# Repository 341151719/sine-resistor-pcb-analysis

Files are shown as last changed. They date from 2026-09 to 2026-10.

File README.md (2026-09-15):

# 正弦电阻 / Active Acoustic Impedance Controller

这是 PCB 修正、SPICE 分析和故障排查的审计仓库。仓库的目的，是让每次
电路修改、仿真假设和判断都能通过 Git 提交记录追溯；它不是已经通过生产
签核的最终硬件发布包。

## 先看什么

0. [新板从验收到初步改板操作手册](新板从验收到初步改板操作手册.md)：按新板版本确认、断电检查、基本上电、固件编写/烧录、问题复现和可逆改板的顺序执行。
1. [2026-09-15 实验还原证据复核](实验还原部分/主动审计/EVIDENCE_REASSESSMENT_20260915.md)：修正峰值电流与持续CC混淆，同步H07/H08状态，补充较大启动扰动验证。
2. [V8 KiCad 修正版](KICAD部分/正弦电阻V8_KiCad10.0.4_稳定性修正版_2026-09-04/)
   及其 [修改说明](KICAD部分/正弦电阻V8_KiCad10.0.4_稳定性修正版_2026-09-04/RELEASE_NOTES_V8.md)。
3. [V7 加工基线](KICAD部分/给厂商的板子加工数据/正弦电阻V7_KiCad10.0.4_校正转换版/)。
4. [SPICE 验证报告](SPICE部分/VALIDATION_REPORT_20260904.md) 和
   [实际问题记录](实际遇到的问题/)。
5. [故障假设排查总表](故障假设排查_20260908/假设总表.md)：H01–H11 记录
   单一加工/参数错误审计；H12 新增 OPA548 E/S–R5 组合动态机制审计。
6. [实验还原与可复现证据](实验还原部分/)：实板实验记录、早期错误复现和
   对既有 SPICE/KiCad 检查盲区的主动审计。

## 当前诊断状态（2026-09-08）

后续状态更新（2026-09-15）：H07修正版的3个固定偏置案例均完成且未复现目标，但不覆盖上电过程；
H08修正版未复现，但使用V8的C27值。OPA ON案例的约69 mA峰值不构成持续70 mA CC验证。
以下段落保留2026-09-08的模型结论，具体有效性以最新证据复核和更新后的假设总表为准。

官方 OPA548/OPA1656 模型在正确的 PSpice 兼容设置下可以运行。H12 进一步
解除此前“OPA548 固定 OFF”的假设，并加入 R10/TLP185、有限 E/S 状态和
J1/PGND 非理想项。23 组机制扫描没有自然产生 100--110 kHz；但当 OPA548
进入 ON 时，全官方模型出现约 453 kHz 的 U4B–R5–OPA548 组合模态，且把
R5 近似拆除后该模态消失。TP8 只有约 56 µVpp，因此仍不能解释实板上
100--110 kHz、超过 10 Vpp 的目标波形。H01–H11 的单点排查结论保持不变；
“本模型未复现”不等于已排除实物器件损坏、多故障叠加或未建模动态。

## 目录

| 目录 | 内容 |
|---|---|
| `KICAD部分/` | V7/V8 原理图、PCB、封装表、加工输出和验证记录 |
| `SPICE部分/` | SPICE 源模型、网表、脚本和历史验证报告 |
| `实际遇到的问题/` | 实测现象、局部网表和根因判定计划 |
| `故障假设排查_20260908/` | 每个假设独立存档的预测、deck、log 和审查 |
| `实验还原部分/` | 经整理的实板记录、可运行复现 deck 和主动审计脚本 |

## 复现约定

仿真通常使用 ngspice-42；TI PSpice 宏模型需要 `set ngbehavior=ps`，并且
某些官方模型需要显式 `TEMP`。每个故障目录都记录了实际命令和模型限制。
历史网表中可能保留当时机器的绝对路径，这是审计记录的一部分；在新机器
上运行前应根据目录位置调整 `.include` 路径。`.dat` 波形文件和环境安装包
没有纳入 Git，它们可由网表重新生成，避免仓库膨胀。

## 版本纪律

V7 目录作为原始加工基线保留；V8 是当前修正版工作状态，不应在没有新的
验证记录时覆盖。请用独立提交记录新的板改动、仿真假设和结论，并在
`CHANGELOG.md` 中补充面向人的摘要。

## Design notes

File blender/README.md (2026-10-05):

# V8 PCB Blender 模型与渲染

本目录提供从当前 KiCad V8 工程自动生成的 Blender 场景、脚本和渲染图。

## 输出文件

- [`output/c11_35_v8_pcb_model.blend`](output/c11_35_v8_pcb_model.blend)：可在 Blender 5.2.1 中打开的场景，包含等距相机和正视相机。
- [`output/c11_35_v8_pcb_isometric.png`](output/c11_35_v8_pcb_isometric.png)：整体等距渲染。
- [`output/c11_35_v8_pcb_top.png`](output/c11_35_v8_pcb_top.png)：正视工程布局渲染。
- [`generate_v8_pcb_scene.py`](generate_v8_pcb_scene.py)：可重复运行的生成脚本。

## 数据来源

脚本读取：

1. `KICAD部分/正弦电阻V8_KiCad10.0.4_稳定性修正版_2026-09-04/project.kicad_pcb`
   - Edge.Cuts 板框；
   - F.Cu 走线；
   - 板厚和坐标。
2. `.../audit/cpl_smt.csv`
   - 73 个贴装件的位号、位置、旋转角、正反面和封装。

本次生成结果：

- 板框：约 `116.332 mm × 112.522 mm`；
- SMT 元件：73 个；
- F.Cu 线段：715 条。

## 精度边界

这是工程可读的程序化模型，不是制造级 3D 封装模型：

- 板框、元件位置和走线来自当前 KiCad 文件；
- 电阻、电容、IC、连接器等实体使用按封装尺寸的近似几何；
- 没有把外部供应商 STEP/WRL 模型伪装成精确模型；
- 为了在渲染中看清，铜线宽度按 `VISUAL_TRACE_SCALE=1.45` 做了视觉放大，不应拿渲染图测量实际线宽；
- 当前工程文件的 `cpl_smt.csv`/BOM 仍记录 `R10=100kΩ`、`C27=10pF`，而 [V8 发布说明](../KICAD部分/正弦电阻V8_KiCad10.0.4_稳定性修正版_2026-09-04/RELEASE_NOTES_V8.md) 写的是 `R10=6.8kΩ`、`C27=10nF`。本模型忠实显示当前 KiCad/CPL 文件内容，不能作为“V8 参数已同步”的证明。

## 重新生成

在仓库根目录执行：

```bash
PROJECT_ROOT="$PWD" \
BLENDER_OUT="$PWD/blender/output" \
/path/to/blender --background --python blender/generate_v8_pcb_scene.py
```

脚本默认使用 Blender Eevee，输出 `.blend`、等距图和正视图。若从其他目录运行，设置 `PROJECT_ROOT` 指向仓库根目录即可。

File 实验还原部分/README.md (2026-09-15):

# 实验还原与可复现证据

本目录保存已经整理过、能够追溯到 KiCad 拓扑或 SPICE 运行结果的实验材料。
它不宣称已经找到实板 100–110 kHz 振荡的唯一物理根因。

## 建议阅读顺序

0. [`../新板从验收到初步改板操作手册.md`](../新板从验收到初步改板操作手册.md)：面向新板操作者的完整流程，包含版本确认、断电检查、数字域、固件/烧录、模拟上电、问题复现和可逆改板。
1. [`主动审计/EVIDENCE_REASSESSMENT_20260915.md`](主动审计/EVIDENCE_REASSESSMENT_20260915.md)：最新证据纠正、平均/峰值电流复核、较大启动扰动测试和仍待确认的物理根因。
2. [`实板实验记录.md`](实板实验记录.md)：按实际排查顺序区分有效测量、
   作废测量、已否定假设和仍待闭环的问题。
3. [`早期错误复现/`](早期错误复现/)：复现 R10/E/S 裕量、错误示波器接地
   和 OPA ON 后的电流后果，同时保留“健康模型不能产生 105 kHz”的阴性基线。
4. [`主动审计/`](主动审计/)：解释旧 SPICE 为什么可能漏检状态型错误，并提供
   网表 lint、制造数据交叉检查和 H07/H08 修正模型。
5. [`../故障假设排查_20260908/H12_OPA548_ES_R5动态耦合/`](../故障假设排查_20260908/H12_OPA548_ES_R5动态耦合/)：
   E/S–R5 动态耦合的正式假设记录和 23 组扫描。

## 证据分级

| 项目 | 状态 | 可以得出的结论 |
|---|---|---|
| V7 R10=100 kΩ 与并联 10 kΩ | 定量复现 | 官方宏模型的 0.614 V 与实测 0.55–0.65 V 相符，说明关断裕量风险真实存在 |
| 示波器地夹接 TP8 | 强等效复现 | 该接法会把 U4B 输出重载，因此对应波形和增流数据必须作废 |
| 已存在 105 kHz 时 OPA ON | 高频负载电流复现，CC 未复现 | 2 Vpk 输入的正轨峰值约 69 mA，平均仅约 23.6 mA；模型没有台式电源限流环路，不能据此判定持续 70 mA CC |
| 健康 OPA1656/OPA548 基线 | 阴性结果 | 当前模型不会自然产生实板的数伏级 100–110 kHz |
| H12 的约 453 kHz 模态 | 模型内阳性、目标阴性 | 证明 R5 可参与组合动态，但频率和 TP8 幅值都不匹配实板，不能视为根因复现 |

## 未纳入 Git 的来源材料

原始 ZIP、可再生 `.dat` 波形、补丁副本和完整对话导出没有纳入 Git：前两类会
重复或膨胀仓库；补丁已经作为正式提交应用；对话中包含被后续纠正的过渡判断、
临时路径和重复回答，不适合作为技术结论。它们保存在仓库外的本地原始归档中。

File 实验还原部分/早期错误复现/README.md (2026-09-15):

# 正弦电阻 V7：早期实验错误的 KiCad/SPICE 复现

日期：2026-09-09

证据纠正：2026-09-15，见 [重新审查报告](../主动审计/EVIDENCE_REASSESSMENT_20260915.md)。旧日志保留历史数值，新 deck 增加平均电流测量。

## 结论概览

这套测试区分“设计/测量错误能够复现”和“105 kHz 根因尚不能自然复现”。

| 项目 | 当前结论 | 关键数字 |
|---|---|---|
| V7 R10=100k 的 OPA548 E/S 关断裕量问题 | **定量复现** | 100k -> E/S-V- = 3.4786 V；9.09k -> 0.6140 V；6.8k -> 0.4634 V |
| J1 在约 +/-2.5 V 附近突然增流 | **最小官方模型未复现** | R10=100k 的简单 DC J1 sweep 没出现 70 mA 级突变 |
| OPA ON 后约 70 mA CC | **CC 尚未复现，只复现高频负载电流** | 2 Vpk/105k：正轨峰值约 69 mA，平均约 23.6 mA；缺少台式电源动态 |
| 示波器 GND 黑夹误接 TP8 | **等效故障强复现** | TP8 2.020 V -> 4.46 mV；U4B 正轨电流 3.95 mA -> 93.0 mA |
| OPA OFF、TP7 干净、TP8 数伏级 100–110 kHz | **尚未自然复现** | 健康官方模型 late TP8 = 0 Vpp；H12 V7-like 动态模型是约 453 kHz、TP8 55.7 uVpp |

## 1. KiCad 静态复核

`kicad_static_extract.py` 直接读取 V7/V8 的 `project.kicad_pcb`。

V7：

- R10 = 100kR，pad1 = OPA_ES，pad2 = PWR_N；
- R5 = 100R，连接 VCMD -> OPA_IN_P；
- U1 = OPA548F/500，pin7 = OPA_ES；
- U4 = OPA1656IDR，pin5 = MUL_RAW(TP7侧)，pin7 = VCMD(TP8)；
- U7 = TLP185，输出跨 PWR_P / OPA_ES。

V8：

- 唯一与本问题最直接相关的改变之一是 R10 变成 6.8kR；
- R5/U1/U4/U7 的上述网络关系保持不变。

注意：KiCad ERC/DRC 不会因为 `100k` 在 E/S 上“功能裕量不够”而自动报错。这属于器件行为/参数设计问题，需要 SPICE 或手工 datasheet margin check。

## 2. R10/E-S 关断问题：官方 OPA548 宏模型定量复现

文件：`01_r10_es_sweep.cir`

运行结果：

- R10=100k：`V(ES)-V(V-) = 3.478609 V`
- R10=9.0909k（100k || 10k）：`0.614035 V`
- R10=6.8k：`0.463396 V`

9.09k 的结果和实板记录的约 0.55–0.65 V 高度一致。

因此，这一项可以称为“SPICE 对早期实板问题的定量复现”。

## 3. J1 低压附近突增流：简单模型没有复现

文件：`01b_j1_sweep_r10_100k.cir`

用 R10=100k，J1 从 +/-1 V 扫到 +/-5 V。最小 OPA548 官方宏模型没有在 +/-2.5 V 附近出现 70 mA 级的突然电流跃迁。

这意味着实板当时的突然增流不能仅归结为“R10=100k + 一个空载 OPA548 DC 模型”。还需要板级负载、输入异常、E/S 动态、供电状态或其它实际条件。

适用性限制：OPA548 推荐供电最低为 ±4 V；上述 ±1～±3 V 点属于范围外探索，不能用其阴性结果排除实板低压异常。

## 4. OPA ON 后高频取电：峰值和持续 CC 必须分开

文件：`02_opa_on_105k_amp{1,2,3,4}V.cir`

这里把实板后来观测到的高频 VCMD 当作已经存在的条件，检查 OPA548 打开后的瞬时与平均取电。模型不包含电源限流控制，不能直接判定 CC。

| 105k 输入幅值 | OPA548 输出 Vpp | +轨峰值取电 | -轨峰值取电 |
|---:|---:|---:|---:|
| 1 Vpk | 2.073 Vpp | 37.8 mA | 37.2 mA |
| 2 Vpk | 4.111 Vpp | 69.1 mA | 68.7 mA |
| 3 Vpk | 6.140 Vpp | 101.0 mA | >100 mA |
| 4 Vpk | 7.209 Vpp | 132.1 mA | >100 mA |

2026-09-15 复跑 2 Vpk 案例：正/负轨平均取电约 23.62/23.48 mA，远低于其 69.14/68.75 mA 峰值。原先将这一峰值当成持续 70 mA CC 的解释，证据不足。

真实供电还包含 C5/C6=470 µF、线缆和台式电源控制环路。高频瞬时电流与电源显示/限流响应不能等同。新 deck 输出 `IP_DRAW_AVG`、`IN_DRAW_AVG`；这些平均值也只适用于当前理想电源模型，不能反过来证明实板绝不会 CC。

## 5. 错误示波器接地：强复现

文件：`03_scope_ground_short.cir`

用 TI 官方 OPA1656、R15=1k、R16=39k，把正常高阻探头与“TP8 被 50 mOhm 接地”做 A/B。

### 正常

- TP8 = 2.0196 V
- U4B +10 V rail 电流约 3.95 mA

### 示波器 GND 黑夹接 TP8 的等效情况

- TP8 = 4.46 mV，几乎被强制接地
- U4B +10 V rail 电流约 93.0 mA

因此实验里“接错探头之后 J2 电流从约 20 mA 上升到约 70 mA”完全符合这种测量人为重载机制。具体数字不要求一模一样，因为实板 J2 还给其它器件供电。

## 6. 核心 100–110 kHz：仍不能诚实地说已经复现

文件：`04_healthy_baseline.cir`

官方 OPA1656 + OPA548，R15=1k、R16=39k、R5=100R、OPA548 E/S 固定 OFF，只有一次 1mV startup kick：

- 10084 transient rows；
- late TP8_PP = 0 V；
- 没有持续 100–110 kHz。

此前 H12 动态 E/S 模型在 V7-like R10=100k、OPA548 实际 ON 条件下能够出现一个 R5 依赖的组合模态，但它是：

- 约 453.3 kHz；
- OPA548 OUT ≈ 0.140 Vpp；
- TP8 ≈ 55.7 uVpp。

它既不是 105 kHz，也不是实板的“OPA OFF、TP8 数伏级”。因此不能把它冒充根因复现。

曾经用 MOhm 级 U4 pin6 接触故障可以把 SPICE 调到约 105 kHz，但实测 pin6 到反馈节点约 20 mOhm，已经把这种模型否定，因此不应作为有效复现。

## 7. 如何运行

需要 ngspice 42，并让当前目录的 `.spiceinit` 生效。进入本目录后可运行单个
deck：

```bash
ngspice -b 01_r10_es_sweep.cir
ngspice -b 03_scope_ground_short.cir
ngspice -b 04_healthy_baseline.cir
```

也可以一次运行全部案例：

```bash
./run_all.sh
```

若 ngspice 不在 `PATH`，可使用 `NGSPICE=/绝对路径/ngspice ./run_all.sh`。
TI 模型放在 `models/`；新日志和 `.dat` 写入被 Git 忽略的 `results/`。

## 8. 当前 KiCad CLI 限制

本轮 V7/V8 KiCad 工程文件可以直接读取和静态审计，但没有重新执行
`kicad-cli ERC/DRC`。项目中已有 KiCad 10.0.4 的 ERC/DRC 结果；本报告涉及的
R10/R5/U1/U4/U7 拓扑是直接从 `project.kicad_pcb` 重新提取的。

## 9. 解释边界

`02_opa_on_105k_amp*.cir` 有意施加 105 kHz，只用于验证已经存在该波形时的
功率级电流后果。只有 `04_healthy_baseline.cir` 用于检查电路能否从一次启动
扰动中自行产生持续振荡；它的结果为阴性。两类 deck 不得混用。

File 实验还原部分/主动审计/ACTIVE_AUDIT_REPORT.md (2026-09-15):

# 正弦电阻项目：类似 R10 漏检问题的主动审计

## 结论摘要

之前 SPICE 没有发现 V7 R10=100 kΩ 的 E/S 风险，根本原因不是求解器错误，而是测试模型把关键状态预先设成了“确定 OFF”：多个基线 deck 使用理想电压源把 E/S 固定为 V-+0.6 V，或者用被动 OFF surrogate 代替 OPA548。R10/TLP185/E/S 阈值本身不在被验证系统中，因此该问题不可能被这些 deck 发现。

本次主动审计确认以下同类问题/风险：

1. **CONFIRMED / HIGH — H07/H08 OPA548 供电节点断链。**
   两个 deck 建立了 `PWR_P/PWR_N` 的 J1/PDN，但 OPA548 实例使用 `VPLUS/VMINUS`；原 deck 中没有把这两组节点连接起来，也没有给 VPLUS/VMINUS 独立供电。因此注释声称建模的 J1/OPA548 供电耦合实际上没有进入 OPA548。
2. **CONFIRMED / HIGH — H07/H08 基线 C27 仍为 10 pF。**
   V8 PCB/release 已是 10 nF。105 kHz 下两者容抗约相差 1000 倍，因此旧 H07/H08 不能作为 V8 的高频电源耦合 sign-off。
3. **CONFIRMED / PROCESS — V8 `audit/` 中间制造数据已过时，但最终 release 正确。**
   中间 audit CSV 仍可看到 R10=100 kΩ、C27=10 pF、旧 C16/R12 信息；最终 `release/V8_2026-09-04/assembly` 已正确同步。对最终 73 个 SMT 元件做 PCB↔BOM↔CPL 全量交叉检查，value/footprint/XY/rotation/side 共 0 个不一致。风险是仓库存在多个“看似可下单”的 source of truth。
4. **CONFIRMED / DESIGN-SIGNOFF — R10=6.8 kΩ 的“最坏条件”表述不成立。**
   OPA548 数据表的 E/S LOW 电流 -70 µA 位于 TYP 栏，而非 MAX 栏。6.8 kΩ 是明显优于 100 kΩ 的改进，但不能用 70 µA 声称获得 datasheet worst-case guarantee。还需要同时验证 TLP185 关断漏电和开启 CTR 对 OFF/ON 两边裕量的影响。
5. **KNOWN STATE DEPENDENCY — J5 需要外部跨接。**
   J5 的 1/2/3 脚分别是 VK_MCU/VK/VK_EXT，不内部短接。默认必须 1–2 跨接；否则关键 VK 节点可能浮空。这类问题不会被假设 VK 已驱动的 SPICE 捕获。
6. **KNOWN STATE DEPENDENCY — PB8/BOOT0 依赖 option bytes。**
   V8 没有给 PB8/BOOT0 增加硬件强下拉，release note 要求生产编程并回读 OPTR 0xFBEFF8AA。ERC/DRC/SPICE 都无法证明实际烧录状态正确。
7. **MODEL-LIMITATION — OPA548 官方宏模型不足以代表真实 shutdown 高频动态。**
   宏模型使用阈值开关表达 E/S 状态；数据表则给出典型 1 µs disable、3 µs enable，并明确提示 shutdown 器件在 >20 kHz 信号下可能增加 leakage。因此“官方宏模型 OFF 时稳定”不能单独排除实板 105 kHz 下的 OFF-state 非线性。
8. **PROCESS — 13 个 fault deck/include 把 E/S 硬固定在 V-+0.6 V；11 个用理想 ±5 V J1；14 个使用本机绝对 include 路径。**
   前两项限制了物理覆盖面，后一项降低可复现性。
9. **PROCESS — V8 release gate 的 ERC 条件是“与转换基线 436 项一致”，不是 ERC=0。**
   这是对 EasyEDA 转换噪声的务实处理，但意味着 ERC 目前不是一个干净的新电气错误报警器。

## H07/H08 修正后的复跑

修正内容：
- OPA548 `VMINUS/VPLUS` → `PWR_N/PWR_P`；
- E/S 和 ILIM 引用负轨同步改为 PWR_N；
- C27 10 pF → 10 nF；
- 仅为当前 Linux ngspice 环境修正模型 include 路径。

### H08

- C15=100 nF nominal：TP8_PP=0；OPA548 OUT_PP≈3.16e-4 V。
- C15=10 nF：同样稳定。
- C15≈open：同样稳定。

因此 H08 的定性结论“仅漏掉 U4 正轨局部 C15 不足以复现 105 kHz”在修正后仍成立。

### H07

- 原修正deck用PWL让四路理想电源同时从0 V上升；10 Ω点在未供电宏模型的初始求解中止。
- 单故障假设声明的是固定J2=±10 V、J1=±5 V。改用固定偏置后，RAPS=3.5586 mΩ/1 Ω/10 Ω均完成约0.5 ms瞬态。
- 三例TP8晚段均0 Vpp；U4+终值约9.998/9.990/9.920 V。

因此 H07 现在支持“在固定偏置和当前宏模型中，该聚合串联高阻没有产生目标振荡”。
它不覆盖上电顺序和实际电源限流，也不能把聚合RAPS定位到具体FB1、铜路或焊点。

## 建议把检查体系改成五道 gate

1. **KiCad electrical source-of-truth**：读取最终 `.kicad_pcb/.kicad_sch`，生成唯一 net/value manifest。
2. **Manufacturing parity**：每次 release 自动比较 PCB↔BOM↔CPL 的 value、footprint、XY、rotation、side；中间 `audit/` 文件不得作为下单入口。
3. **SPICE netlist lint**：检查控制脚是否被硬钳、供电节点是否断链、V8 manifest 与 deck 元件值是否漂移、绝对 include 路径。
4. **State matrix**：E/S OFF/undefined/ON、J5 jumper 缺失/正确、J1 ramp/current-limit、probe loading 等必须单独列成状态维度，不能只做“单元件 fault matrix”。
5. **Model adequacy declaration**：每个 deck 明确列出“真实建模 / surrogate / 固定假设 / 未建模”的物理机制。只有这样，`not reproduced` 才能解释为“在这些机制内被排除”，而不是“硬件问题不存在”。

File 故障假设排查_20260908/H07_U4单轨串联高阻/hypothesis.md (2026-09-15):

# H07 — U4 正电源串联路径高阻（单一故障）

**当前状态纠正**：以下为原始断链模型的历史结果。后续修正 OPA548 供电节点，
并将该单故障测试改回其声明的固定±10/±5 V偏置后，nominal、1Ω、10Ω三例均完成。
三例TP8晚段均0 Vpp，U4+约为9.998/9.990/9.920 V。结论仅适用固定偏置；
旧PWL同步上电在10Ω点失败，因此上电动态仍未得到有效结果。
参见 [修正审计](../../实验还原部分/主动审计/ACTIVE_AUDIT_REPORT.md)。

## 事前推导

原理图有 U4 正电源磁珠 FB1，标值 `150R@100MHz`（`KICAD部分/正弦电阻V8_KiCad10.0.4_稳定性修正版_2026-09-04/project.kicad_sch:37118-37142`）；原 PCB-aware 电源模型把 J2→FB1→U4 的路径拆成 `RFBP/LFBP/RAPS/LAPS`，正常 `RAPS=3.5586mΩ`、`LAPS=2.9988nH`，并在 U4 端接 C15=100nF、C11=1uF（`实际遇到的问题/opa548_shutdown_branch_spice_20260904/opa548_shutdown_branch.cir:47-54`）。FB1 焊接不良、错料或其串联铜路高阻会令 U4+ 端对高频电流呈更高阻抗；因此把已提取的 `RAPS`（不是声称某个离散电阻）从 3.5586mΩ 单独改为 1Ω、10Ω，保留所有其余电源寄生和去耦。10Ω 已是约 2.8×10³ 的高阻压力例，足以检验机制而不靠任意 105kHz 注入。

J2=±10V、J1=±5V，E/S=V−+0.6V（OFF），R5=100Ω，TP8 在 R5 前；输入仍只有 1mV/2µs 一次启动脉冲。J1 源采用 20mΩ 的数值收敛阻尼（仅在本测试 deck，非生产网表），U4 两轨均保留磁珠/走线 L、C15/C11 与负轨 C16/C10/C12。

## 模型限制

采用官方 TI OPA1656/OPA548 宏模型。OPA548 OFF 宏模型的静态电流和内部 OFF 输出状态已知不代表实物，故不以电源电流定性；本例只看 TP8、OPA548 OUT 与 U4 正轨变化。高阻参数实际注入在提取的 `RAPS` 聚合段，不能据此定位是 FB1 本体、焊点还是铜路。三例均是“单一 RAPS 参数故障”，没有与 R5、C39、R12 或焊桥叠加。

## Deck、命令与完整日志

- Deck：[H07_U4rail.cir](H07_U4rail.cir)
- PSpice 兼容设置：[.spiceinit](.spiceinit)
- 命令：`timeout 30s ngspice -b -o H07_U4rail.log H07_U4rail.cir`
- 完整日志：[H07_U4rail.log](H07_U4rail.log)

## 指标与判断

每例 `tran 0.05µs 0.5ms`，晚期窗 0.25–0.5ms。`APU4` 是 U4 正轨节点；TP8 目标是持续 100–110kHz、>10Vpp。

| RAPS | U4+ late DC/终值 | U4+ late Vpp | TP8 late Vpp | OUT late Vpp | 判断 |
|---:|---:|---:|---:|---:|---|
| 3.5586mΩ（健康） | 9.9980V | 0 | 0 | 0.49µV | 无振荡 |
| 1Ω | 9.9902V | 0 | 0.10µV | 1.0µV | 无振荡 |
| 10Ω（高阻） | 9.9200V | 0 | 0.16µV | 0.246mV | 无振荡 |

三例均跑满 0.5ms；高阻只造成约 80mV 正轨 DC 下移及微小 OUT 变化，TP8 仍约 0.02V DC、无周期。故单轨串联高阻在该官方 OFF 模型中不匹配目标 100–110kHz/>10Vpp；不排除实物电源故障与器件异常叠加，或高阻位置/频率特性不同于本聚合 RAPS。

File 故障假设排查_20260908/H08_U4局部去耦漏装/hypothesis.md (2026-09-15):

# H08 — U4 局部去耦 C15 漏装/错小（单一故障）

**当前状态纠正**：以下保留原始断链模型的历史结果。后续修正 OPA548 供电节点及
C27=10nF 后三例仍未复现目标；这使用 V8 的 C27，不能直接作为 V7 原板签核。
参见 [修正审计](../../实验还原部分/主动审计/ACTIVE_AUDIT_REPORT.md)。

## 事前推导

V8 的 C15 为实装 100nF（原理图 `KICAD部分/正弦电阻V8_KiCad10.0.4_稳定性修正版_2026-09-04/project.kicad_sch:32080-32102`）；C15 位于 U4 正电源支路，原始板级模型明确保留 J2→FB1/走线的 R/L 及 C15/C11 局部网络（`实际遇到的问题/PCB_AWARE_U4B_OFF_reduced.cir:63-85`）。若 C15 漏装，U4 端的高频旁路阻抗升高；用 C15=10nF（错小）和 1fF（近似漏装）作为同一单故障的两个压力点，C11=1uF、负轨 C16/C10/C12 均保持实装。不是用理想 U4 电源直接跨过该故障。

J2=±10V、J1=±5V、E/S=V−+0.6V（OFF）、R5=100Ω；输入只有 1mV/2µs 单次启动脉冲。J1 电源源端加 20mΩ 数值阻尼以避免理想源+电感在 t=0 的数值奇异，未改变故障路径。

## 模型限制

采用官方 TI OPA1656/OPA548 宏模型。OPA548 OFF 的宏模型电流/输出状态不是实物标定值，本项只以 U4 正轨、TP8 和 OUT 判断。C15 漏装的实际效果还取决于 FB1 的频率阻抗、布局和芯片电流谱；本 deck 的 R/L 是提取代表值，不是对任一具体磁珠批次的测量。没有叠加 C39、R5、R12、焊桥或光耦故障。

## Deck、命令与完整日志

- Deck：[H08_decoupling.cir](H08_decoupling.cir)
- PSpice 兼容设置：[.spiceinit](.spiceinit)
- 命令：`timeout 30s ngspice -b -o H08_decoupling.log H08_decoupling.cir`
- 完整日志：[H08_decoupling.log](H08_decoupling.log)

## 指标与判断

每例 `tran 0.05µs 0.5ms`，晚期窗 0.25–0.5ms；目标 TP8 是持续 100–110kHz、>10Vpp。

| C15 | U4+ 终值 | C15N 终值 | TP8 late Vpp | OUT late Vpp | 判断 |
|---:|---:|---:|---:|---:|---|
| 100nF（健康） | 9.998022V | 9.998022V | 0 | 0.49µV | 无振荡 |
| 10nF（错小） | 9.998022V | 9.998022V | 0 | 0.48µV | 无振荡 |
| 1fF（近似漏装） | 9.998022V | 9.998022V | 0 | 0.49µV | 无振荡 |

三例均完成 0.5ms，正轨无可测晚期纹波，TP8 没有周期或大幅度。故在保留真实电源 R/L、其他去耦仍在的前提下，单颗 C15 漏装/错小不匹配目标；不能外推为“所有局部去耦同时漏装”或实际电源/器件损伤的排除。

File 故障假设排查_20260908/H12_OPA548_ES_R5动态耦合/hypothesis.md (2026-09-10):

# H12 — OPA548 E/S + R5 动态耦合（组合机制）

## 为什么新增 H12

H01–H11 的统一基线把 OPA548 `E/S` 固定在 `V- + 0.6 V`（OFF）。这个前提适合排查单一错料/焊接错误，但不能回答一个不同的问题：

> V7 的 `R10=100 kΩ`、TLP185、OPA548 的有限 enable/disable 动态、R5=100 Ω 与板级寄生共同存在时，是否会打开一条此前 OFF 模型完全看不到的动态耦合路径，并自然产生实板约 100–110 kHz 的 TP8 振荡？

因此 H12 **不是新的“单一加工错误”**，而是对原模型盲区的组合机制审计。它不修改 H01–H11 的历史结论。

## 建模原则

禁止为“得到 105 kHz”而做两件事：

1. 不注入 100–110 kHz 周期源；
2. 不人为给 U4B 增加 105 kHz 极点。

主电路仍使用项目值：

- U4B：OPA1656，R15=1 kΩ，R16=39 kΩ；
- TP8 → OPA548 `+IN`：R5=100 Ω，并保留项目 PCB-aware deck 中的走线 R/L/C；
- OPA548：单位增益跟随器，R7=57.6 kΩ；
- E/S：R10=100 kΩ（V7-like，可扫 6.8 kΩ V8-like）、TLP185、R11=1 kΩ；
- J1：±5 V，470 µF + 100 nF，并显式加入供电线 R/L、ESR/ESL；
- AGND–PGND：5 mΩ + 2 nH 代理；
- 输出：R12=4.7 Ω、C4=47 nF，扬声器端默认开路。

TI OPA1656/OPA548 宏模型直接复用仓库已有副本，不在 H12 重复提交 vendor 文件。

## E/S 动态模型

官方 OPA548 宏模型的 E/S 开关接近瞬时，不适合作为 shutdown transient 的校准模型。因此 H12 在官方 OPA548 模拟核心外增加一个有限状态 wrapper：

- `V(ES)-V- <= 0.8 V`：状态向 OFF 演化；
- `V(ES)-V- >= 2.4 V`：状态向 ON 演化；
- 0.8–2.4 V：保持前一状态；
- 默认 `TON=3 µs`、`TOFF=1 µs`；
- 物理 E/S 节点保留 `R10`、参数化 `IESVAL`、pin capacitance、约 3.5 V 高端钳位代理，以及 TLP185 光电流/CCE。

`IESVAL=70 µA` 在本审计中只是参数扫描点，不应解释成 datasheet 保证最大值。

## Deck 与运行方式

- `es_dynamic_loop.cir`：TI OPA1656 + TI OPA548 的最终确认 deck。
- `es_dynamic_loop_fast.cir`：U4B 使用项目已有 ngspice-compatible surrogate，OPA548 仍为 TI 宏模型，用于 23 组机制扫描。
- `run_sweep.py`：快速扫描 R10、E/S 电流、J1 线缆电感、E/S 时延、地桥电感和一次 optocoupler enable/disable。
- `official_check/`：关键全官方宏对照 deck 和运行日志；`.dat` 波形按仓库规则不提交。
- `official_summary.csv`、`fast_sweep_summary.csv`：本次实跑摘要。

典型命令：

```bash
cd 故障假设排查_20260908/H12_OPA548_ES_R5动态耦合
mkdir -p results_h12
ngspice -b es_dynamic_loop.cir | tee official_run.log
python run_sweep.py
(cd official_check && ./run_cases.sh)
```

ngspice-42 需要本目录 `.spiceinit` 中的 PSpice 兼容设置。

## 23 组机制扫描

快速模型扫过：

- R10 = 100 kΩ / 6.8 kΩ；
- `IESVAL` = 6 / 20 / 40 / 70 µA；
- J1 cable L = 0.2 / 1 / 3 / 10 µH；
- E/S `TON/TOFF` = 1–10 µs 范围；
- AGND–PGND L = 2 / 10 / 50 nH；
- 一次 TLP185 enable/disable pulse。

结果：

**没有任何一组自然形成持续 100–110 kHz。**

快速模型中约 425 kHz 的 FFT 最大点只对应 TP8 约 `1e-9 V` 的数值残差，不能视为物理振荡。

E/S 状态对 R10/IES 很敏感：

| 条件 | `V(ES)-V-` | 状态 |
|---|---:|---|
| R10=100 kΩ, IES=70 µA | ≈3.50 V | ON |
| R10=100 kΩ, IES≈20 µA | ≈2.10 V | 未定义区/保持 |
| R10=100 kΩ, IES=6 µA（另有 dark-current proxy） | ≈0.70 V | OFF |
| R10=6.8 kΩ, IES=70 µA | ≈0.483 V | OFF |

所以不能把 `R10=100 kΩ` 简化成“必然 OFF”或“必然 ON”；它对实际 E/S 电流非常敏感。

## 全官方宏关键对照

`official_summary.csv` 的关键结果：

| case | OPA548 OUT late Vpp | 主频 | TP8 late Vpp | 解释 |
|---|---:|---:|---:|---|
| V7-like, R10=100 kΩ, E/S=ON | ≈0.140 V | ≈453.3 kHz | ≈55.7 µV | 出现组合高频模态，但不是实板 105 kHz |
| 同上，J1 近似理想 | ≈0.140 V | ≈453.3 kHz | ≈60 µV | 模态不依赖普通 J1 被动源阻抗 |
| 同上，R5≈1 MΩ（近似拆除） | 0 | 无 | 0 | 模态消失 |
| R10=100 kΩ, IES≈20 µA, E/S 未进入 ON | 0 | 无 | 0 | 无组合模态 |
| V8-like, R10=6.8 kΩ, E/S=OFF | 0 | 无 | 0 | 无组合模态 |
| OPA548 单独 ON | ≈18 µV | 数值残余 | N/A | 不是 OPA548 宏模型单独自激 |
| V7-like ON + C39=220 pF | ≈79 µV | ≈420 kHz 残余 | ≈1 nV | C39=220 pF 抑制而非拉低到 105 kHz |

这里最重要的拓扑判据是：

> 在当前全官方模型中，OPA548 必须进入 ON，并且 R5 必须连接，453 kHz 组合模态才存在。

这与 H09 不矛盾：H09 固定 OPA548 OFF，因此降低 R5 不产生变化；H12 检查的是 OFF 假设被解除后的组合路径。

## 当前判断

### 已支持

1. H01–H11 的固定 OFF 基线确实无法检验 E/S 状态切换。
2. `R10=100 kΩ` 的 E/S 工作状态对真实引脚电流高度敏感。
3. OPA548 进入 ON 后，U4B–R5–OPA548 之间存在一个需要 R5 才成立的高频组合模态。
4. 普通 J1 被动 R/L、E/S 有限时延、TLP185 动态本身没有自然生成 100–110 kHz。
5. 本模型复现的全官方组合模态约 453 kHz，不能冒充实板 105 kHz 根因。

### 尚未支持

不能据此声称“OPA548 E/S 已经解释实板 105 kHz”。如果实板 105 kHz 确实依赖 R5，还需要额外的、被实测支持的动态才能把模型频率从约 453 kHz 改到 100–110 kHz，例如器件损伤、未提取寄生、E/S 快速阈值跨越、外部周期源或真实电源主动控制环。

## 下一步实板判别

优先级高于继续盲扫 SPICE 参数：

1. 同步测 TP8 与 `TP9-TP14`（E/S 相对 V-），确认振荡时 E/S 是否跨过阈值；
2. R5 做 A-B-A：100 Ω → 拆除 → 恢复 100 Ω；
3. 若拆 R5 后 105 kHz 消失，优先继续 U1/E/S/输入回灌路径；
4. 若拆 R5 后完全不变，优先回到 U4B 本体、供电或局部焊接/损伤。

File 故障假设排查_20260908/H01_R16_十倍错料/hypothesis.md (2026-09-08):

# H01 — R16 十倍错料（39 kΩ → 390 kΩ）

## 物理错误与现有证据

R16 在 V8 BOM 为 `39.0kR`、R0805、0.1% 薄膜；其一端是 U4 pin 7
`VCMD`，另一端是 U4 pin 6 `U4B_N`。把电阻本体/料号装成 390 kΩ
是单一、常见的 decade/BOM/标识错误，同时保留所有铜连接。用户实测
U4 pin 6 到 U4B_N 约 20 mΩ，故本假设不把铜段设成开路。

## 事前计算与预测

U4B 是非反相结构，名义噪声增益

`G = 1 + R16/R15 = 1 + 39k/1k = 40`。

390 kΩ 时 `G ≈ 391`。因此相同 1 mV 启动脉冲的理想低频响应从约
40 mV 增至约 391 mV；若输入有更大偏置，先出现 DC 饱和/恢复，而不是
由电阻比例本身选择一个 100--110 kHz 频率。TP8 持续大振荡只有在该增益
变化同时触发真实相位裕量问题时才可能出现，需由晚期波形证实。

## 仅改变项与基线

只将 R16 从 39 kΩ 改为 390 kΩ；R15=1 kΩ、C39 等 DNP、R5=100 Ω、
4.7 Ω+47 nF 负载、J2/U4=±10 V、J1/OPA548=±5 V、E/S=V−+0.6 V
均保持不变。基线副本在 `../baseline_official/`；本目录内保留独立
可复跑 deck、log 和 raw trace。

## 工具与命令

ngspice-42（`/usr/bin/ngspice`），官方 TI OPA548/OPA1656 宏模型，
`.spiceinit` 使用 `set ngbehavior=ps`。从本目录运行：

```text
timeout 30s ngspice -b -o fixed_H01_R16_390k.log fixed_H01_R16_390k.cir
```

瞬态为 0.5 ms、最大步长 0.05 µs、单个 1 mV/2 µs 启动脉冲；TP8 晚段
窗口为 0.25--0.5 ms。该窗口覆盖远超 50 个 100 kHz 周期。

## 结果与工作点可信度

运行退出码为 0，约 10k 数据行，无收敛/奇异矩阵/步长失败告警。晚段
`TP8_MAX = TP8_MIN = 0.1912965 V`，故 `TP8 late Vpp = 0 V`；启动窗口
范围约 0.191296--0.510912 V。`OPA548 OUT` 晚段为常值约 −4.6373 V，
无可测零交叉频率。J1 供电电流约 −57.18/+57.18 mA，J2 约
−7.80/+7.80 mA；这些 OFF 电流与数据手册 shutdown IQ 不一致，只能作
宏模型工作点诊断，不能视为硬件电流。

## 判断

**本模型未复现。** 390 kΩ 确实放大了单次启动响应，但没有 TP8 晚期
>10 Vpp、100--110 kHz 持续振荡，也没有 DC 失控。该结果只排除“在当前
官方宏模型和此拓扑下，R16 十倍错料单独足以产生目标波形”，不排除实板
存在额外错误或官方 OFF 宏模型未覆盖的耦合。

## 下一步

不在此假设下继续盲扫。若后续要看供电条件敏感性，优先只重复同一 390 kΩ
case 的 J1=±6 V，不能将本次无振荡推断为所有轨压都安全。

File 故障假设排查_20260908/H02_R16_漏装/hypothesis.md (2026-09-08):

# H02 — R16 漏装（电阻本体开路，铜路径仍在）

## 物理错误与现有证据

V8 BOM 的 R16 是 39.0 kΩ R0805，连接 `VCMD` 与 `U4B_N`。漏贴/掉件
是可发生的 SMT 加工错误。用户已测得 U4 pin 6 到 U4B_N 约 20 mΩ，
所以这里只移除 R16 电阻本体（SPICE 以 1 TΩ 表示），不移除 pin6 到
R16 焊盘的铜连接。

## 事前计算与预测

健康反馈为 `R16=39k`、`R15=1k`、`G≈40`。R16 开路后，R15 到地的
回路也失去从输出获得的驱动；在理想有限输入偏置下，U4B 负输入由 R16
漏电/输入电流决定，闭环约束消失，输出可能爬向某一电源轨。因此首要
预测是 DC 饱和/近轨，不是有选择性的 100--110 kHz 振荡。若宏模型把
开环输入电流/输出恢复表示得不真实，仍需把饱和与数值失败分开。

## 仅改变项与基线

只将 R16 从 39 kΩ 改为 1 TΩ；R15=1 kΩ、C39 等 DNP、R5=100 Ω、
4.7 Ω+47 nF、J2/U4=±10 V、J1/OPA548=±5 V、E/S=V−+0.6 V 不变。
独立 deck、log、raw trace 均保存在本目录；健康基线副本在
`../baseline_official/`。

## 工具与命令

ngspice-42（`/usr/bin/ngspice`），官方 TI OPA548/OPA1656 模型，
`.spiceinit` 设置 `set ngbehavior=ps`。从本目录运行：

```text
timeout 30s ngspice -b -o fixed_H02_R16_1T.log fixed_H02_R16_1T.cir
```

瞬态 0.5 ms、最大步长 0.05 µs、单个 1 mV/2 µs 启动脉冲，TP8 晚段
0.25--0.5 ms，足以检测约 100 kHz 的持续周期。

## 结果与工作点可信度

运行退出码为 0，约 10k 数据行，无收敛/奇异矩阵/步长失败告警。TP8
晚段稳定约 `8.90344 V`，`TP8 late Vpp = 0 V`；启动到晚段仅有
约 8.903438--8.903485 V 的微小数值变化。`OPA548 OUT` 晚段约
−0.2952 V，无可测零交叉频率。U4 输出接近其 +10 V 轨，说明这是
失反馈后的 DC 近轨状态。

官方 OFF 宏模型工作点电流为 `i(VJ1P)≈+27.9 mA`、`i(VJ1N)≈+4.16 mA`、
`i(VJ2P)≈−39.9 mA`、`i(VJ2N)≈+7.8 mA`；OFF 电流已知不符合数据手册
shutdown IQ，只作模型诊断，不能当作实板电流。

## 判断

**本模型未复现目标；复现的是 DC 失反馈/近正轨。** R16 漏装本身可
导致异常偏置，但该 case 没有 TP8 >10 Vpp 或 100--110 kHz 持续振荡。
因此不能把“近 9 V 平台”报告成观测到的振荡，也不能据此排除实板上
叠加其他错误、器件损伤或未建模耦合。

## 下一步

不扩展同类 R16 值扫。若必须验证轨压形态，只在同一 H02 deck 复跑 J1=±6 V；
下一优先级应转向 R15、U4 邻近焊桥或供电/负载机制。

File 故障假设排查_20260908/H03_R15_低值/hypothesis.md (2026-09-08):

# H03 — R15 低值错料（首选 1 kΩ → 100 Ω）

## 物理错误与现有证据

V8 BOM 中 R15 是 `1.000kR` R0805，连接 U4 pin 6 的 `U4B_N` 到 AGND。
100 Ω 是常见 E 系列/标识或贴片料盘错误，属于只改变一个电阻本体的
可发生加工参数错误。尚无实测值证明或反驳，因此保留为待验证假设。

## 事前计算与预测

U4B 的名义非反相噪声增益为 `1 + R16/R15`。健康值为
`1 + 39k/1k = 40`；R15=100 Ω 时为 `1 + 39k/100 = 391`。
对相同 1 mV 启动脉冲，低频理想响应约从 40 mV 增至 391 mV。较低 R15
也增大反馈分压电流，但在百毫伏输入范围内仍远低于电阻功耗限制。单凭
比例变化没有 100--110 kHz 选频机制；若环路相位裕量不足，必须在 0.25--
0.5 ms 晚段观察持续振荡，若没有则只算启动放大/饱和。

## 仅改变项与基线

只将 R15 改为 100 Ω；R16=39 kΩ、C39 等 DNP、R5=100 Ω、4.7 Ω+47 nF
负载、J2/U4=±10 V、J1/OPA548=±5 V、E/S=V−+0.6 V 均不变。健康
基线副本在 `../baseline_official/`；本目录含独立 common、deck、log、
trace。

## 工具与命令

ngspice-42（`/usr/bin/ngspice`），官方 TI OPA548/OPA1656 宏模型，
`.spiceinit` 为 `set ngbehavior=ps`。从本目录运行：

```text
timeout 30s ngspice -b -o results/fixed_H03_R15_100R.log fixed_H03_R15_100R.cir
```

瞬态 0.5 ms、最大步长 0.05 µs，单个 1 mV/2 µs kick；晚期窗 0.25--
0.5 ms，包含超过 50 个 100 kHz 周期。

## 结果与工作点可信度

`fixed_H03_R15_100R.log` 以 EXIT 0 完成（约 10k 数据行），无收敛、
奇异矩阵或步长失败告警。晚段 `TP8_MAX = TP8_MIN = 0.191285 V`，故
`TP8 late Vpp = 0 V`；启动窗口为约 0.191285--0.521660 V。`U4O` 晚段
同样为常值，`U4O late Vpp = 0 V`；`OPA548 OUT` 约 −4.6373 V 常值，
晚段没有可测零交叉频率。J1 电源电流约 −57.18/+57.18 mA，J2 约
−7.806/+7.800 mA；官方 OPA548 OFF IQ 异常，这些数值只作模型工作点
诊断，不能作实板电流证据。

## 判断

**本模型未复现。** R15=100 Ω 确实放大启动响应，但在固定 J1=±5/J2=±10
场景下没有 TP8 >10 Vpp、100--110 kHz 持续波形或晚段DC继续饱和。该结论
只排除“此单一低值在当前官方宏模型/拓扑中足以产生目标”，不泛化为实板
不存在该错料。

## 下一步

只有出现 >10 Vpp 候选时才缩小最大步长并做 R5 100 Ω/开路对照；否则转到
R15 漏装或真实焊桥/供电路径，不盲扫更多电阻值。

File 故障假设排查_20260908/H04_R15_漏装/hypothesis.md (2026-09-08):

# H04 — R15 漏装（1 TΩ 等效）

## 物理错误与现有证据

R15 是 U4B_N 到 AGND 的 1 kΩ R0805。漏贴/掉件是可发生的 SMT 装配
错误；没有现有实测值证明或反驳。模型将电阻本体设为 1 TΩ，但保持
U4 pin 6、R15 焊盘和 AGND 走线的连接，不假设铜断路。

## 事前计算与预测

R15=1 kΩ 时增益 `1+39k/1k=40`。R15 开路后，R16 仍把 U4 输出连回
反相输入，但没有到地的分流；在理想低输入偏置下，U4B_N≈U4O，闭环
退化为跟随器，增益约 1（1 mV kick 仅约 1 mV 输出）。真实输入偏置/漏电
可能把输出推向某一轨，因而要分开记录 DC 漂移/饱和。该拓扑没有独立
100--110 kHz 能量源，预期是稳定跟随或 DC 漂移，不是持续大振荡。

## 仅改变项与基线

只将 R15 改为 1 TΩ；R16=39 kΩ、DNP、R5=100 Ω、4.7 Ω+47 nF、J2/U4=
±10 V、J1/OPA548=±5 V、E/S=V−+0.6 V 均不变。健康基线副本在
`../baseline_official/`；本目录含独立 common、deck、log、trace。

## 工具与命令

ngspice-42（`/usr/bin/ngspice`），官方 TI OPA548/OPA1656 宏模型，
`.spiceinit` 为 `set ngbehavior=ps`。从本目录运行：

```text
timeout 30s ngspice -b -o results/fixed_H04_R15_1T.log fixed_H04_R15_1T.cir
```

瞬态 0.5 ms、最大步长 0.05 µs、单个 1 mV/2 µs kick；晚期窗 0.25--
0.5 ms。

## 结果与工作点可信度

严格的 1 TΩ deck `fixed_H04_R15_1T.cir` 在 30 s 限时内未完成
（shell EXIT 124）。日志到达初始瞬态工作点，显示 `U4O≈0.4893 mV`
和 `TP8≈0.4893 mV`，但没有完成 0.5 ms transient、没有 late-window
数据，因此 TP8 Vpp 和频率均 **N/A**，不能将 timeout 当作振荡证据。

为区分数值条件，随后以 1 GΩ 作为“仍等效开路”的有限泄漏 proxy，命令为
`timeout 30s ngspice -b -o results/fixed_H04_R15_1G_open_proxy.log fixed_H04_R15_1G_open_proxy.cir`；
该 proxy
`fixed_H04_R15_1G_open_proxy.cir` 也在 30 s 内 timeout，仍只到初始
工作点（约 `U4O=0.4893 mV`）。这说明当前官方宏模型/该开路拓扑的
瞬态数值条件不可在本轮时间界内判定；并非证明电路振荡。官方 OPA548
OFF 静态电流异常仍不能当作实板电流。

按后续复核要求，进一步建立 `fixed_H04_R15_removed.cir`，真正删除
`R15` 元件行，仅保留 U4 pin6→R15 焊盘的铜路、焊盘寄生和 AGND 走线；
该 deck 的 `timeout 30s` 结果仍为 EXIT 124，只到初始工作点，未产生
0.5 ms 数据。因而 timeout 并非振荡或有效晚段证据。

## 判断

**未完成/不适用当前瞬态证据。** 现有结果只支持“初始工作点接近 0 V”，
不支持或反驳 TP8 晚期 >10 Vpp、100--110 kHz。由于严格 case 与数值
proxy 均超时，本项不进入“本模型未复现”计数，不能用来排除实板 R15
漏装。

## 下一步

不再继续 R15 高阻值盲扫。若必须完成该项，应另建经过验证的开路/有限
输入偏置建模或缩短拓扑后再跑；本轮转向 H05 及其余独立机制，并保持
单一错误原则。

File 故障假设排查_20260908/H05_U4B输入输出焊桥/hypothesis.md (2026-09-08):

# H05 — U4B 邻近引脚焊桥候选

## 物理核查与取舍

V8 KiCad PCB 的 U4 是 `OPA1656IDR` SOIC-8，pad net 明确为：pin 5
`MUL_RAW`（非反相输入）、pin 6 `U4B_N`（反相输入）、pin 7 `VCMD`
（输出）。pin 5、6、7 在同一排相邻，中心距 1.27 mm。一个干净的
pin5→pin7 连接需要跨过 pin6，实际焊桥很可能同时短到中间 pad，故不能
把它当作独立、邻近的“正反馈”连接。按用户授权，H05 改为最有物理根据
的相邻 pin6↔pin7 焊桥：这是反相输入到输出的直接负反馈旁路，不冒充
正反馈；pin5→pin7 只保留为未测试的低可信变体。

PCB 来源：
`KICAD部分/正弦电阻V8_KiCad10.0.4_稳定性修正版_2026-09-04/project.kicad_pcb`
的 U4 footprint，及 `.codex_stability_audit_tmp/pdn_resonance/pcb_full.json`
的 U4 pad-net 摘录。R16 本身连接 `VCMD`↔`U4B_N`，R15 连接 `U4B_N`↔
`AGND`；H05 只新增一个 pin6↔pin7 短路，不改 R15/R16。

## 事前计算与预测

健康状态为 R16/R15 非反相反馈，噪声增益 40。pin6↔pin7 短路将绕过
39 kΩ，U4B 仍以负反馈工作但趋近单位增益；预期启动响应减小且稳定，
不应产生正反馈振荡。若模型在理想 1 mΩ 桥下出现近轨，是 DC/输入偏置
或宏模型异常，应与持续 100--110 kHz 周期分开。

## 仅改变项与基线

只在 U4N（pin6）与 U4O（pin7）之间加入 1 mΩ 的单一焊桥等效电阻；
R15=1 kΩ、R16=39 kΩ、C39 等 DNP、R5=100 Ω、4.7 Ω+47 nF、J2/U4=
±10 V、J1/OPA548=±5 V、E/S=V−+0.6 V 均保持不变。健康基线副本在
`../baseline_official/`。

## 工具与命令

ngspice-42（`/usr/bin/ngspice`），官方 TI OPA548/OPA1656 模型，
`.spiceinit` 为 `set ngbehavior=ps`。从本目录运行：

```text
timeout 30s ngspice -b -o results/fixed_H05_pin6_pin7_bridge.log fixed_H05_pin6_pin7_bridge.cir
```

瞬态 0.5 ms、最大步长 0.05 µs、单个 1 mV/2 µs kick；晚期窗 0.25--
0.5 ms。需记录 TP8（不是只读 OPA548 OUT）和 U4O。

## 结果与工作点可信度

`fixed_H05_pin6_pin7_bridge.log` 以 EXIT 0 完成（约 10k 数据行），无收敛、
奇异矩阵或步长失败告警。短路旁路 R16 后，TP8 晚段稳定约 0.4893 mV，
`TP8 late Vpp = 0 V`；启动窗口约 0.3474--1.6344 mV。U4O 晚段同样
`0 Vpp`，OPA548 OUT 约 −4.6373 V 常值，晚段没有可测零交叉频率。J1
电流约 −57.18/+57.18 mA、J2 约 −7.801/+7.800 mA；官方 OPA548 OFF IQ
异常，电流只作模型工作点诊断，不能作实板证据。

## 判断

**本模型未复现。** 最近邻 pin6↔pin7 桥表现为预期的负反馈旁路/近单位增益，
没有 TP8 >10 Vpp 或 100--110 kHz 持续周期。由于 pin5→pin7 正反馈需要
跨过中间 pin6，且可能同时短接三脚，未把该低可信跨脚连接伪装成已验证
故障；实板污染或器件损伤仍未被本 case 排除。

## 下一步

仅在出现 >10 Vpp 周期候选时做更小步长和 R5 对照；否则不测试非邻近的
pin5→pin7 人工跨接，避免人为构造不符合封装几何的 105 kHz 结果。

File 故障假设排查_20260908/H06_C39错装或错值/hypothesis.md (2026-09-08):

# H06 — C39 误装或错值（单一故障）

## 事前推导

V8 原理图把 C39 标成 `22p`，但装配状态是 `DNP`（`KICAD部分/正弦电阻V8_KiCad10.0.4_稳定性修正版_2026-09-04/project.kicad_sch:38869-38900`、`:38989-39004`）。原始提取网表因此只给 C39 焊盘对 VCMD/U4B_N 的 `0.05pF` 寄生（`实际遇到的问题/PCB_AWARE_full_extracted_loop.cir:898-904`）。C39 若被误装，正好跨 R16=39k 的反馈支路；22p 的一阶数量级为 `1/(2π·39k·22p)=186kHz`，在 105kHz 时 `|Xc|≈69kΩ`，与 39k 并联后约 31kΩ，足以改变环路幅相，故是可证伪的物理候选。220p 是同一故障族的错料压力例（不把它当 BOM 事实）。

基线是五个 DNP 焊盘各保留 0.05pF、C39=0.05pF；两种故障例只改变 C39 本体为 22pF 或 220pF。J2=±10V、J1=±5V、E/S=V−+0.6V（OFF），TP8 取 U4 输出/R5 前节点；只施加 1mV、2µs 单次启动脉冲，不注入 105kHz。

## 模型限制

使用官方 TI `OPA1656.LIB` 与 `OPA548.LIB`；官方宏模型的 OFF 工作点电流已在官方核查中证明不等于实物 shutdown-IQ，故仅比较 TP8/OUT 波形，不能用电源电流判定硬件。此 deck 没有 TLP185/R10 的动态光耦模型，而是用理想 E/S OFF 电压固定状态隔离该单故障；因此只回答“C39 单独能否在该环路中激发目标”，不能回答 R10 失效组合。

## Deck、命令与完整日志

- Deck：[H06_C39.cir](H06_C39.cir)
- PSpice 兼容设置：[.spiceinit](.spiceinit)
- 命令（每个初始 case 30s 上限；同一 deck 顺序跑 3 个 case）：
  `timeout 30s ngspice -b -o H06_C39.log H06_C39.cir`
- 完整日志：[H06_C39.log](H06_C39.log)

## 指标与判断

每例 `tran 0.05µs 0.5ms`，晚期窗为 0.25–0.5ms，目标为 TP8 持续 100–110kHz 且 >10Vpp。

| C39 | TP8 late Vpp | OUT late Vpp | TP8 early max/min | 结论 |
|---:|---:|---:|---:|---|
| 0.05pF（DNP基线） | 0 | 0 | 62.410mV / 16.905mV | 无持续振荡 |
| 22pF（原理图值误装） | 0 | 0 | 54.630mV / 19.570mV | 无持续振荡 |
| 220pF（错料压力例） | 0 | 0 | 28.605mV / 19.570mV | 无持续振荡 |

三例均完成约 0.5ms 瞬态；晚期 TP8 固定约 19.570mV，未测到周期，更没有 10Vpp。C39 会改变启动脉冲衰减，但在官方 OFF 模型和给定拓扑下不能解释目标故障。该负结果不能排除“C39 与其他故障组合”或实际 U4/OPA548 状态差异。

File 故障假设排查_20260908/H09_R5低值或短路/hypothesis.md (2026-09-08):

# H09 — R5 错小/短路（单一故障）

## 事前推导

PCB 提取网表把 R5 放在 VCMD/TP8 与 OPA548 `+IN` 之间，标值 100Ω（`实际遇到的问题/PCB_AWARE_full_extracted_loop.cir:897-905`；简化官方 deck 也明确 TP8 在 R5 前、R5=100Ω，`稳定性原因分析CODEX/.codex_stability_audit_tmp/fault_injection_round1/fault_fixed_common.inc:51-59`）。R5 若贴错低值或焊锡短路，OPA548 输入 rail clamp、输入电容与 U4 输出反馈的负载会改变；官方宏已显示输入钳位存在，因此这是可证伪的单故障。测试 100Ω（健康）、10Ω（错小）和 1mΩ（短路的数值近似），只改 R5，R16=39k、C39 均维持基线。

J2=±10V、J1=±5V、E/S=V−+0.6V（OFF），输出保留 4.7Ω+47nF 负载；只有 1mV/2µs 一次启动脉冲，不注入 105kHz。

## 模型限制

使用官方 TI OPA1656/OPA548 宏模型和既有 `fault_fixed_common.inc`。官方 OPA548 OFF 供电电流/输出静态点已知不具备实物校准意义，故不以其电流排除 R5。这个 deck 没有把 R5 与输入焊桥叠加；H05 另行测试 U4 输入/输出桥。1mΩ 仅是 SPICE 避免零欧奇异的短路表示。

## Deck、命令与完整日志

- Deck：[H09_R5.cir](H09_R5.cir)
- PSpice 兼容设置：[.spiceinit](.spiceinit)
- 命令：`timeout 30s ngspice -b -o H09_R5_local.log H09_R5.cir`
- 复核日志：[H09_R5_local.log](H09_R5_local.log)（旧绝对 include 版本
  `H09_R5.log` 也保留作原始记录；复核版改为子目录内同一 common）。

## 指标与判断

每例 `tran 0.05µs 0.5ms`，晚期窗 0.25–0.5ms；目标 TP8 为持续 100–110kHz 且 >10Vpp。

| R5 | TP8 late Vpp | OUT late Vpp | OPA548 +IN late Vpp | TP8/IN 终值 | 判断 |
|---:|---:|---:|---:|---:|---|
| 100Ω（健康） | 0 | 0 | 0 | 19.5701mV / 19.5701mV | 无振荡 |
| 10Ω（错小） | 0 | 0 | 0 | 19.5701mV / 19.5701mV | 无振荡 |
| 1mΩ（近似短路） | 0 | 0 | 0 | 19.5701mV / 19.5701mV | 无振荡 |

三例均跑满 0.5ms；在此 OFF 宏模型中降低 R5 没有改变 TP8、输入或 OUT 的晚期波形，完全不匹配目标。不能据此证明实物 R5 一定无故障：实物 OPA548 OFF 输入保护/损伤、瞬态电源阻抗或与其他故障组合未由本模型覆盖。

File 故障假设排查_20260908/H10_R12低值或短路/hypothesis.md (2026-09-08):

# H10 — R12 隔离电阻低值/短路（单一故障）

## 事前推导

PCB 网表中 R12 串在 OPA548 输出 DRV 与 47nF C4 之间，标值 4.7Ω（`实际遇到的问题/PCB_AWARE_full_extracted_loop.cir:907-910`；原始关断分支也保留该输出网络，`实际遇到的问题/opa548_shutdown_branch_spice_20260904/opa548_shutdown_branch.cir:121-129`）。在 105kHz，47nF 的容抗约 32Ω；R12 若错小/短路，会去掉约 4.7Ω 的串联阻尼，可能改变输出级/电容负载的 Q 值。测试 4.7Ω（健康）、0.47Ω（错小）和 1mΩ（短路的 SPICE 近似），只改 R12，C4=47nF、R5=100Ω、R16=39k 均不变。

J2=±10V、J1=±5V、E/S=V−+0.6V（OFF），TP8 在 R5 前；只施加 1mV/2µs 单次启动脉冲，不注入 105kHz。

## 模型限制

采用官方 TI OPA1656/OPA548 宏模型。OFF 宏模型输出不是实物无限阻抗，且其 shutdown 电流已知不能作硬件标定；本项只检查 R12/C4 在 OFF 端接入时是否会把振荡传回 TP8。为保持与 H01–H05 官方公共核一致，本 deck 没有加入完整提取网表中的 R46/RSH2/R6 及 D1/D2（这些元件位于 `PCB_AWARE_full_extracted_loop.cir:905-910、921-923`），所以结论对完整输出反馈/钳位网络是假阴性风险更高的条件结论。没有叠加 ON 状态、R5 故障、C39 故障或焊桥。1mΩ 是避免零欧理想短路数值问题的近似。

## Deck、命令与完整日志

- Deck：[H10_R12.cir](H10_R12.cir)
- PSpice 兼容设置：[.spiceinit](.spiceinit)
- 命令：`timeout 30s ngspice -b -o H10_R12.log H10_R12.cir`
- 完整日志：[H10_R12.log](H10_R12.log)

## 指标与判断

每例 `tran 0.05µs 0.5ms`，晚期窗 0.25–0.5ms；目标 TP8 是持续 100–110kHz、>10Vpp。

| R12 | TP8 late Vpp | OPA548 OUT late Vpp | C4 节点 SNUB late Vpp | 终值 OUT |
|---:|---:|---:|---:|---:|
| 4.7Ω（健康） | 0 | 0 | 0 | −4.637307V |
| 0.47Ω（错小） | 0 | 0 | 0 | −4.637307V |
| 1mΩ（近似短路） | 0 | 0 | 0 | −4.637307V |

三例均跑满 0.5ms，R12 变化没有在 OFF 官方宏模型中激发任何持续波形，完全不匹配目标。该负结果只说明“R12 单独 + OFF 宏模型”不成立；实物 ON 输出级、器件损伤或与电源/反馈故障组合仍需实测，不能由此排除板上 R12 故障。

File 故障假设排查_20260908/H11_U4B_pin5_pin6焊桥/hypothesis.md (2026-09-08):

# H11 — U4B pin5↔pin6 输入差分焊桥

## 物理错误与现有证据

U4 的 SOIC-8 pad-net 来自 V8 PCB：pin5=`MUL_RAW`（U4B 非反相输入）、
pin6=`U4B_N`（反相输入）、pin7=`VCMD`（输出）。pin5 与 pin6 中心距
1.27 mm、相邻，故 pin5↔pin6 的锡桥/污染比跨中间脚的 pin5↔pin7
更符合封装几何。没有现有实测值确认或反驳该桥；用户已确认的 pin6→
U4B_N 20 mΩ 连续性不涉及该短路。

## 事前计算与预测

健康 U4B 反馈为 R16=39 kΩ、R15=1 kΩ，噪声增益约40。pin5 与 pin6
直接短接后，差分输入电压被强制为近零；该错误不是正反馈，输出只能由
输入失调/偏置和宏模型保护状态决定，预期是接近某个DC值、饱和或启动
瞬态，而不是凭空形成100--110 kHz。只有晚段 TP8出现稳定周期且>10 Vpp
才支持目标；饱和必须单独报告。

## 仅改变项与基线

只在 U4P（pin5）与 U4N（pin6）之间加入 1 mΩ 的单一焊桥等效电阻；
R15/R16、DNP 电容、R5=100 Ω、4.7 Ω+47 nF、J2/U4=±10 V、J1/OPA548=
±5 V、E/S=V−+0.6 V 均保持不变。健康基线副本在
`../baseline_official/`，common 与 deck 在本目录独立保存。

## 工具与命令

ngspice-42（`/usr/bin/ngspice`），官方 TI OPA1656/OPA548 宏模型，
`.spiceinit` 为 `set ngbehavior=ps`。从本目录运行：

```text
timeout 30s ngspice -b -o results/fixed_H11_pin5_pin6_bridge.log fixed_H11_pin5_pin6_bridge.cir
```

瞬态0.5 ms、最大步长0.05 µs、单个1 mV/2 µs启动kick；TP8为R5前节点，
晚段窗0.25--0.5 ms。

## 结果与工作点可信度

`fixed_H11_pin5_pin6_bridge.log` 以 EXIT 0 完成（约10k数据行），无收敛、
奇异矩阵或步长失败告警。TP8 晚段稳定约 `8.897189 V`，`TP8 late Vpp =
0 V`；启动窗口约 8.897189--8.897190 V。U4O 晚段同样为0 Vpp，OPA548
OUT 晚段约 −0.2953 V，未出现可测零交叉频率。U4 输出因此是近正轨的
DC状态，而非持续振荡。

最终宏模型电流约 `i(VJ1P)=+27.85 mA`、`i(VJ1N)=+4.16 mA`、
`i(VJ2P)=−40.04 mA`、`i(VJ2N)=+7.80 mA`。OPA548 OFF IQ 已知异常，
这些电流仅作工作点诊断，不作实板电流证据。

## 判断

**本模型未复现目标。** 与H05的pin6↔pin7（负反馈旁路）不同，本项相邻
输入差分短路导致U4近+10V平坦DC；没有TP8 >10Vpp或100--110kHz持续周期。
这只约束当前官方宏模型/拓扑，不能排除实板桥接后器件损伤或其他组合。

## 下一步

除非出现>10 Vpp候选，否则不再组合多个焊桥或人为跨脚；必要时只做更小
步长复核该单一连接。

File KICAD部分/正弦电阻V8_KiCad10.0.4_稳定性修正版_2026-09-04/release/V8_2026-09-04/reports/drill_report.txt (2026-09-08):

Drill report for project.kicad_pcb
Created on 2026-09-04T19:59:30

Copper Layer Stackup:
    =============================================================
    L1 :  Top Layer                 front
    L2 :  Bottom Layer              back

Drill file 'project-PTH.drl' contains
    plated through holes:
    =============================================================
    T1  0.457mm  0.0180"  (65 holes))
    T2  0.650mm  0.0256"  (5 holes))
    T3  0.700mm  0.0276"  (20 holes))
    T4  0.762mm  0.0300"  (12 holes))
    T5  0.850mm  0.0335"  (10 holes))
    T6  0.914mm  0.0360"  (12 holes))
    T7  1.020mm  0.0402"  (10 holes))
    T8  1.067mm  0.0420"  (13 holes))
    T9  1.219mm  0.0480"  (72 holes))

    Total plated holes count 219

Drill file 'project-NPTH.drl' contains
    unplated through holes:
    =============================================================

    Total unplated holes count 0

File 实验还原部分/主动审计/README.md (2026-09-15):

# 主动审计复现入口

本目录检查的不是“某个 SPICE deck 是否成功结束”，而是模型是否真的包含它
声称检查的物理状态和网络。

主要内容：

- `EVIDENCE_REASSESSMENT_20260915.md`：修正峰值取电与持续 CC 混淆、证据因果推断和历史状态冲突。
- `reassess_evidence.py`：复跑四组平均/峰值电流、105 kHz 增益和四组较大启动扰动，并检查测量是否存在及有效。
- `ACTIVE_AUDIT_REPORT.md`：最终审计结论和解释边界；
- `spice_static_lint.py`：查找 E/S 硬钳、旧 C27/R10、绝对 include 路径和
  OPA548 供电节点断链特征；
- `release_assembly_crosscheck.py`：比较最终 V8 release 的 PCB、BOM 和 CPL；
- `corrected_decks/`：修正 OPA548 供电节点与 C27 后的 H07/H08 网表和历史日志；
- `run_checks.sh`：在当前仓库重新生成检查结果。

运行：

证据复核使用 `python3 reassess_evidence.py`（可从任意目录通过脚本路径运行）。
默认使用 ngspice-42，支持 `NGSPICE` 指定可执行文件；输出位于被忽略的
`results_reassessment/`，含生成的诊断 deck、日志与 `summary.json`。
生成的 deck 使用早期复现目录中的相对模型路径，手工复跑需以该目录为工作目录。
每个案例限时 60 秒；超时、缺失测量、非有限值或错误返回均失败，失败时 summary 不保留旧成功状态。

历史主动审计使用：

```bash
./run_checks.sh
```

若 ngspice 不在 `PATH`：

```bash
NGSPICE=/绝对路径/ngspice ./run_checks.sh
```

生成内容写入被 Git 忽略的 `results/`。H07 现在覆盖固定±10/±5 V偏置，
3.5586 mΩ/1 Ω/10 Ω三例均有完整结果；上电顺序仍在该deck范围之外。
`run_checks.sh`会检查失败字样、案例数和数据块数；ngspice退出0不再单独视为通过。

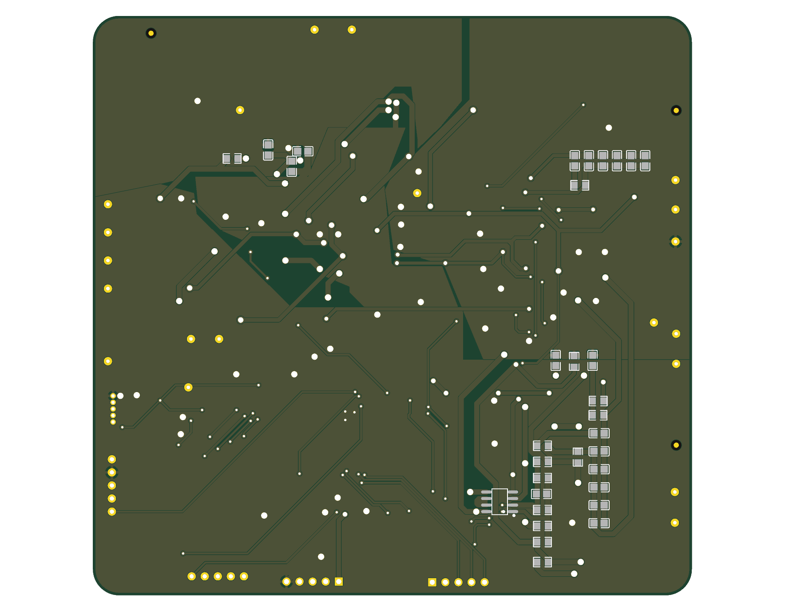
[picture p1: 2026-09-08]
KICAD部分/正弦电阻V8_KiCad10.0.4_稳定性修正版_2026-09-04/release/V8_2026-09-04/reports/pcb_bottom.png

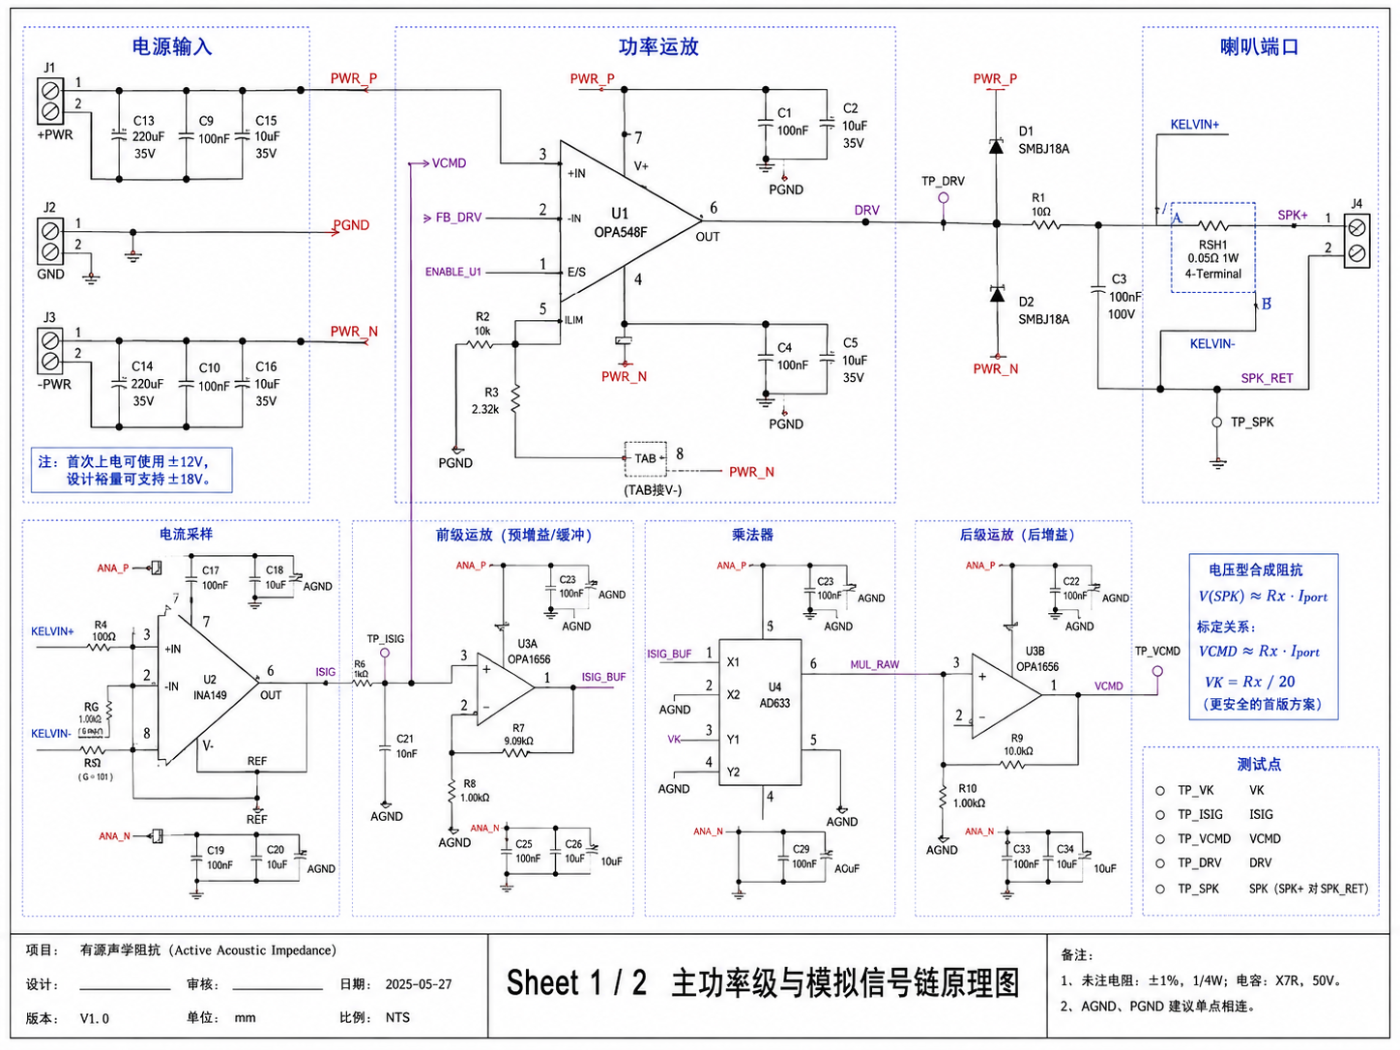
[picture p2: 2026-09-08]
SPICE部分/validation_workspace_20260904_19wI9s/requirements/ChatGPT Image 2026年5月28日 19_50_29.png

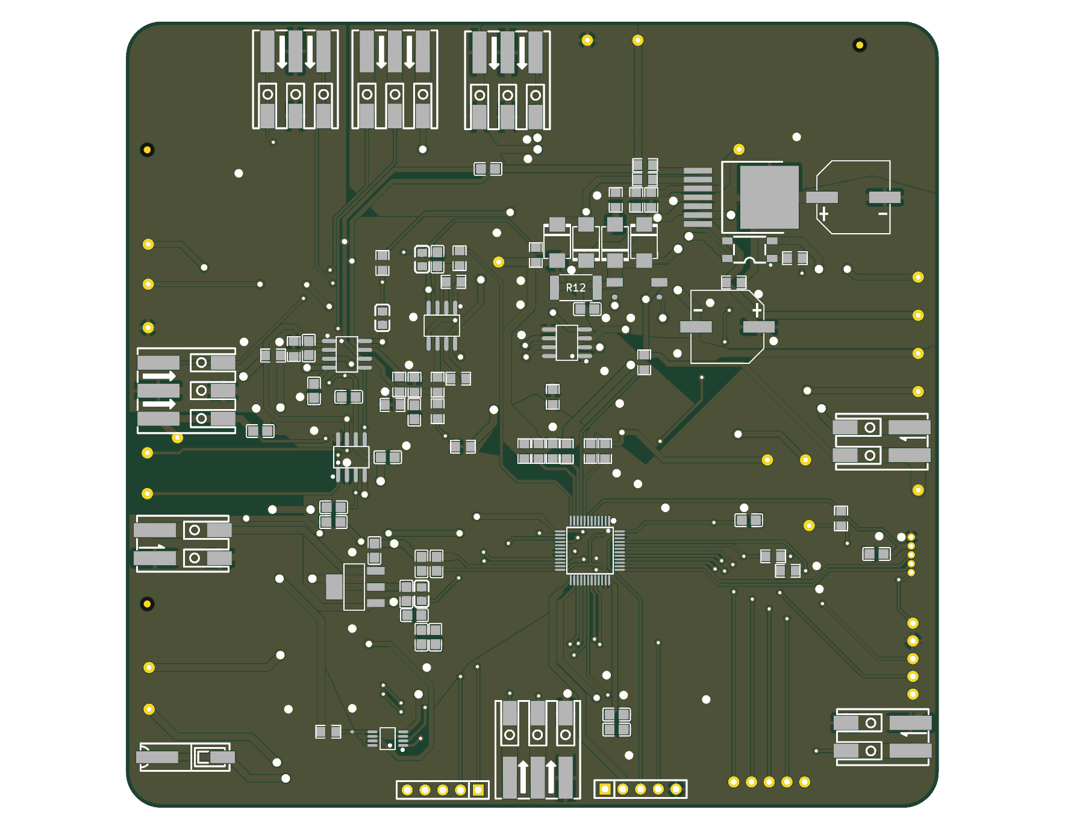
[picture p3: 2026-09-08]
KICAD部分/正弦电阻V8_KiCad10.0.4_稳定性修正版_2026-09-04/release/V8_2026-09-04/reports/pcb_top.png

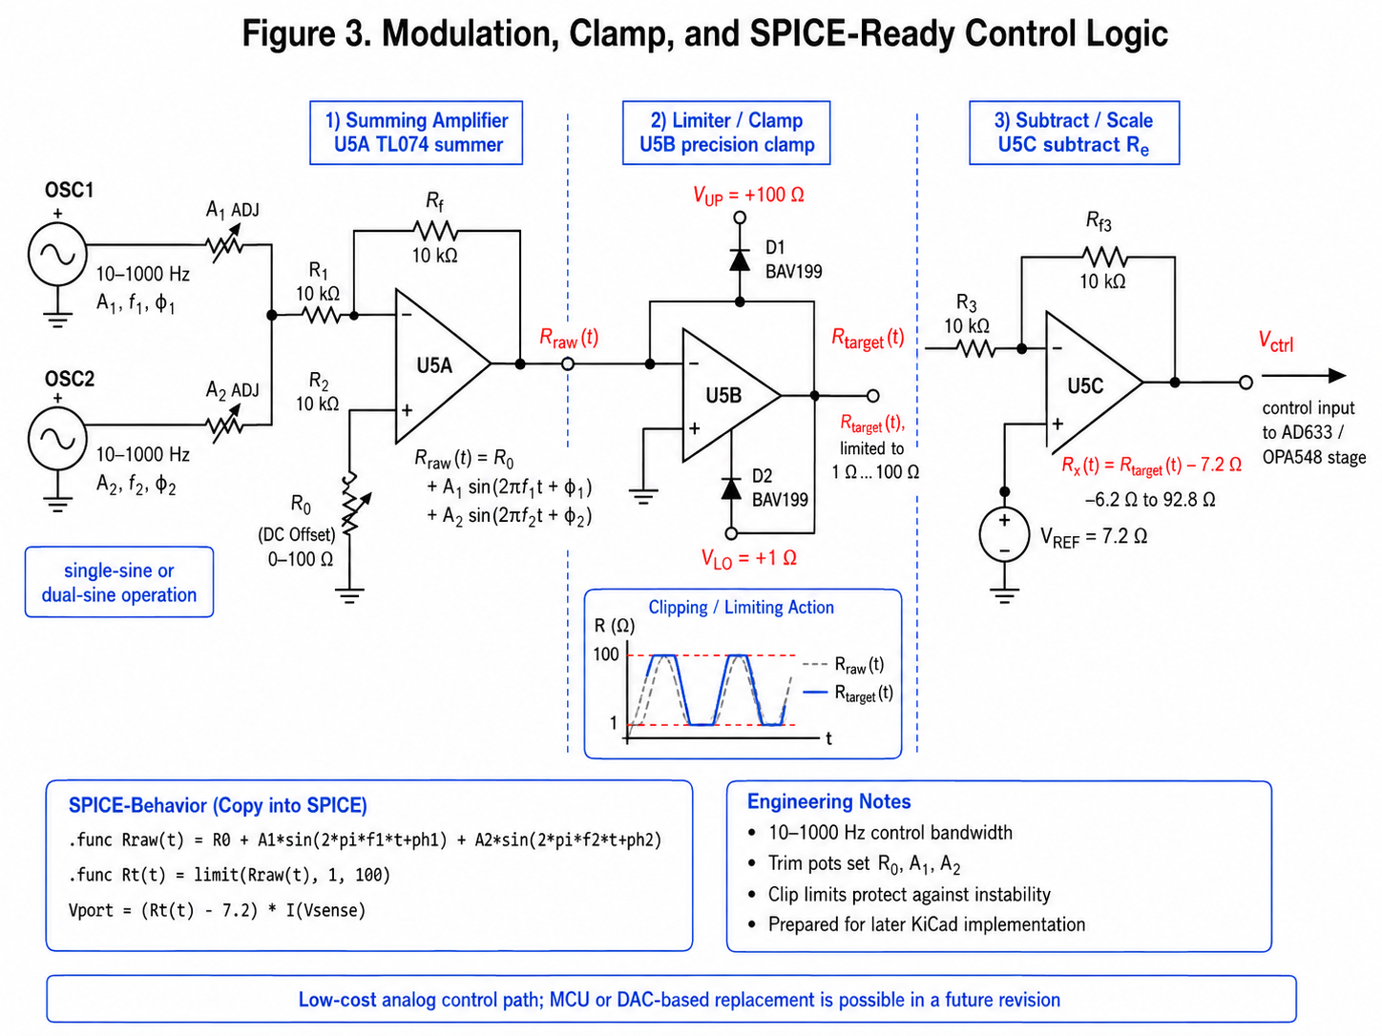
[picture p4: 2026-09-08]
SPICE部分/validation_workspace_20260904_19wI9s/requirements/ChatGPT Image 2026年5月18日 16_06_45.png

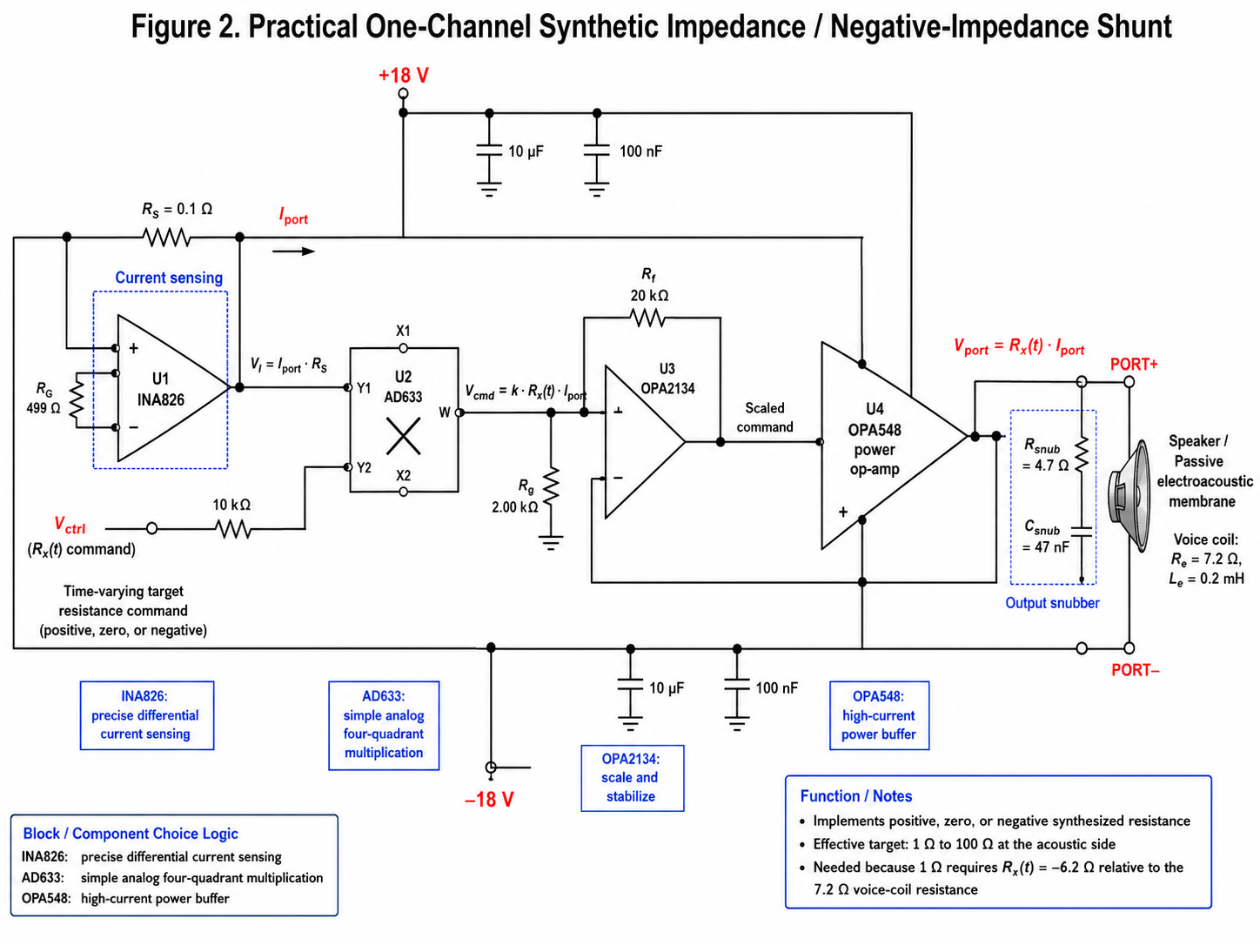
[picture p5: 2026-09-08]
SPICE部分/validation_workspace_20260904_19wI9s/requirements/ChatGPT Image 2026年5月18日 16_05_34.png

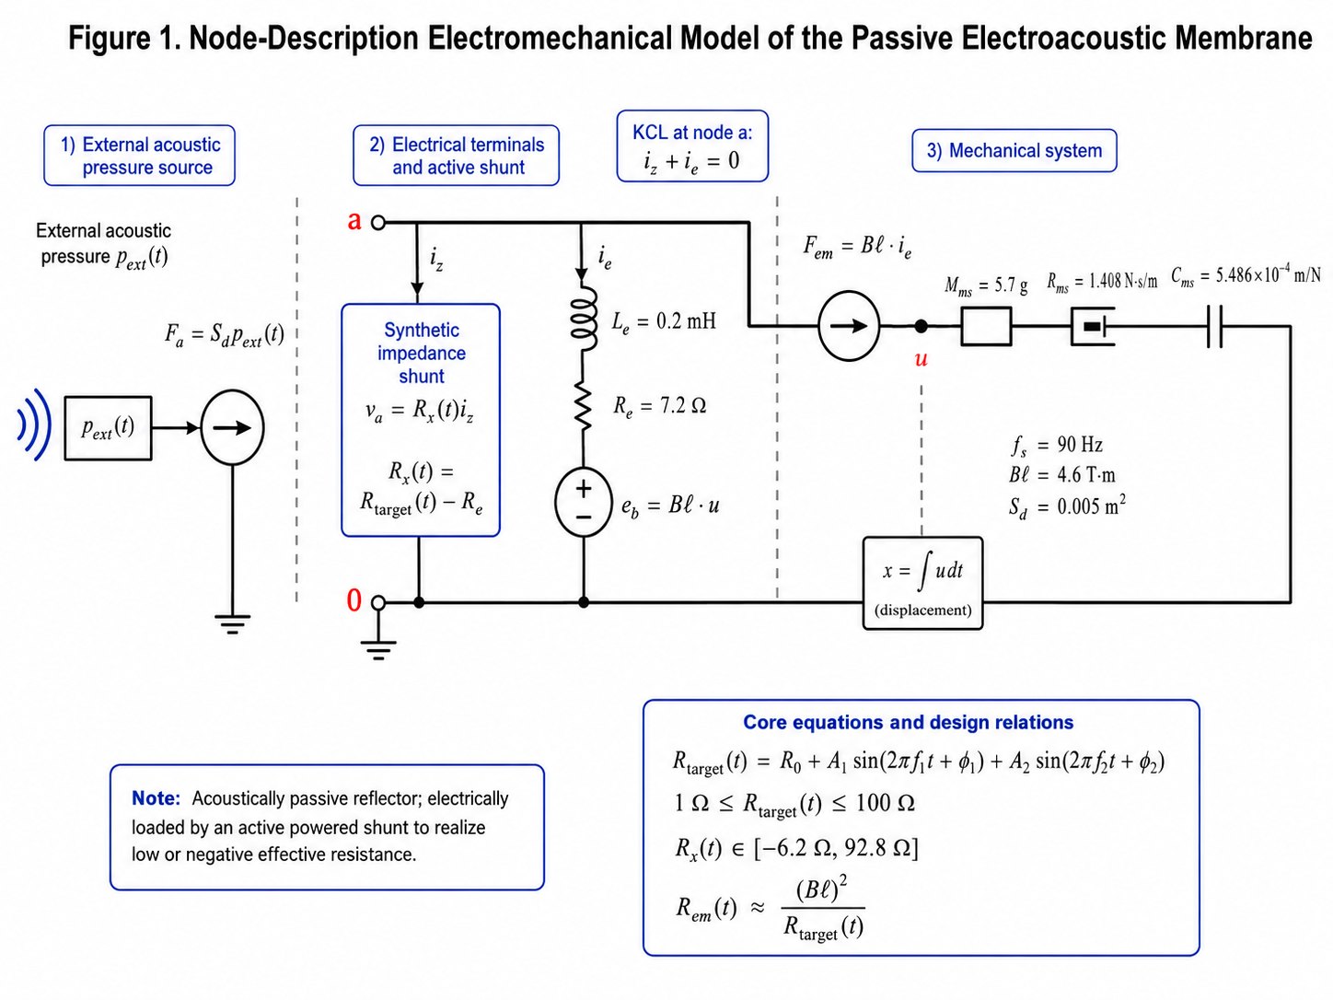
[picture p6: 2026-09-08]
SPICE部分/validation_workspace_20260904_19wI9s/requirements/ChatGPT Image 2026年5月18日 16_04_13.png

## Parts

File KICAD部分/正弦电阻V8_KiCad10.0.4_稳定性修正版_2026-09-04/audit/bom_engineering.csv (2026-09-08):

Refs | Value | Footprint | Qty | DNP | Assembly Status | LCSC Part # | BOM Value
C1 | 10uF | easyedapro:C0805 | 1 |  | SMT | C15850 | 10µF ±10% 25V X5R
C2 | 10uF | easyedapro:C0805 | 1 |  | SMT | C15850 | 10µF ±10% 25V X5R
C3 | 100nF | easyedapro:C0805 | 1 |  | SMT | C49678 | 100nF ±10% 50V X7R
C4 | 47nF | easyedapro:C0805 | 1 |  | SMT | C1845663 | 47nF ±5% 50V X7R
C5 | 470uF | easyedapro:CAP-SMD_BD10.0-L10.3-W10.3-LS11.3-FD | 1 |  | SMT | C2992611 | 470µF ±20% 35V, 105°C
C6 | 470uF | easyedapro:CAP-SMD_BD10.0-L10.3-W10.3-LS11.3-FD | 1 |  | SMT | C2992611 | 470µF ±20% 35V, 105°C
C7 | 100nF | easyedapro:C0805 | 1 |  | SMT | C49678 | 100nF ±10% 50V X7R
C8 | 100nF | easyedapro:C0805 | 1 |  | SMT | C49678 | 100nF ±10% 50V X7R
C9 | 100nF | easyedapro:C0805 | 1 |  | SMT | C49678 | 100nF ±10% 50V X7R
C10 | 100nF | easyedapro:C0805 | 1 |  | SMT | C49678 | 100nF ±10% 50V X7R
C11 | 1uF | easyedapro:C0805 | 1 |  | SMT | C344178 | 1µF ±10% 50V X7R
C12 | 1uF | easyedapro:C0805 | 1 |  | SMT | C344178 | 1µF ±10% 50V X7R
C13 | 1p/2.2p/4.7p EXP | easyedapro:C0805 | 1 | DNP | DNP |  | DNP；实验备料1pF/2.2pF/4.7pF C0G 0805
C14 | 1p/2.2p/4.7p EXP | easyedapro:C0805 | 1 | DNP | DNP |  | DNP；实验备料1pF/2.2pF/4.7pF C0G 0805
C15 | 100nF | easyedapro:C0805 | 1 |  | SMT | C49678 | 100nF ±10% 50V X7R
C16 | 100nF | easyedapro:C0805 | 1 |  | SMT | C49678 | 100nF ±10% 50V X7R
C17 | 10nF | easyedapro:C0805 | 1 |  | SMT | C342877 | 10nF ±5% 50V C0G
C18 | 100nF | easyedapro:C0805 | 1 |  | SMT | C49678 | 100nF ±10% 50V X7R
C19 | 100nF | easyedapro:C0805 | 1 |  | SMT | C49678 | 100nF ±10% 50V X7R
C20 | 100nF | easyedapro:C0805 | 1 |  | SMT | C49678 | 100nF ±10% 50V X7R
C21 | 100nF | easyedapro:C0805 | 1 |  | SMT | C49678 | 100nF ±10% 50V X7R
C22 | 100nF | easyedapro:C0805 | 1 |  | SMT | C49678 | 100nF ±10% 50V X7R
C23 | 220nF | easyedapro:C0805 | 1 |  | SMT | C45359963 | 220nF ±10% 50V X7R
C24 | 4.7uF | easyedapro:C0805 | 1 |  | SMT | C380342 | 4.7µF ±10% 16V X5R
C25 | 1uF | easyedapro:C0805 | 1 |  | SMT | C344178 | 1µF ±10% 50V X7R
C26 | 100nF | easyedapro:C0805 | 1 |  | SMT | C49678 | 100nF ±10% 50V X7R
C27 | 10pF | easyedapro:C0805 | 1 |  | SMT | C157608 | 10pF ±5% 50V C0G
C28 | 1uF | easyedapro:C0805 | 1 |  | SMT | C344178 | 1µF ±10% 50V X7R
C29 | 1uF | easyedapro:C0805 | 1 | DNP | DNP |  | 1uF
C30 | 1uF | easyedapro:C0805 | 1 | DNP | DNP |  | 1uF
C31 | 4.7p | easyedapro:C0805 | 1 | DNP | DNP |  | 4.7p
C32 | 10p | easyedapro:C0805 | 1 | DNP | DNP |  | 10p
C33 | 22p | easyedapro:C0805 | 1 | DNP | DNP |  | 22p
C34 | 47p | easyedapro:C0805 | 1 | DNP | DNP |  | 47p
C35 | 100p | easyedapro:C0805 | 1 | DNP | DNP |  | 100p
C36 | 10p-100p | easyedapro:C0805 | 1 | DNP | DNP |  | 10p-100p
C37 | 4.7p | easyedapro:C0805 | 1 | DNP | DNP |  | 4.7p
C38 | 10p | easyedapro:C0805 | 1 | DNP | DNP |  | 10p
C39 | 22p | easyedapro:C0805 | 1 | DNP | DNP |  | 22p
C40 | 47p | easyedapro:C0805 | 1 | DNP | DNP |  | 47p
C41 | 100p | easyedapro:C0805 | 1 | DNP | DNP |  | 100p
C42 | 10p-100p | easyedapro:C0805 | 1 | DNP | DNP |  | 10p-100p
D1 | SS56B | easyedapro:SMB_L4.3-W3.6-LS5.4-RD | 1 |  | SMT | C14651 | SS56B, 60V 5A Schottky
D2 | SS56B | easyedapro:SMB_L4.3-W3.6-LS5.4-RD | 1 |  | SMT | C14651 | SS56B, 60V 5A Schottky
D3 | SS56 +clamp SPK DNP | easyedapro:SMB_L4.3-W3.6-LS5.4-RD | 1 | DNP | DNP |  | SS56 +clamp SPK DNP
D4 | SS56 -clamp SPK DNP | easyedapro:SMB_L4.3-W3.6-LS5.4-RD | 1 | DNP | DNP |  | SS56 -clamp SPK DNP
FB1 | 150R@100MHz | easyedapro:L0805 | 1 |  | SMT | C139474 | 150Ω@100MHz, 600mA, DCR 0.25Ω
FB2 | 150R@100MHz | easyedapro:L0805 | 1 |  | SMT | C139474 | 150Ω@100MHz, 600mA, DCR 0.25Ω
FB3 | 150R@100MHz | easyedapro:L0805 | 1 |  | SMT | C139474 | 150Ω@100MHz, 600mA, DCR 0.25Ω
J1 | WAGO 2060 3P | easyedapro:CONN-SMD_2060-453 | 1 |  | SMT | C2765056 | WAGO 2060 3P, 4mm pitch
J2 | WAGO 2060 3P | easyedapro:CONN-SMD_2060-453 | 1 |  | SMT | C2765056 | WAGO 2060 3P, 4mm pitch
J3 | WAGO 2060 2P | easyedapro:CONN-SMD_2060-452 | 1 |  | SMT | C2765055 | WAGO 2060 2P, 4mm pitch
J4 | WAGO 2060 2P | easyedapro:CONN-SMD_2060-452 | 1 |  | SMT | C2765055 | WAGO 2060 2P, 4mm pitch
J5 | WAGO 2060 3P | easyedapro:CONN-SMD_2060-453 | 1 |  | SMT | C2765056 | WAGO 2060 3P, 4mm pitch
J6 | WAGO 2060 3P | easyedapro:CONN-SMD_2060-453 | 1 |  | SMT | C2765056 | WAGO 2060 3P, 4mm pitch
J8 | WAGO 2060 3P | easyedapro:CONN-SMD_2060-453 | 1 |  | SMT | C2765056 | WAGO 2060 3P, 4mm pitch
J9 | WAGO 2060 2P | easyedapro:CONN-SMD_2060-452 | 1 |  | SMT | C2765055 | WAGO 2060 2P, 4mm pitch
J10 | EXP_SPI_TIM_DNP | easyedapro:AAI_C11_35_LOCAL_Footprints_AAI_PinHeader_1x05_P2_54mm_Vertical | 1 | DNP | DNP |  | EXP_SPI_TIM_DNP
J11 | EXP_I2C_DAC_DNP | easyedapro:AAI_C11_35_LOCAL_Footprints_AAI_PinHeader_1x05_P2_54mm_Vertical | 1 | DNP | DNP |  | EXP_I2C_DAC_DNP
J12 | 1×5P 2.54mm母排 | easyedapro:HDR-TH_5P-P2.54-V-F | 1 |  | POST | C50950 | 1×5P 2.54mm母排
J13 | 1×5P 2.54mm母排 | easyedapro:HDR-TH_5P-P2.54-V-F | 1 |  | POST | C50950 | 1×5P 2.54mm母排
J14 | WAGO 2060 1P | easyedapro:CONN-SMD_L12.7-W3.9_2060-451-998-404 | 1 |  | SMT | C2765054 | WAGO 2060 1P, 4mm pitch
R1 | 0R | easyedapro:R0805 | 1 | DNP | DNP |  | 0R
R2 | 0R | easyedapro:R0805 | 1 | DNP | DNP |  | 0R
R3 | 0R | easyedapro:R0805 | 1 |  | SMT | C17477 | 0Ω 125mW
R4 | 0R | easyedapro:R0805 | 1 |  | SMT | C17477 | 0Ω 125mW
R5 | 100R | easyedapro:R0805 | 1 |  | SMT | C2988937 | 100Ω ±1% 125mW
R6 | 0R | easyedapro:R0805 | 1 |  | SMT | C17477 | 0Ω 125mW
R7 | 57.6kR | easyedapro:R0805 | 1 |  | SMT | C5153977 | 57.6kΩ ±1% 125mW
R8 | 33.2kR 1% | easyedapro:R0805 | 1 | DNP | DNP |  | 33.2kΩ 1%
R9 | 22.1kR 1% | easyedapro:R0805 | 1 | DNP | DNP |  | 22.1kΩ 1%
R10 | 100kR | easyedapro:R0805 | 1 |  | SMT | C2907217 | 100kΩ ±1% 125mW
R11 | 1kR | easyedapro:R0805 | 1 |  | SMT | C95781 | 1kΩ ±1% 125mW
R12 | 4.7R | easyedapro:R0805 | 1 |  | SMT | C2897629 | 4.7Ω ±1% 2W
R13 | 1.000kR | easyedapro:R0805 | 1 |  | SMT | C110774 | 1.000kΩ ±0.1% 薄膜
R14 | 49.9kR | easyedapro:R0805 | 1 |  | SMT | C1730568 | 49.9kΩ ±0.05% 15ppm/°C
R15 | 1.000kR | easyedapro:R0805 | 1 |  | SMT | C110774 | 1.000kΩ ±0.1% 薄膜
R16 | 39.0kR | easyedapro:R0805 | 1 |  | SMT | C1720356 | 39.0kΩ ±0.1% 10ppm/°C 200mW
R17 | 0R | easyedapro:R0805 | 1 |  | SMT | C17477 | 0Ω 125mW
R18 | 100R | easyedapro:R0805 | 1 |  | SMT | C2988937 | 100Ω ±1% 125mW
R19 | 30.9kR | easyedapro:R0805 | 1 |  | SMT | C865394 | 30.9kΩ ±0.1% ≤25ppm/°C 薄膜
R20 | 10.0kR | easyedapro:R0805 | 1 |  | SMT | C110775 | 10.0kΩ ±0.1% 薄膜
R21 | 10.0kR | easyedapro:R0805 | 1 |  | SMT | C110775 | 10.0kΩ ±0.1% 薄膜
R22 | 10.0kR | easyedapro:R0805 | 1 |  | SMT | C110775 | 10.0kΩ ±0.1% 薄膜
R23 | 100kR | easyedapro:R0805 | 1 |  | SMT | C2907217 | 100kΩ ±1% 125mW
R24 | 10kR | easyedapro:R0805 | 1 |  | SMT | C2907219 | 10kΩ ±1% 125mW
R25 | 6.49kR 0.1% | easyedapro:R0805 | 1 | DNP | DNP |  | 6.49kΩ 0.1%
R26 | 10k | easyedapro:R0805 | 1 | DNP | DNP |  | 10k
R27 | 100k | easyedapro:R0805 | 1 | DNP | DNP |  | 100k
R28 | 100kR ±1% | easyedapro:R0805 | 1 | DNP | DNP |  | 100kΩ ±1%
R29 | 10kR ±1% | easyedapro:R0805 | 1 | DNP | DNP |  | 10kΩ ±1%
R30 | 100k | easyedapro:R0805 | 1 | DNP | DNP |  | 100k
R31 | 10k | easyedapro:R0805 | 1 | DNP | DNP |  | 10k
R32 | 360kR ±1% | easyedapro:R0805 | 1 | DNP | DNP |  | 360kΩ ±1%
R33 | 360kR ±1% | easyedapro:R0805 | 1 | DNP | DNP |  | 360kΩ ±1%
R34 | 1.000MR | easyedapro:R0805 | 1 |  | SMT | C2075448 | 1.000MΩ ±0.1% 25ppm/°C
R35 | 10.0kR | easyedapro:R0805 | 1 |  | SMT | C110775 | 10.0kΩ ±0.1% ≤25ppm/°C 薄膜
R36 | 0R | easyedapro:R0805 | 1 |  | SMT | C17477 | 0Ω 125mW
R37 | 1MR | easyedapro:R0805 | 1 | DNP | DNP |  | 1MΩ
R38 | 1MR | easyedapro:R0805 | 1 | DNP | DNP |  | 1MΩ
R39 | 10kR | easyedapro:R0805 | 1 | DNP | DNP |  | 10kΩ
R40 | 1MR | easyedapro:R0805 | 1 | DNP | DNP |  | 1MΩ
R41 | 10MR | easyedapro:R0805 | 1 | DNP | DNP |  | 10MΩ
R42 | 0R | easyedapro:R0805 | 1 | DNP | DNP |  | 0Ω
R43 | 0R | easyedapro:R0805 | 1 | DNP | DNP |  | 0Ω
R44 | 1k-10k | easyedapro:R0805 | 1 | DNP | DNP |  | 1k–10k
R45 | 1k-10k | easyedapro:R0805 | 1 | DNP | DNP |  | 1k–10k
R46 | 0R | easyedapro:R0805 | 1 |  | SMT | C17477 | 0Ω 125mW
RSH2 | 0.100R | easyedapro:AAI_C11_35_LOCAL_Footprints_AAI_SHUNT_4T_3920_Kelvin | 1 |  | SMT | C393067 | 0.100Ω ±1% 3W ±50ppm/°C
U1 | OPA548F/500 | easyedapro:TO-263-7_L10.2-W10.4-P1.27-LS14.4-TL | 1 |  | SMT | C527496 | OPA548F/500
U2 | AD633ARZ-R7 | easyedapro:SOIC-8_L4.9-W3.9-P1.27-LS6.0-BL | 1 |  | SMT | C77810 | AD633ARZ-R7
U3 | INA149AIDR | easyedapro:SOIC-8_L4.9-W3.9-P1.27-LS6.0-BL | 1 |  | SMT | C183089 | INA149AIDR
U4 | OPA1656IDR | easyedapro:SOIC-8_L4.9-W3.9-P1.27-LS6.0-BL | 1 |  | SMT | C1849431 | OPA1656IDR
U5 | STM32G431CBT6 | easyedapro:LQFP-48_L7.0-W7.0-P0.50-LS9.0-BL | 1 |  | SMT | C529355 | STM32G431CBT6（冻结型号）
U6 | AMS1117-3.3 | easyedapro:SOT-223-3_L6.5-W3.4-P2.30-LS7.0-BR | 1 |  | SMT | C6186 | AMS1117-3.3
U7 | TLP185(GR-TPR,E | easyedapro:SOP-6_4P-L3.7-W4.6-P2.54-LS7.0-BL | 1 |  | SMT | C393884 | TLP185(GR-TPR,E
U8 | OPA1656IDR | easyedapro:SOIC-8_L4.9-W3.9-P1.27-LS6.0-BL | 1 |  | SMT | C1849431 | OPA1656IDR
U9 | OPA1656IDR | easyedapro:SOIC-8_L4.9-W3.9-P1.27-LS6.0-BL | 1 | DNP | DNP |  | OPA1656IDR
U10 | TMUX7219DGKRQ1 | easyedapro:VSSOP-8_L3.0-W3.0-P0.65-LS4.9-BL | 1 | DNP | DNP |  | TMUX7219DGKRQ1

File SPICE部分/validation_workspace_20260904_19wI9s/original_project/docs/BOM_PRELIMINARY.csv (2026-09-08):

Ref | Part | Value / Orderable | Reason | First-version note
U1 | OPA548T/OPA548F | Power op amp | ±18 V power follower with current limit | Use heatsink and jumper RCL 33.2k/22.1k
U2 | AD633ARZ | 4-quadrant multiplier | Implements ISIG*VK/10 | Needs ±15 V and careful decoupling
U3 | INA149AID | Unity-gain diff amp | Measures SPK-DRV across 0.1 ohm shunt | High common-mode capability
U4 | OPA1656ID | Dual audio op amp | Gain 50 and gain 20 stages | Fast enough for loop and audio-band current signal
U6 | STM32G431CBT6 | MCU/DAC | Generates Rtarget command | Simulation uses DAC surrogate
RSHUNT | Vishay LVR05R1000FE70 | 0.1 ohm 5 W current sense | Low inductance and Kelvin sense preferred
RCL1 | Thin film | 33.2k | ~1.52 A OPA548 limit | Default safer setting
RCL2 | Thin film | 22.1k | ~1.99 A OPA548 limit | Stress option
RSNUB | Power resistor | 4.7 ohm 2 W | Output snubber | Fit footprint for tuning 3.3-10 ohm
CSNUB | Film/C0G | 47 nF 100 V | Output snubber | Fit footprint for tuning 10-100 nF
DCLAMP | Schottky | >=5 A >=60 V | OPA548 output rail clamps | Close to power pins

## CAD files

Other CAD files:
blender/output/c11_35_v8_pcb_model.blend

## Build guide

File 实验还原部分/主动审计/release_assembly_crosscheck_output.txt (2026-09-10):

BOM=73 CPL=73 PCB_footprints=147 errors=0

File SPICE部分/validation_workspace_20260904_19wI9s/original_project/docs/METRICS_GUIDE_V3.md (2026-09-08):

# Metrics guide v3

## Primary columns

### `synerr_rms_tail_v`

RMS of:

```text
V(SPK) - Rx_command(t) * Iport
```

after the soft-start/settling window. This is the main voltage-domain check that the synthetic impedance relation is being implemented.

### `synerr_norm_rms_tail`

Normalized version of the synthesis error:

```text
rms(synerr) / rms(Rx_command * Iport)
```

Use this to compare cases with different current amplitudes.

### `reff_fit_tail_ohm`

Least-squares total effective resistance for fixed-R cases:

```text
Re + sum(VSPK*Iport)/sum(Iport^2)
```

This is the preferred resistance estimate for `full_einj_fixed_*` cases.

### `reff_pointwise_rms_err_tail_ohm`

Masked point-wise legacy ratio metric. It is useful for debugging but should not be treated as the main pass/fail criterion.

## Safety columns

### `ilim_ratio_tail_pk`

Peak output current divided by the modeled current limit during the evaluation tail. Values much less than 1 indicate current-limit margin.

### `opa548_vsat_max_v`

Simple saturation proxy for the OPA548 surrogate output. It should normally stay near zero.

### `xmax_ratio_pk`

Peak displacement divided by the ±4 mm excursion limit. Values below 1 are mechanically within the modeled linear displacement range.

## Recommended first plots to inspect

1. `full_einj_fixed_r1_f1000.png`
2. `full_einj_fixed_r100_f1000.png`
3. `full_single_sine.png`
4. `full_dual_sine.png`
5. `full_stress_pa5_mod.png`

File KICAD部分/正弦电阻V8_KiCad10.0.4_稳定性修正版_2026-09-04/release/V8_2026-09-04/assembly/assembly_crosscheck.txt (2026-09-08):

BOM SMT refs: 73
CPL SMT refs: 73
Missing from CPL: []
Non-SMT/export-only refs excluded: []

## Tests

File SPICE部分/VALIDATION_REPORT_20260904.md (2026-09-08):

# SPICE_project_repaired_20260710_FINAL.zip 可运行性验证报告

验证日期：2026-09-04（Asia/Shanghai）

## 结论

**原 ZIP 不能原样执行源码所定义的 `complete` 完整套件，因此不能判定为“完整可跑”。**

- 快速冒烟工况可以运行并通过。
- 固定阻值和动态正式签核入口均可完整执行，但工程指标不通过。
- `complete` 原样启动时立刻因缺少两个电路模板而退出。
- 从用户指出的 v4.5 目录补齐模板后，`complete` 的 57 个工况均被调度；39 个数值完成，18 个 ngspice 失败；完成的工况中 33 个验收通过、6 个验收失败。
- MCU 固件源码不在包中，固件行为只能判为 `not_auditable`。

因此应区分：

1. Linux/ngspice/Python 运行环境可用；
2. 主仿真链路可启动；
3. 原 ZIP 的完整回归打包不完整；
4. 当前设计尚未达到 1–100 Ω、10–1000 Hz 的动态签核目标。

## 输入文件与完整性

| 文件 | SHA-256 | ZIP 检查 |
|---|---|---|
| `SPICE_project_repaired_20260710_FINAL.zip` | `90608bf979f47885d40b6cf487b2687b21ee009db6870aefc025ae112de19dda` | 无压缩错误 |
| `环境/SPICE_project_repaired_20260710_FINAL.zip` | 同上 | 与工作区 ZIP 字节一致 |
| `环境/ngspice_runtime_linux_x86_64.zip` | `80cbc990e212c56c660a8e83001bded94a56db167b9cb6545a7d442049d5aea1` | 无压缩错误 |
| `环境/spice_python_cp313_linux.zip` | `40de8d391eaf9cca35156e0cd18757af1d2ca60b62498a30b4211de192de3bf8` | 无压缩错误 |

项目清单声明的 56 个文件在全新解压副本中全部存在，大小与 SHA-256 全部匹配。问题不是 ZIP 损坏，而是清单和包本身没有收入完整套件所引用的两个模板。

## Linux 环境

- 系统：Linux/WSL x86-64。
- ngspice：环境包自带 ngspice 42，可启动，`ldd` 未发现缺失动态库。
- Python：系统 CPython 3.12.3。
- 已用依赖：NumPy 2.4.6、Pandas 3.0.5、Matplotlib 3.11.1，满足项目的 `numpy>=2.0`、`pandas>=2.0`、`matplotlib>=3.8`。
- `spice_python_cp313_linux.zip` 中包含 CPython 3.13 ABI 轮子，不能直接安装到当前 Python 3.12；本机已有满足要求的兼容版本，因此无需联网下载或修改系统 Python。

运行时通过 `NGSPICE_BIN=<解压后的绝对路径>/bin/ngspice` 指定 ngspice，没有进行永久系统级修改。

## 原包原样测试

### 结构、自检和冒烟

| 项目 | 结果 |
|---|---|
| `scripts/check_project.py` | pass |
| `tests/test_validation_metrics.py` | pass |
| firmware audit | `not_auditable`，源码数 0 |
| 7.2 Ω / 1 kHz quick smoke | 数值完成，验收 pass，退出码 0 |

注意：`check_project.py` 只检查 `full_component_template.cir`，没有检查完整套件还会引用的 ideal/behavioral 模板，所以结构自检出现假阴性。

### `complete` 原样启动

原包在第一个工况 `ideal_single_sine` 立即退出：

```text
FileNotFoundError: spice/circuits/ideal_reference_template.cir
```

同时缺少：

- `spice/circuits/ideal_reference_template.cir`
- `spice/circuits/behavioral_chain_template.cir`

`scripts/run_sweeps.py` 明确引用这两个文件，但它们没有进入 FINAL ZIP。

## 补齐模板后的完整运行

两个缺失模板可在以下位置找到：

`C:\Users\Administrator\Downloads\active_acoustic_impedance_v4_5_auditable_ngspice_launch_path_fix\spice\circuits`

它们也存在于 `需求背景与SPICE.zip` 内嵌 v3.3 项目中；两处文件逐字节一致：

| 模板 | SHA-256 |
|---|---|
| `ideal_reference_template.cir` | `3fe9f06ddd96b567ec9be27f45467f163296e7fc191cc0fe520934facd8c1f83` |
| `behavioral_chain_template.cir` | `c3ac5ab868d820d0da46c700945c3a65f96afeb3be29e067ba35549e488cca86` |

仅在验证副本补齐文件后执行：

```bash
python3 scripts/run_sweeps.py \
  --clean \
  --results-dir results_complete_runtime_patched \
  --suite complete \
  --model-lib official-pure \
  --no-plots \
  --no-case-csv
```

结果：

| 指标 | 数量 |
|---|---:|
| 总工况 | 57 |
| ngspice 数值完成 | 39 |
| ngspice 失败 | 18 |
| 验收通过 | 33 |
| 验收失败 | 6 |
| 因仿真失败未评估 | 18 |
| 进程退出码 | 2 |

18 个数值失败的分类：

- 16/16 个寄生参数工况全部在初始工作点失败，典型日志为 `Transient op failed, timestep too small`，问题节点位于纯厂商宏模型的 OPA548/AD633 内部。
- `full_single_sine_ilim2a` 在初始工作点失败，OPA548 宏模型内部二极管出现 `timestep too small`。
- `fault_speaker_open_r1` 在约 8.007 ms 处步长缩小至 `1.25e-18` 后失败。

完成后仍验收失败的主要工况：

- 1 Ω / 1 kHz：实部约 1.05369 Ω，但虚部 0.341832 Ω，大于 0.1 Ω 限值。
- 100 Ω / 1 kHz：实部约 98.8159 Ω，虚部 -5.60541 Ω，超过约 4.99942 Ω 限值。
- 1 Ω / 5 kHz：实部误差约 0.434583 Ω，虚部约 1.76349 Ω，均超限。
- 1 kHz 载波下的单正弦动态电流注入：p95 实部相对误差约 1.08996，虚部相对值约 0.613279，均高于 0.1。
- 扬声器短路故障：DC 端口电流约 1.55098 A，限流比约 1.02038，未满足安全判据。
- RSH 开路故障：饱和裕量违规约 1.71487 V。

## 正式固定阻值签核

5 个 ngspice 工况全部数值完成；3 个通过，2 个失败，汇总/脚本退出码 3。

| 目标 | 实部 Ω | 虚部 Ω | 验收 |
|---:|---:|---:|---|
| 1 Ω | 1.053687 | 0.341832 | fail：虚部超限 |
| 5 Ω | 5.045566 | 0.122007 | pass |
| 7.2 Ω | 7.248699 | -0.007874 | pass |
| 20 Ω | 20.000767 | -0.766657 | pass |
| 100 Ω | 98.815931 | -5.605413 | fail：虚部超限 |

`RUN_FIXED_SIGNOFF_SPLIT.sh` 本身也已完整执行，逐工况调度和最终聚合正常。

## 正式动态签核

5 个 ngspice 工况全部数值完成，但 5 个全部验收失败，汇总/脚本退出码 3。

| 调制频率 | p95 实部相对误差 | p95 虚部相对值 | 限值 | 验收 |
|---:|---:|---:|---:|---|
| 10 Hz | 0.482850 | 1.030622 | 0.1 | fail |
| 30 Hz | 0.564615 | 1.199943 | 0.1 | fail |
| 100 Hz | 0.698100 | 1.749187 | 0.1 | fail |
| 300 Hz | 0.883115 | 1.084344 | 0.1 | fail |
| 1000 Hz | 1.154846 | 2.881177 | 0.1 | fail |

`RUN_DYNAMIC_SIGNOFF_SPLIT.sh` 本身也已完整执行，逐工况调度和最终聚合正常。

## 与需求背景对照

| 需求 | 覆盖情况 | 结论 |
|---|---|---|
| 扬声器参数 Re=7.2 Ω、Le=0.2 mH、Bl=4.6 Tm、Mms=5.7 g、fs=90 Hz、Qms=2.29、Sd=0.005 m² | 配置一致 | 覆盖 |
| Python + ngspice | 实际使用 Python 3.12 + ngspice 42 | 可运行 |
| 理想、行为、真实器件模型 | 单/双正弦三种模型工况均存在；补齐模板后可跑 | 原 ZIP 打包缺文件 |
| 固定 1、5、7.2、20、100 Ω | 全部数值完成 | 1 Ω、100 Ω 未签核 |
| 单正弦动态变化 | 有基线与电流注入签核 | 严格动态指标未通过 |
| 双正弦叠加 | ideal/behavioral/full 基线均数值完成且安全类判据通过 | 尚非动态电阻精度签核 |
| 10–1000 Hz 调制 | 10、30、100、300、1000 Hz 正式签核均完成 | 5/5 未通过动态精度 |
| 寄生参数与异常工况 | 16 个寄生、7 个故障工况已调度 | 纯厂商模型下存在大量收敛失败及安全失败 |
| 固件控制 | 包中无 MCU 源码 | 不可审计 |

项目自带 README 已声明“不声称完整 1–100 Ω、10–1000 Hz 动态目标通过”，本次实跑与该声明一致。

## 建议的修包动作

1. 把上述两个缺失模板加入 FINAL ZIP，并加入 `PACKAGE_MANIFEST_REPAIRED.json`。
2. 修改 `scripts/check_project.py`，把两个模板加入 `REQUIRED`，防止冒烟通过但完整套件启动失败。
3. 在 README 中明确区分 `quick smoke`、`complete`、fixed signoff、dynamic signoff，并写明退出码 2/3 的含义。
4. 对寄生工况增加适用于官方 PSpice 宏模型的启动/收敛策略，或明确这些工况需使用经过验证的 ngspice 兼容模型；不能把当前 16/16 失败写成完成验证。
5. 调整动态前馈/相位补偿后重新签核，当前动态误差远高于 10% 限值。
6. 补充真实 MCU 固件及上电、限幅、故障关断逻辑后再做控制路径签核。

## 验证产物

验证副本根目录：

`validation_workspace_20260904_19wI9s`

主要结果：

- `project/SPICE_project_repaired_20260710_FINAL/1SPICE_SPICE_SIM/results_complete_runtime_patched/`
- `project/SPICE_project_repaired_20260710_FINAL/1SPICE_SPICE_SIM/results_fixed_signoff_runtime/`
- `project/SPICE_project_repaired_20260710_FINAL/1SPICE_SPICE_SIM/results_dynamic_signoff_runtime/`
- `project/SPICE_project_repaired_20260710_FINAL/1SPICE_SPICE_SIM/results_fixed_signoff_combined/`
- `project/SPICE_project_repaired_20260710_FINAL/1SPICE_SPICE_SIM/results_dynamic_signoff_combined/`

为减少磁盘占用，完整运行关闭了 PNG 和逐点派生 CSV；每个工况的原始 `.dat`、ngspice `.log`、渲染后的 `.cir`、配置 JSON、摘要 JSON，以及总表和报告均保留。

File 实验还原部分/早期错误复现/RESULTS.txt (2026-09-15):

R10 E/S sweep (TI OPA548 official):
  100k   -> ES-V- = 3.478609 V
  9.0909k-> ES-V- = 0.614035 V
  6.8k   -> ES-V- = 0.463396 V

OPA548 ON + imposed 105 kHz diagnostic:
  Evidence correction 2026-09-15: these are instantaneous rail peaks, not bench CC verification.
  2 Vpk rerun -> mean draw +23.62349 mA / -rail draw 23.48368 mA.
  Bench supply current-limit dynamics and board bulk capacitance are not modeled here.
  1 Vpk -> OUT 2.0728 Vpp, rail peak ~37.8 mA
  2 Vpk -> OUT 4.1112 Vpp, rail peak ~69.1 mA
  3 Vpk -> OUT 6.1403 Vpp, +rail peak ~101.0 mA
  4 Vpk -> OUT 7.2090 Vpp, +rail peak ~132.1 mA

Wrong scope ground clip on TP8 equivalent:
  normal: TP8=2.019571 V, +10V rail draw=3.950 mA
  TP8 clamped by 50mOhm: TP8=4.455 mV, +10V rail draw=93.004 mA

Healthy official baseline:
  10084 transient rows
  late TP8_PP=0 V
  sustained 100-110 kHz: NOT reproduced

H12 dynamic E/S comparison (prior validated deck):
  V7-like, actual ON: 453.3 kHz; OPA548 OUT 0.140 Vpp; TP8 55.7 uVpp
  not equivalent to measured OPA-OFF TP8 multi-volt 105 kHz.

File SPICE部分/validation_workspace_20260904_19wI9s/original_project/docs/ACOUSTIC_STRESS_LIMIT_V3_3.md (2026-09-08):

# Acoustic stress limit v3.3

This package intentionally removes all acoustic stress cases above 5 Pa from the default sweep suite.

## Remaining acoustic stress cases

- `full_stress_pa1_fixed1ohm`
- `full_stress_pa1_mod`
- `full_stress_pa5_fixed1ohm`
- `full_stress_pa5_mod`

Higher-pressure acoustic stress cases are not generated by `scripts/run_sweeps.py`, and old generated high-pressure case folders are not included in this package.

The purpose is to keep the project focused on the intended operating envelope and avoid interpreting high-pressure boundary/failure cases as normal validation cases.

Run from scratch with:

```bash
python scripts/run_sweeps.py --clean
```

Generate netlists only with:

```bash
python scripts/run_sweeps.py --clean --write-only
```

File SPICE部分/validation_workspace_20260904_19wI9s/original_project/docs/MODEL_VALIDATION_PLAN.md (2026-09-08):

# 严格仿真计划

本项目默认不是只跑一条“能收敛”的 transient，而是用分层对照与应力扫参来检查合理性。

## 1. 三层模型对照

1. `ideal_*`：理想合成阻抗 `V=Rx*i`，用于理论基准；
2. `behavioral_*`：上一轮行为级电流检测 + 乘法器 + 功率跟随器；
3. `full_*`：全元器件接入版，OPA548/AD633/INA149/OPA1656 以子电路接入。

## 2. 固定阻值测试

- `Rtarget = 100, 20, 7.2, 5, 1 Ω`
- 重点确认：
  - `Rx=0` 穿越点；
  - `Rtarget=1 Ω` 时 `Rx=-6.2 Ω`；
  - 高阻态小电流下 `Reff` 重建是否出现数值误差。

## 3. 调制频率边界

- `fm = 10, 30, 100, 300, 1000 Hz`
- 重点确认 DAC/AD633/OPA1656/OPA548 surrogate 引入的一阶带宽和相位滞后没有让闭环失稳。

## 4. 声学激励频率扫描

- `fa = 60, 90, 120, 180, 300 Hz`
- 特别关注 `fs=90 Hz` 附近速度和位移。

## 5. 声压应力扫描

- `Pamp = 1, 5 Pa`。
- 本 v3.3 包默认删除 `Pamp > 5 Pa` 的应力测试，不再生成更高声压 case。
- 同时跑固定 `1 Ω` 和调制 `1~100 Ω`。
- 检查输出饱和、限流、位移是否超过 `±4 mm`。

## 6. 不通过判据建议

建议把下面几项视作需要重设计/降额：

- `xmax_ratio_pk > 1`；
- OPA548 surrogate 出现长时间饱和；
- `reff_rms_err_tail_ohm` 在非饱和时明显超过 `0.1 Ω`；
- `Iport` 接近或超过设定限流；
- `Rtarget=1 Ω` 低阻/负阻段出现持续振荡。

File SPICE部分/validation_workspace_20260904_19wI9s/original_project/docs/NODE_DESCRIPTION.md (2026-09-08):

# 节点描述法：全元器件接入版

## 电气节点

| 节点 | 含义 |
|---|---|
| `0` | 全局模拟地 / 喇叭负端 |
| `SPK` | 喇叭正端，也是合成阻抗端口 |
| `DRV` | OPA548 输出端，经过 `RSHUNT` 后到 `SPK` |
| `VSENSE` | INA149 差分检测输出，`V(SPK)-V(DRV)` |
| `ISIG` | OPA1656 放大 50 倍后的电流信号，约 `5*iport` |
| `DAC_R` | MCU/DAC 阻值命令，`0~3 V` |
| `VK` | 缩放/偏置后的阻值命令，`VK = Rx/10` |
| `MUL` | AD633 输出，`MUL = ISIG*VK/10` |
| `VCMD` | 后级放大 20 倍后给 OPA548 的命令，理想为 `Rx*iport` |
| `P18/N18` | OPA548 ±18 V 电源 |
| `P15/N15` | 小信号 ±15 V 电源 |
| `V3V3` | MCU/DAC 3.3 V 电源 |

## 机械/电声节点

| 节点 | 含义 |
|---|---|
| `VEL` | 膜片速度，电压值等价 `m/s` |
| `XNODE` | 膜片位移，电压值等价 `m` |
| `RTARGET` | 目标总等效电阻 `1~100 Ω` |
| `RXNODE` | 外接合成阻抗 `Rx=Rtarget-Re` |
| `REFF` | 从端口重建的总等效电阻 `Re + V(SPK)/Iport` |
| `ERR` | `REFF-RTARGET` |
| `REMNODE` | 电磁阻尼 `(Bl)^2/Rtarget` |
| `QNODE` | 估算有效机械 Q |

## 端口关系

```text
DRV ── RSHUNT ── SPK ── LVC ── RVC ── BEMF ── GND
```

端口电流定义为：

```text
iport = (V(SPK)-V(DRV))/RSHUNT
```

控制链：

```text
VSENSE = V(SPK)-V(DRV)
ISIG   = 50*VSENSE = 5*iport
VK     = Rx/10
MUL    = ISIG*VK/10 = Rx*iport/20
VCMD   = 20*MUL = Rx*iport
OPA548 drives DRV so that SPK ≈ VCMD
```

于是外接电路对端口呈现：

```text
V(SPK) ≈ Rx(t) * iport
Rtarget(t) = Re + Rx(t)
```

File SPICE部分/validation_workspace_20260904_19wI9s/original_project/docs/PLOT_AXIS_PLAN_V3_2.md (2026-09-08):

# v3.2 axis-planned rerun project

This project is intended to regenerate the simulation outputs from ngspice, not to patch old CSV files.

## Main rerun path

```bash
pip install -r requirements.txt
python scripts/check_project.py
python scripts/run_sweeps.py --clean
```

`run_sweeps.py --clean` removes `results/`, regenerates all case netlists, runs ngspice, parses fresh `.dat` output, writes new CSV/summary files, and generates repaired PNG figures.

## Plot-axis planning

The previous figures often looked like straight lines because rare startup spikes or pointwise `V/I` explosions dominated raw min/max limits. v3.2 fixes this at plotting time only; numeric CSV values and metrics remain unmodified.

### Shared x-axis logic

- Overview figure `<case>.png`: full simulation time range.
- Tail figure `<case>_tail.png`: steady-state tail window after soft-start.
- Tail duration is selected from the actual excitation/modulation frequencies:
  - slow modulation: keep enough time to see the trend;
  - high-frequency injection: show several final cycles instead of a dense block.

### Y-axis logic by panel

1. Resistance panel:
   - shows `R desired`, `R command`, `Rx command`, and clipped diagnostic `Reff pointwise`;
   - includes reference levels around `-10`, `0`, `1`, `7.2`, `100`, `110 Ω`;
   - uses robust percentile limits to avoid current-zero spikes.

2. Voltage synthesis panel:
   - shows `SPK`, `DRV`, `VCMD`, `Rx*Iport`;
   - uses symmetric voltage limits centered around zero.

3. Current panel:
   - shows `Iport` and the threshold used for reliable pointwise Reff;
   - uses symmetric current limits.

4. Error panel:
   - shows `synerr`, `cmderr`, `followerr`;
   - uses tight symmetric limits so microvolt/millivolt error is visible.

5. Mechanical panel:
   - shows velocity and displacement in mm;
   - uses symmetric limits.

6. Safety/diagnostic panel:
   - shows clipped `Reff-Rcmd`, `|x|/xmax`, saturation proxy, and current-limit ratio;
   - robust scaling prevents the diagnostic Reff trace from hiding safety curves.

## Replot helper

`python scripts/replot_existing_results.py` is provided only for already-ran results. By default it does not rewrite existing CSV files. Use `--update-derived-csv` only when explicitly needed.

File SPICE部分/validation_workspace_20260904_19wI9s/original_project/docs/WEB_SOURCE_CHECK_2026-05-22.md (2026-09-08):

# Web/source check summary

These notes are for model-selection traceability. They are not a redistribution of vendor models.

- TI confirms OPA548 PSpice/TINA models are available and unencrypted on the web.
- The OPA548 datasheet documents the adjustable output-current limit equation and capacitive-load drive considerations.
- Analog Devices documents AD633 as a complete four-quadrant multiplier with output relation `W = (X1-X2)(Y1-Y2)/10 + Z`.
- TI documents INA149 as a high-common-mode difference amplifier with 500 kHz bandwidth.
- TI documents OPA1656 as a high-bandwidth audio op amp with 53 MHz GBW and 100 mA output current capability.

Because vendor model downloads can require license acceptance, this project does not bundle proprietary macro files. Use `scripts/fetch_vendor_models.py` as a source checklist and replace the surrogate subcircuits locally.

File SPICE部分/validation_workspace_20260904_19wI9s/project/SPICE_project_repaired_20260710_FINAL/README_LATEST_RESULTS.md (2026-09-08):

> **2026-07-10 repair notice:** The acceptance and complex-impedance calculations have been replaced. Historical numeric reports below are retained for context only. Use `README_REPAIRED.md`, `1SPICE_SPICE_SIM/REPAIR_NOTES_20260710.md`, and `verification_results/` for current interpretation.

# 1SPICE_SPICE_SIM latest pure-vendor package — 2026-07-07

## 1. What this package contains

This is the latest SPICE project package after the pure-vendor debug and PCB-fix discussion. It contains:

- `1SPICE_SPICE_SIM/`: latest runnable project files.
- `1SPICE_SPICE_SIM/spice/circuits/full_component_template.cir`: latest full-chain template.
- `1SPICE_SPICE_SIM/scripts/run_sweeps.py`: latest runner with the new trim/servo/output-stability parameters exposed.
- `1SPICE_SPICE_SIM/spice/models/official_pure_rawps_wrapped_models.lib`: pure-vendor wrapper library.
- `1SPICE_SPICE_SIM/spice/models/vendor_official/`: raw vendor macromodel files included from the original project archive.
- `reports/`: result reports and PCB-decision tables from the previous validation work.
- `RUN_QUICK_SMOKE.sh`: quick smoke regression script.

This package does not include the ngspice runtime or Python wheelhouse. In the ChatGPT sandbox those are separate files:

- `ngspice_runtime_linux_x86_64.zip`
- `spice_python_cp313_linux.zip`

## 2. Included circuit changes

The current full-component template includes these changes and hooks:

1. **OPA548 RCL fix**: `RCL ILIM N18`, not ground.
2. **Current-sense offset trim**: `VOS_I_TRIM` subtracts input-referred current-sense offset before the OPA1656 sense amplifier.
3. **Slow DC servo**: low-pass/integrating `IPORT` path injects bounded correction into AD633 `Z` node.
4. **Trim/servo scheduling**: `FIXW(RTARGET)` fades trim/servo action outside the low-resistance region.
5. **U4A/U4B compensation exposed**: `C_U4A_F`, `C_U4B_F` are parameters, not hard-coded-only values.
6. **Lead-lag placeholders**: optional `R_U4A_LEAD/C_U4A_LEAD` and `R_U4B_LEAD/C_U4B_LEAD` branches are present and default off.
7. **OPA548 output stability hooks**: optional `RISO_OUT` and Zobel `RZOBEL/CZOBEL` path are present and default near-off.
8. **More stable Reff diagnostic**: diagnostic `B_REFF` uses an epsilon-regularized expression to avoid zero-current singularities.

## 3. Current confirmed status

### Confirmed effective

- SPICE runtime feasibility: ngspice, raw output, spicelib, and PySpice paths were validated earlier.
- Pure-vendor wrapper smoke tests: AD633, OPA548, OPA1656, and INA149 were made runnable under ngspice compatibility mode.
- OPA548 RCL reference correction is mandatory and effective.
- Current-sense offset trim is effective, especially for low target resistance.
- Slow DC servo is effective for reducing low-resistance DC bias, but it is not yet a final all-range bias solution.
- U4A/U4B compensation reduction is directionally effective for dynamic tracking, but not enough for complete dynamic signoff.
- Acoustic dynamic safety cases passed in previous validation.

### Not yet signoff-passed

- Full pure-vendor dynamic impedance tracking is **not** fully signed off.
- Previous dynamic signoff result: electrical dynamic tracking passed only `1/20` baseline cases; fast-compensation screening improved to `6/20`, but still did not pass all cases.
- Final U4A/U4B compensation values are not frozen.
- Lead-lag values, Zobel values, VCMD clamp threshold, servo gain/bandwidth, and trim scheduling still require board-level and SPICE iteration.

## 4. Important numeric findings from previous validation

- With RCL corrected, fixed-R AC Reff recovered approximately to:
  - target `1Ω` -> about `1.05Ω`
  - target `7.2Ω` -> about `7.25Ω`
  - target `100Ω` -> about `99Ω`
- Current-sense trim + slow DC servo reduced low-R DC bias, e.g. `Rtarget=1Ω` improved from roughly `42mA` to roughly `3.6mA` in the earlier curated test.
- `Rtarget=7.2Ω` and `100Ω` still retained mA-level DC bias, so the servo is useful but not final.
- Dynamic tracking failure is dominated by feedforward phase/bandwidth error, not by gross OPA548 saturation, current limit, or speaker excursion.

## 5. PCB decision summary

Hard changes:

1. Connect OPA548 RCL to `-18V/N18`, not ground.
2. Add current-sense trim injection point.
3. Add AD633 `Z` trim/servo injection point.
4. Make U4A/U4B feedback capacitors replaceable.
5. Reserve U4A/U4B lead-lag DNP branches.
6. Reserve OPA548 output Riso and Zobel footprints.
7. Add test points: SPK, DRV/PA_OUT, IPORT, VSENSE, VSENSE_TRIM, ISIG, VK, MUL, ZSERVO, IPDC, VCMD, ILIM, supply rails.

Do not freeze yet:

- U4A/U4B final compensation values.
- Lead-lag RC values.
- DC servo gain/bandwidth/limit.
- VCMD clamp threshold.
- Rtarget minimum clamp.
- Whether AD633 remains final or is replaced by digital multiplication / closed-loop impedance servo.

## 6. How to run

From a shell where ngspice is already available:

```bash
cd <package-root>
./RUN_QUICK_SMOKE.sh
```

Or manually:

```bash
cd <package-root>/1SPICE_SPICE_SIM
python scripts/run_sweeps.py --clean --results-dir results_smoke_fixed_r7p2 --case-filter full_fixed_r7p2 --model-lib official-pure
```

For the ChatGPT sandbox environment, initialize ngspice first using the existing `/mnt/data/setup_spice_env.sh` if present:

```bash
source /mnt/data/setup_spice_env.sh
```

## 7. Interpretation warning

The package is the latest **engineering debug and PCB-fix baseline**, not a final passed dynamic signoff. It is suitable for guiding PCB revisions and for continuing SPICE iterations. It should not be represented as final production signoff until the dynamic tracking matrix passes with the chosen compensation/servo values.

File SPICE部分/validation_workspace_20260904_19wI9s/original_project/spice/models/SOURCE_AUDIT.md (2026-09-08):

# 模型来源与替换审计

## 默认模型

`ngspice_compatible_macros.lib` 是本项目生成的 surrogate macromodel 集合，不是 TI/ADI 官方模型。它的目的：

- 让电路以完整器件接口方式接入；
- 引入有限带宽、输出摆幅、限流、输入/输出负载等一阶非理想；
- 保持 ngspice 兼容，便于批处理扫参；
- 允许后续用官方宏模型逐步替换。

## 为什么没有直接把官方宏模型改写进默认库

1. AD633 官网模型下载会跳转到 ADI SPICE Model License Agreement，需要用户/公司确认许可后下载。
2. TI 的 PSpice/TINA 模型通常以 ZIP/TSC 发布，可能包含 PSpice/TINA 语法，需要本地清理后才能被 ngspice 接受。
3. 本项目的仿真目标是先验证全链路稳定性和应力边界；供应商模型替换后必须重新跑 `macro_smoke_tests.cir` 与全套 `run_sweeps.py`。

## 替换流程

1. 运行：

```bash
python scripts/fetch_vendor_models.py --print-links
```

2. 本地打开链接并确认厂商许可证。
3. 将下载的 `.lib/.cir/.sub/.mod` 放入：

```text
spice/models/vendor_downloads/
```

4. 在 netlist 中把：

```spice
.include ../models/ngspice_compatible_macros.lib
```

替换为官方模型 `.include`，并修正 `XU...` 子电路名称和 pin order。

5. 先跑：

```bash
ngspice -b spice/circuits/macro_smoke_tests.cir
```

6. 再跑全量扫描。

## v2 repair note

`ngspice_compatible_macros.lib` was repaired on 2026-05-22 after uploaded results showed every full-component case pinned near the OPA548 current limit. The root cause was not an external vendor model issue; it was the local surrogate model's behavioral current-source polarity.

The original v1 surrogate is retained as:

```text
spice/models/ngspice_compatible_macros_faulty_legacy.lib
```

Do not use the legacy file for design validation except when reproducing the old failure.

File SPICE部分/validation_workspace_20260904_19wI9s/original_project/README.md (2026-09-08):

# Active acoustic impedance v3.3 — ≤5 Pa acoustic-stress rerun project

This is a complete rerun-oriented project. It keeps the v3.2 axis-planned plotting fixes and removes all acoustic stress tests above 5 Pa from the default sweep suite.

## What is changed

- Robust `YLIM` planning for every panel using percentile-based display limits.
- Separate overview and steady-state tail zoom figures for every case.
- Pointwise `Reff` is plotted as a clipped diagnostic only; raw CSV values are preserved.
- `run_sweeps.py --clean` regenerates all netlists, reruns ngspice, parses fresh data, and creates new figures. It does not patch old CSV files.
- Optional `replot_existing_results.py` can redraw already-ran CSV outputs, but by default it does not rewrite CSV files.
- Acoustic stress cases are now limited to `Pamp = 1 Pa` and `Pamp = 5 Pa`; higher-pressure acoustic stress cases are not generated.

## Run full simulation from scratch

```bash
pip install -r requirements.txt
python scripts/check_project.py
python scripts/run_sweeps.py --clean
```

## Generate netlists only, without ngspice

```bash
python scripts/run_sweeps.py --clean --write-only
```

## Run only electrical-injection cases

```bash
python scripts/run_sweeps.py --clean --case-filter einj
```

## Optional: redraw existing results only

```bash
python scripts/replot_existing_results.py
```

This optional helper is not the main path. The main path is always `run_sweeps.py --clean`.

## Read figures

For conclusions, prioritize:

- `synerr_norm_rms_tail`
- `synerr_rms_tail_v`
- `cmderr_rms_tail_v`
- `follow_error_rms_tail_v`
- `reff_fit_tail_ohm` for fixed-resistance injection tests
- `ilim_ratio_tail_pk`
- `xmax_ratio_pk`

Do not use `Reff pointwise` as the primary success criterion. It is a masked/interpolated/clipped diagnostic for visualization only.

## v3.3 acoustic-stress scope

The default sweep suite intentionally excludes all acoustic stress cases with `Pamp > 5 Pa`.
Remaining acoustic stress cases are:

- `full_stress_pa1_fixed1ohm`
- `full_stress_pa1_mod`
- `full_stress_pa5_fixed1ohm`
- `full_stress_pa5_mod`

This does not change the electrical-injection cases, baseline modulation cases, or acoustic frequency sweep cases.

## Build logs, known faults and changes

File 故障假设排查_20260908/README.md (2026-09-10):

# 故障假设排查（2026-09-08）

本目录是本轮 PCB 故障假设的独立审计目录，不修改 PCB、KiCad 工程、原始
TI 宏模型或旧 SPICE deck。主场景固定为：U4/J2 `+/-10 V`、OPA548/J1
`+/-5 V`、OPA548 `E/S = V- + 0.6 V`（OFF）、`R5 = 100 ohm`、真实的
`4.7 ohm + 47 nF`输出网络，观察点为 TP8（U4 输出、R5 之前）。每个
假设先做物理/数量级预测，再用不超过 3 个固定参数 case 的 ngspice-42
瞬态复核；每个 case 以 30 s 为限，瞬态至少 0.5 ms。没有人为注入
105 kHz 极点或正弦源。

## 模型有效性边界

官方 `OPA548.LIB` 和 `OPA1656.LIB` 在 ngspice-42 需本目录或子目录的
`.spiceinit`（`set ngbehavior=ps`）兼容设置。OPA548 OFF 宏模型的静态
电流此前已明显偏离数据手册的 shutdown IQ；因此所有 OFF 供电电流只作
“宏模型工作点诊断”，不能解释成实板电流。`EXIT 0` 只表示数值运行结束，
还必须检查 KVL、波形是否饱和、是否存在足够长的稳定晚期振荡及频率。

## 本目录结构

* `baseline_official/`：复制的已验证健康官方模型基线（不改源文件）。
* `H01_R16_十倍错料/`、`H02_R16_漏装/`、`H03_R15_低值/`、
  `H04_R15_漏装/`、`H05_U4B输入输出焊桥/`、`H11_U4B_pin5_pin6焊桥/`：
  本轮由 Luna Max 负责；H11 是对 H04 超时后的独立邻近脚补充。
* `H06-H10/`：由另一 agent 独立建立；本 agent 只在其完成后写交叉审查，
  不直接修改其假设目录。
* `H12_OPA548_ES_R5动态耦合/`：新增的组合机制审计。它有意解除统一基线中
  “OPA548 固定 OFF”的前提，用有限 E/S 状态、TLP185、R10、R5 和 J1/PGND
  网络检查此前模型盲区；不把 H12 作为新的单一加工错误。

固定基线已复制到本目录的 `baseline_official/`；其中保留了可审计的
`fixed_H0_R16_39k.cir`、`fault_fixed_common.inc` 和运行日志。原始临时
审计目录不属于 GitHub 归档，避免把机器临时文件带入版本历史。

## 判定词

“本模型未复现”表示 deck 在适用边界内收敛但没有目标波形；“不适用”
表示该物理错误无法由当前官方宏模型/简化拓扑有意义表示；“DC饱和”与
“持续振荡”严格分开；“未完成”只用于运行失败或证据不足。H12 的
“组合模态”只表示模型中存在高频耦合模式；其约 453 kHz 结果不能等同于
实板 100–110 kHz 根因。

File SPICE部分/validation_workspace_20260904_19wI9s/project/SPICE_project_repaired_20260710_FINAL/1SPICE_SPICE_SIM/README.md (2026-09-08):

# Active acoustic-impedance SPICE project — repaired acceptance path

This project models an externally excited electrodynamic membrane with an active synthetic series impedance. The MCU/DAC generates the requested resistance trajectory; the analog INA149/OPA1656/AD633/OPA548 path performs current-proportional voltage synthesis.

The project does **not** use instantaneous `V(t)/I(t)` as a real-time control variable. Point-wise V/I remains a diagnostic trace only.

## What was repaired

- Fixed impedance is estimated as a complex phasor with fitted DC intercepts.
- Dynamic impedance uses local complex carrier phasors with first-order envelope terms.
- Simulation completion and engineering acceptance are separate fields.
- Failed simulations return exit code 2; failed acceptance returns exit code 3.
- Model-library availability is checked before execution.
- Expensive runs can be split by resistance or modulation frequency.
- Firmware and SPICE control-path audit tools are included.

See `REPAIR_NOTES_20260710.md` and `MCU_CONTROL_CONTRACT.md`.

## Environment

The supplied package contains the project and vendor models, not the ngspice runtime. In the ChatGPT sandbox:

```bash
source /mnt/data/setup_spice_env.sh
```

Python dependencies are listed in `requirements.txt`.

## Structural check and unit tests

```bash
python scripts/check_project.py
python tests/test_validation_metrics.py
```

## One-case smoke regression

From the package root:

```bash
./RUN_QUICK_SMOKE.sh
```

This runs the 7.2-ohm, 1 kHz current-injection case and requires both numerical completion and acceptance pass.

## Fixed resistance signoff, split by resistance

```bash
./RUN_FIXED_SIGNOFF_SPLIT.sh
```

The script runs 1, 5, 7.2, 20, and 100 ohms as separate ngspice jobs, then aggregates them. A final non-zero exit is expected whenever any engineering criterion fails.

Manual example:

```bash
python scripts/run_sweeps.py \
  --clean \
  --results-dir split_fixed_r1 \
  --suite fixed-signoff \
  --case-filter signoff_fixed_r1_ \
  --model-lib official-pure \
  --allow-acceptance-fail \
  --no-plots \
  --no-case-csv
```

## Dynamic signoff, split by modulation frequency

```bash
./RUN_DYNAMIC_SIGNOFF_SPLIT.sh
```

The five jobs use `fm = 10, 30, 100, 300, 1000 Hz` with a 10 kHz carrier. This is intentionally split to isolate convergence and compute cost.

## Reprocess an existing case

```bash
python scripts/postprocess_case.py results_dir/cases/case_name
```

This applies the repaired metrics without rerunning ngspice. Use `--write-derived-csv` or `--plots` only when needed.

## Output interpretation

Primary columns in `all_summary.csv`:

```text
simulation_status
acceptance_status
acceptance_class
acceptance_reasons
ztotal_real_ohm
ztotal_imag_ohm
dynamic_p95_abs_real_rel_error
dynamic_p95_abs_imag_rel
```

Do not use `reff_pointwise` as a primary pass/fail value.

## Firmware audit

No firmware source was included in the supplied archive, so actual MCU behavior is currently `not_auditable`. Run the scanner on the real source tree:

```bash
python scripts/audit_firmware.py /path/to/firmware --json-out firmware_audit.json
```

A static pass is not a substitute for runtime control-flow review, but any instantaneous voltage/current division hit must be reviewed before hardware testing.

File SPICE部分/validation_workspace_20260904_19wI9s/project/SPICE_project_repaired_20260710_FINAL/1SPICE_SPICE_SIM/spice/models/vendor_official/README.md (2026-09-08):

# Official Vendor Model Audit Files

This directory retains the official vendor macro-model source files used for audit:

- `AD633/ad633.cir`
- `OPA548/sbom088c/OPA548.LIB`
- `OPA1656/sbomaw6c/OPA1656.LIB`
- `INA149/sbomc47/ina149.lib`

The corresponding vendor ZIP files are retained where present as source evidence. Redundant vendor example-project files such as schematic projects, symbol libraries, signatures, plots, and PSpice simulation folders have been moved to `archive/vendor_extra/`.

Run from the project root:

```bash
python scripts/prepare_official_models.py
```

The script scans retained `.SUBCKT` definitions, records detected names and pin order, and writes:

```text
spice/models/official_wrapped_models.lib
spice/models/official_model_prepare_report.md
```

Current policy: the official-model path is an audit and wrapper-preparation path. The transient runtime currently uses ngspice-safe surrogate fallback for robust execution. No converted vendor-ngspice copies are retained in the current package.

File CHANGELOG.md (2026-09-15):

# Change log

本文件记录仓库级的重要里程碑；逐项证据仍以对应目录的 Git diff、网表、
日志和 `hypothesis.md` 为准。

## 2026-09-15

- 新增《新板从验收到初步改板操作手册》，把 V8 新板验收、断电/数字域/模拟域测试、固件实现与 SWD 烧录、已知问题复现、R5/R10/Cfb/U4 可逆改板和记录格式整理成可执行流程；明确当前仓库没有可审计的 MCU 固件源码或正式二进制发布物。
- 将H07修正模型改为声明的固定±10/±5 V偏置；3.5586 mΩ、1 Ω、10 Ω三例均完成且TP8晚段0 Vpp。这不覆盖上电顺序。
- 主动审计脚本现在检查每个deck的案例数和数据块数，避免ngspice以0退出但某个瞬态实际中止。
- 收紧E/S动态测量和R5/R10判因表述：DMM只做直流筛查，消振只证明支路是必要条件或参与者。
- 修正“69 mA峰值已解释70 mA持续CC”的错误推断；四个OPA ON复现deck新增平均取电测量。
- 新增证据复核脚本与报告：4组电流、1组105 kHz AC、4组较大启动扰动；固定OFF健康模型仍未复现目标振荡。
- 同步H07/H08后续审计状态：H07固定偏置已完成、上电动态未完成；H08修正使用V8的C27参数。
- 限定命令OFF、J1参与性、反馈比例与历史对话结论的适用范围；实板根因仍待隔离与同步测量确认。

## 2026-09-10

- 新增 `实验还原部分/`：整理实板测试记录、8 个可运行的早期错误/后果复现
  deck，以及针对模型状态盲区的主动审计脚本。
- 原始对话导出、重复 ZIP 和可再生 `.dat` 未纳入 Git；核心 100--110 kHz
  发生机制仍标记为未复现，H07 强故障收敛问题仍标记为未完成。

## 2026-09-08

- 新增 `H12_OPA548_ES_R5动态耦合`：解除固定 OFF 前提，显式加入 R10/TLP185、
  有限 E/S 状态和 J1/PGND 非理想项。23 组机制扫描未产生 100--110 kHz；
  全官方宏在 OPA548 ON 时出现约 453 kHz 组合模态，R5 近似拆除后消失，
  但 TP8 仅约 56 µVpp，不能视为实板 105 kHz 的复现。
- 建立 `故障假设排查_20260908/` 独立审计档案。
- 完成 10 个单一加工/参数故障的官方模型瞬态测试；没有复现 TP8 持续
  100--110 kHz 且超过 10 Vpp 的目标波形。R15 漏装的三种开路代理超时，
  保留为未完成而未计入有效排除。

## 2026-09-07

- 用 TI OPA548/OPA1656 官方宏模型复核 OPA548 关断、输入电源轨钳位、R5
  接入/断开和低 J1 供电条件。
- 在 OPA548 启用、4.7 Ω + 47 nF 输出网络下观察到约 452 kHz、约 140 mVpp
  的 OPA548 输出纹波；移除或减小该电容后消失，但 TP8 仅约 60 µVpp，不能
  视为实板 105 kHz 故障的复现。

## 2026-09-04

- 形成 V8 KiCad 修正版：恢复 R12 生产值、调整 C27/R10、移动 C16、补充
  测试点和 J7，并保留 V7 作为不可覆盖的加工基线。
- 建立局部 OPA548 关断分支、PDN 和 PCB-aware SPICE 排障记录；旧替代模型
  和异常工作点的限制写入对应报告。

## 2026-07-14

- 保存 V7 KiCad 转换版及面向加工的原理图、PCB、BOM/CPL 和 Gerber 记录。

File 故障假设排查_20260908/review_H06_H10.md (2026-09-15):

# Cross-review of H06–H10

**后续纠正（2026-09-15 同步）**：后续发现 H07/H08 的 OPA548 供电节点断链。
H07固定偏置修正版3/3完成且未复现；它不覆盖上电过程。
H08修正版3/3未复现，但 C27 改为 V8 的 10nF。
参见 [主动审计](../实验还原部分/主动审计/ACTIVE_AUDIT_REPORT.md) 和 [更新总表](假设总表.md)。

审查对象是另一 agent 在本目录完成的 H06–H10 独立子目录；本文件只作
交叉检查，不改变其原始 TI 模型。统一目标是 J2/U4 `+/-10 V`、J1/
OPA548 `+/-5 V`、OPA548 OFF、R5=100 ohm、TP8（R5之前）在晚段出现
100--110 kHz 且 >10 Vpp。所有 deck 都只给 1 mV / 2 us 启动 kick，
没有人工105 kHz源。

## 数值与结果核查

| 假设 | 独立改变 | 0.5 ms运行/数据行 | TP8晚段Vpp | 其他工作点/晚段指标 | 交叉结论 |
|---|---|---:|---:|---|---|
| H06 | C39 DNP→22 pF、另作220 pF压力例 | 3/3完成（10084/10121/10131） | 0 V（均） | TP8约19.570 mV；OUT晚段0 Vpp；无零交叉频率 | 有效负结果；C39单独不能产生目标 |
| H07 | 修正供电断链；RAPS=3.5586 mΩ→1 Ω/10 Ω | 固定偏置3/3完成（约10.3k行/例） | 0 V（均） | U4+终值9.9980/9.9902/9.9200 V；无晚振 | 固定偏置有效负结果；RAPS是聚合段，不覆盖上电或定位具体故障 |
| H08 | 修正供电断链；U4正轨C15=100 nF→10 nF/1 fF，C27=10 nF | 固定偏置3/3完成 | 0 V（均） | U4+≈9.998022 V；OUT约316 µVpp | 修正版有效负结果；参数对应V8，不替代V7原板验证 |
| H09 | TP8→OPA548 +IN隔离R5=100 Ω→10 Ω/1 mΩ | 3/3完成（10084/10084/10084） | 0 V（均） | TP8/OPA_P终值≈19.5701 mV；无晚振 | 有效负结果；OFF宏模型下R5单独不起振 |
| H10 | OPA548 OUT→C4串联R12=4.7 Ω→0.47 Ω/1 mΩ | 3/3完成（10084/10084/10084） | 0 V（均） | OUT终值≈−4.637307 V、SNUB晚段0 Vpp；无晚振 | 有效负结果；OFF宏模型下R12单独不起振 |

所有“无频率”均不是把频率当作0 Hz测量，而是晚段没有稳定的过零列，
所以不能定义振荡频率。各日志的 accepted rows 覆盖完整 0.5 ms，晚段
窗0.25--0.5 ms足以容纳约50个100 kHz周期。未发现任何 TP8 >10 Vpp
候选，故没有触发更小步长复核。

## 有效性审查与必要修正

* H06 的 C39 节点确实跨 `R16O--R16N`（VCMD/U4B_N），单独参数修改；
  22 pF 为原理图值误装，220 pF 明确标为压力例。官方 OFF IQ异常已在
  hypothesis.md 中限定，结论不能外推到R10/光耦组合。
* H07修正版保留 U4/J2 两轨的 extracted R/L、C15/C11/C16/C10/C12与J1源阻尼；
  RAPS=1/10 Ω只代表聚合串联段高阻。固定偏置三例都有完整数据。旧PWL上电的10 Ω失败是未完成的另一状态，不得用固定偏置结果代替。
* H08修正版三例有完整数据；旧`H08_test_fixed.log`为失败诊断日志，不应与主结果混读。
* H09 原始 deck曾引用旧 temp 目录的绝对 `fault_fixed_common.inc`；已
  复制同一 common 到 H09 子目录并改为相对 include，`H09_R5_local.log`
  复跑 EXIT 0，三例各10084行、指标与原始log一致。H09因此满足独立
  可复跑要求；绝对官方模型路径仍保留为只读源模型路径。
* H10 是独立拓扑，R12只位于OPA548输出与C4 47 nF之间，R5/R16/C39
  未叠加；三例均完整。其 OUT 的约−4.637 V平坦OFF状态来自官方宏模型，
  不应解释为实板输出级行为。

## 总判断

H06、H09、H10历史单故障与H07/H08修正版均未复现目标振荡。
H07/H08只覆盖固定偏置；H08对应V8的C27；H09/H10受OFF宏模型限制。
结果只支持：在各自明确声明的固定状态中，这些单故障没有产生报告的 TP8 波形；
不能排除实板器件损伤、未建模光耦状态、多个错误叠加或不同频率的实际
电源阻抗。

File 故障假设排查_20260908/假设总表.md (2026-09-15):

# H01-H12 假设总表（主模型入口）

2026-09-15 状态同步：H07/H08 原模型的 OPA548 供电节点断链已在后续主动审计中确认。
H07固定偏置修正版后续完成；以下两行以修正模型的结果为准。
参见 [主动审计](../实验还原部分/主动审计/ACTIVE_AUDIT_REPORT.md) 与
[最新证据复核](../实验还原部分/主动审计/EVIDENCE_REASSESSMENT_20260915.md)。

状态只在对应独立假设目录完成证据后更新；H06-H10 行由另一 agent 的
子目录结果补齐，本文件由本 agent 统一维护，避免两个 agent 同时改总表。

| 编号 | 单一加工/参数错误 | 事前物理预测 | SPICE状态 | TP8晚期结果 | 频率 | 当前判断 |
|---|---|---|---|---:|---:|---|
| H01 | R16 39k→390k（十倍错料） | 闭环增益 40→391，启动幅度增大；可能DC过载，不预期凭空生成105k | 已完成 | 0 Vpp | 无 | 本模型未复现；无持续振荡 |
| H02 | R16漏装，1T等效，铜线仍导通 | 反馈断开，U4B退化开环，预期近正轨DC饱和 | 已完成 | 0 Vpp；约8.903 V DC | 无 | DC失反馈，不是振荡；本模型未复现目标 |
| H03 | R15低值错料（首选100Ω） | 噪声增益 40→391；启动放大，可能饱和 | 已完成，EXIT0 | 0 Vpp；晚段约0.191 V DC | 无 | 本模型未复现；仅启动放大 |
| H04 | R15漏装，1T等效 | 反馈网络趋近电压跟随器，增益约1；预期稳定 | 未完成，1T/1G均timeout | N/A（无晚段数据） | N/A | 不适用当前瞬态数值条件，不作排除 |
| H05 | U4 pin5/6/7区域焊桥候选 | 先核脚位；pin5→7正反馈跨过pin6不邻接，改测最近pin6→7桥（负反馈旁路） | 已完成，EXIT0 | 0 Vpp；晚段约0.489 mV DC | 无 | 本模型未复现；最近邻桥稳定 |
| H06 | C39误装22pF/220pF | 反馈支路并联电容改变幅相；不应自带105k源 | 已完成，3/3 EXIT0 | 0 Vpp；约19.570 mV DC | 无 | 本模型未复现；不能排除组合故障 |
| H07 | U4正轨串联RAPS高阻（1Ω/10Ω） | U4+供电阻抗升高，可能轨纹波/偏置 | 修正模型固定偏置3/3完成 | 三例TP8晚段0 Vpp；U4+约9.998/9.990/9.920 V | 无 | 固定偏置下未复现；不覆盖上电顺序、实际电源或定位具体FB1/焊点 |
| H08 | U4正轨C15 100n→10n/1fF | 高频去耦变差，可能电源耦合 | 修正供电与 C27=10nF 后三例有结果 | 三例 TP8 0 Vpp | 无目标振荡 | 修正版未复现；C27 已是 V8 值，不能直接替代 V7 原板结论 |
| H09 | R5 100Ω→10Ω/1mΩ | OPA548输入隔离/钳位负载变化 | 已完成，3/3 EXIT0 | 0 Vpp；TP8约19.570 mV DC | 无 | 本模型未复现；OFF限制 |
| H10 | R12 4.7Ω→0.47Ω/1mΩ | 47nF负载阻尼降低，可能输出级Q升高 | 已完成，3/3 EXIT0 | 0 Vpp；OUT约−4.637 V DC | 无 | 本模型未复现；OFF限制 |
| H11 | U4 pin5↔pin6相邻输入焊桥 | 输入差分短路，预期DC偏置/饱和，不是正反馈 | 已完成，EXIT0 | 0 Vpp；约8.897 V DC | 无 | 本模型未复现；近轨DC |

| H12 | OPA548 E/S + R10/TLP185 + R5 动态耦合（组合机制） | 解除固定 OFF 前提；检查 E/S 状态是否打开 U4B–R5–OPA548 高频路径 | 已完成：23 组快速扫描 + 全官方关键对照 | V7-like ON 时 TP8≈55.7 µVpp；R5≈开路后 0 | ≈453.3 kHz（非105 kHz） | 发现需 R5 且需 OPA548 ON 的组合模态；未复现实板 100–110 kHz |

统一场景：H01–H11 使用 J2/U4 `+/-10 V`、J1/OPA548 `+/-5 V`、OPA548 OFF、
R5 100Ω，TP8 为 R5 前节点；官方 OFF IQ 异常始终是模型限制。H12 是明确的
例外：它解除固定 OFF 前提以审计 E/S 状态与 R5 的组合动态。

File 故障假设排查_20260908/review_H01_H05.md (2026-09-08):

# H01–H05 只读交叉审查

## 总结结论

H01、H02、H03、H05 的 deck 都保持了“只改一个电阻/连接”的原则，并在 `tran 0.05u 0.5m` 后取得约 10k 数据行；它们的晚期 TP8 Vpp=0 结论在当前官方宏模型和固定轨压下有效。H04 不应计入“本模型未复现”：1TΩ、1GΩ 代理及真正删去 R15 的 deck 都只到初始工作点，没有 0.5ms 数据。H05 实际测试的是相邻 pin6↔pin7 负反馈旁路，不是所称的 pin5↔pin7 正反馈；不能用它排除输入/输出正反馈桥。

## 物理拓扑核对

- 原理图 R16=39.0k、R0805 在 `KICAD部分/正弦电阻V8_KiCad10.0.4_稳定性修正版_2026-09-04/project.kicad_sch:36961-36984`；PCB 焊盘为 VCMD↔U4B_N（`project.kicad_pcb:18930-18942`）。R15=1.000k、R0805 在 `project.kicad_sch:25495-25518`。
- U4 是 OPA1656 SOIC-8（`project.kicad_pcb:19542-19559`），pin5=MUL_RAW、pin6=U4B_N、pin7=VCMD、pin8=ANA_P（`project.kicad_pcb:19987-20013`）。故 pin6↔7 是最近邻反馈旁路；pin5↔7 跨过 pin6，若有锡团更可能同时影响三脚。
- 实际提取网表把 R5=100Ω 和 R12=4.7Ω/C4=47nF 保留在 `PCB_AWARE_full_extracted_loop.cir:897-910`；本轮 H01–H05 公共 deck 的 R5、输出网络和 C39 DNP 等效在 `H01.../fault_fixed_common.inc:40-61`。

## 分项审查

| 项目 | 证据与结果 | 审查判定 |
|---|---|---|
| H01 R16→390k | `fixed_H01_R16_390k.cir:1-7` 仅改 R16；log `:452-465` 有 10079 行，TP8 late=0.1912965V、0Vpp，早期约 0.191–0.511V | 单故障和收敛证据有效。391 倍低频增益预测合理，但早期放大不是持续振荡；不能把 OPA548 OUT≈−4.637V 的 OFF 状态当成 TP8 饱和。 |
| H02 R16 漏装 | deck `fixed_H02_R16_1T.cir:1-9` 保留铜路径，只以 1TΩ 代表电阻体开路；log `:452-465` 有 10083 行，TP8≈8.903438V、late=0Vpp | 可作为“失反馈近正轨 DC”证据，不是振荡证据。1TΩ是近似开路而非严格删元件，但泄漏约 pA，物理判断基本不受影响。 |
| H03 R15→100Ω | deck `fixed_H03_R15_100R.cir:1-7` 与 common `fault_r15_common.inc:40-49` 只改 R15；log `:452-468` 有 10090 行，TP8 late=0Vpp，早期约 0.191–0.522V | 单故障、幅度/晚窗指标有效。它与 H01 都给约391噪声增益，但分别是不同加工错误；没有理由把启动放大外推成105kHz。 |
| H04 R15 漏装 | 严格 deck `fixed_H04_R15_removed.cir:1-10` 真的没有 R15 元件；common `fault_r15_open_common.inc:40-48` 也没有 R15。1T、1G、strict 三个 log 各约450行，仅有初始工作点，无 `No. of Data Rows`/晚窗 | 必须标 N/A/未完成。timeout 或初始化卡住不支持“稳定”或“未复现”。1G 代理已经失败，继续只扫高阻值没有信息增益；需另建经验证可收敛的开路/输入偏置表示，或保持未判定。 |
| H05 U4B桥 | deck `fixed_H05_pin6_pin7_bridge.cir:1-10` 仅增加 `RBRIDGE_U4N_U4O=1mΩ`；log `:452-468` 有10163行，TP8≈0.489mV、late=0Vpp | 该 pin6↔7 单桥测试有效，结果符合负反馈旁路/近单位增益。它没有测试 pin5↔7 或 pin5/6/7 三脚污染，不能写成“输入/输出正反馈焊桥已排除”。 |

## 共同模型边界和可能的假阴性

公共 deck 将 J2/U4、J1/OPA548 直接接理想电压源（`fault_fixed_common.inc:8-13`），并用理想 `VES=V−+0.6V` 表示 OFF；没有 R10/TLP185 的集电极路径、AGND/PGND 铜阻抗或 J1/J2 的 L/C 电源网络。它适合比较局部 R15/R16/焊桥在官方 OPA548/OPA1656 宏模型中的必要性，不适合排除“供电阻抗+E/S切换+地网”联合作用。单次 1mV/2µs kick（各 deck 的 `tran` 前源定义及 `:7-10`）能激发自启动的确定性振荡，但不能代表实板噪声/电源纹波；晚期 Vpp=0 只说明该激励和模型未维持振荡。

所有 H01/H02/H03/H05 的 OPA548 OFF 电流都明显偏离数据手册 shutdown IQ，应与波形结论分离。H02 的 8.9V、H05 的0.489mV是工作点状态，不可误报为 >10Vpp。由于这些 late Vpp 都严格为0，未做频率拟合是合理的；H04 没有波形，频率必须写 N/A。

## 发给执行方的修改请求

1. H04 保持“未完成/不适用当前瞬态数值条件”，不要放入“已排除”或“本模型未复现”计数。若要完成，增加一个有收敛证据、并以开路 DC/输入偏置为边界的独立 proxy；任何数值泄漏都要与严格 open 分开标注。
2. 将 H05 标题/总表描述限定为“pin6↔pin7 最近邻负反馈桥”，或另跑一个单独的 pin5/6/7 三脚污染 case。不得以 H05 结果排除 pin5↔pin7 正反馈；H11 的 pin5↔pin6 也不能替代该未测变体。
3. 主分析引用 H01/H02/H03/H05 时加上“理想轨压、理想 E/S、无光耦动态”的适用范围；不要用 OFF 电源电流作物理证据，也不要把 DC 近轨或早期 kick 当作目标 100–110kHz 振荡。

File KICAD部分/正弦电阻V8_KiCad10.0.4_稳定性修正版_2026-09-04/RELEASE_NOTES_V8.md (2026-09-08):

# 正弦电阻 V8 稳定性修正版

日期：2026-09-04  
KiCad：10.0.4  
基线：`V7_KiCad10.0.4_校正转换版`（原工程和 2026-07-14 量产压缩包未覆盖）

## 已实施修正

1. **R12 恢复为量产 2512、4.7 Ω/2 W**
   - 转换工程错用 0805；V8 根据 2026-07-14 飞针文件重建焊盘。
   - 中心 `(154.354, 89.740) mm`；焊盘中心距 `6.132576 mm`；焊盘 `1.282522 x 3.456 mm`。
   - 1 脚 DRV，2 脚 SNUB_MID。
2. **C27: 10 pF → 10 nF**
   - 保留原有跨 OPA548 V+/V- 的近端位置，改为数据手册推荐的 0.01 µF。
3. **R10: 100 kΩ → 6.8 kΩ**
   - 按 OPA548 E/S 最大 70 µA 计算，禁止态压差约 0.476 V，低于 0.8 V 禁止阈值。
   - 这是最坏条件裕量修正，不表示已证明 R10 是 100–110 kHz 振荡根因。
4. **C16 移至 U4 负电源脚附近**
   - ANA_N 去耦路径由约 28 mm 缩短至约 4 mm；C15 保持原位，因两组候选位置均无法无错布线。
5. **TP1–TP20 改为真实镀通孔测试点**
   - 1.6 mm 焊盘 / 0.7 mm 钻孔；TP11 小幅移位避开 MUL_RAW。
6. **J7 SWD 改为真实 1.27 mm 镀通孔接口**
   - 1.05 mm 焊盘 / 0.65 mm 钻孔；网络顺序保持 V3V3, SWDIO, SWCLK, NRST, DGND。
7. **清理铜箔问题**
   - J1 PWR_P 改为实心铺铜连接；删除 GPIO_SPARE8 无用过孔和 SERVO_INT_N 悬空短桩。
8. **增加双面贴装基准点**
   - 顶面 FID1–FID3、底面 FID4–FID6；1 mm 铜盘、2 mm 阻焊开窗、周围 0.6 mm 无其他铜，排除 BOM/CPL。

## 必须的装配/程序约束

- J5 三端子不内部短接：默认必须跨接 **1–2** 使用 MCU 的 VK_MCU；外部控制时跨接 **2–3**。J5-2 不得悬空。
- STM32 PB8 共用 BOOT0/I2C_SCL，不增加硬件强下拉。生产编程必须写入并回读 OPTR `0xFBEFF8AA`；`0xFFEFF8AA` 会进入系统 ROM。
- SWD 量产速率使用 **1 MHz**，并同时接 DGND 和 NRST。

## 验证状态

- PCB DRC：0 个未连接；0 个电气/制造类错误。
- 仍有 59 条转换工程的图形警告：41 条丝印压阻焊、15 条庭院重叠、3 条丝印互叠。它们不构成短路或断路，Gerber 导出应启用丝印减阻焊。
- ERC 仍为转换基线的 436 项（288 pin-to-pin、105 线端点、27 off-grid、16 pin-not-driven），类型和数量与 V8 修改前完全相同。这是 EasyEDA 转换图元/线端属性问题，PCB DRC 的 schematic parity 为 0，但不应声称原理图 ERC 已清零。
- V8 制造规则对齐已量产几何：普通间距 0.100 mm、孔到铜 0.190 mm、过孔孔环 0.089 mm。这是对已验证工艺的准确描述，不是裕量提升。

## 尚未证明、不应声称已修复的问题

在不人为注入 105 kHz、不使用虚假兆欧接触、不人为添加极点的条件下，现有 SPICE 仍不能自然复现“TP7 小、TP8 大的 100–110 kHz”。官方 OPA1656 全板 PDN 模型曾在 `2.22e-10 s` 因步长过小停止，该运行不能作为证据。

因此，发布前仍需实板门槛：

1. 拆除 R5，在相同供电/负载/探头条件下同时记录 TP7 和 TP8；再恢复 R5 复测。
2. 如差异仍在，对 U4 做原件→新件→原件回装 A/B，禁止改变其他变量。
3. 只有重现条件固定后，才评估 C14/C37–C41 的补偿值；不将 22/47/220 pF 之一预先当作根因修复。

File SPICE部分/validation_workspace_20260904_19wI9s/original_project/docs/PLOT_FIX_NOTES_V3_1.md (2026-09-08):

# v3.1 plot-axis repair notes

This update fixes the problem where many generated figures looked like a nearly flat straight line because one diagnostic trace or startup spike dominated the axis range.

## What changed

1. **Robust y-limits for all plot panels**
   - Plot limits now use percentile-based scaling rather than raw min/max.
   - Rare startup spikes and point-wise `V/I` explosions no longer compress the useful waveform into a line.
   - Raw CSV values and summary metrics are not clipped; clipping is only for figure display.

2. **Tail-only zoom figures**
   - Every case now writes two figures:
     - `<case>.png`: full overview with the tail-start marker.
     - `<case>_tail.png`: steady-state zoom window after soft-start.
   - The tail window is selected from the case frequencies so 1000 Hz and 5000 Hz traces no longer appear as a dense block or straight line.

3. **Safer Reff plotting**
   - `Reff pointwise` remains a diagnostic only.
   - It is masked around current zero crossings and clipped for plot display as:
     `Reff pointwise, masked/interp/clipped`.
   - Use `synerr`, `cmderr`, `followerr`, and `reff_fit_tail_ohm` for conclusions.

4. **Replot without rerunning ngspice**
   - Added `scripts/replot_existing_results.py`.
   - It regenerates PNGs from existing CSV files.

## Commands

Run full simulation and generate repaired figures:

```bash
python scripts/run_sweeps.py --clean
```

Regenerate figures from existing results without ngspice:

```bash
python scripts/replot_existing_results.py
```

Regenerate only injection-case figures:

```bash
python scripts/replot_existing_results.py --case-filter einj
```

## Interpretation reminder

The repaired plots are intended to make the useful waveform visible. They do not change the physics or the numeric metrics. For final judgment, prioritize:

- `synerr_norm_rms_tail`
- `synerr_rms_tail_v`
- `cmderr_rms_tail_v`
- `follow_error_rms_tail_v`
- `reff_fit_tail_ohm` for fixed-resistance injection tests
- `ilim_ratio_tail_pk`
- `xmax_ratio_pk`

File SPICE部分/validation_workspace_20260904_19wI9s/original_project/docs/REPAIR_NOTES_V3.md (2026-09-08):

# Repair notes v3

## Motivation

The v2 project repaired the major wrong-polarity output-current-source issue in the surrogate amplifier macromodels. The uploaded v2 results showed that the false 1.52 A current-limit state disappeared. However, the summary still reported large `Reff` errors in some cases.

Manual inspection showed that those large errors were dominated by the ratio

```text
Reff = Re + V(SPK)/Iport
```

near current zero-crossings. The ratio is numerically ill-conditioned when `Iport` is small and is not a reliable primary pass/fail metric for an acoustically excited, lightly driven system.

## v3 fixes

### 1. Voltage-domain synthesis error

The primary error is now

```text
synerr = V(SPK) - Rx_command(t) * Iport
```

This directly tests the intended synthetic impedance relation without dividing by a near-zero current.

In the full component template:

```spice
B_SYNERR SYNERR 0 V = {V(SPK) - V(RXNODE)*V(IPORT)}
B_CMDERR CMDERR 0 V = {V(VCMD) - V(RXNODE)*V(IPORT)}
```

### 2. Least-squares impedance fit

For fixed-R cases, v3 computes

```text
Rx_fit = sum(VSPK*Iport) / sum(Iport^2)
Reff_fit = Re + Rx_fit
```

This is the correct scalar fit for `VSPK ≈ Rx*Iport` and avoids zero-crossing singularities.

### 3. Masked point-wise Reff

Point-wise `V/I` is retained for plots and diagnostics, but only when

```text
abs(Iport) >= max(50 µA, 5% of tail peak current)
```

The valid fraction is reported as `reff_pointwise_valid_fraction_tail`.

### 4. Soft-start

The target command is now separated into:

- `RDES`: the requested target profile.
- `RXDES`: requested external synthetic impedance.
- `RXNODE`: actual command sent to the analog multiplier after soft-start and filter.
- `RTARGET`: `Re + RXNODE`, the command used for evaluation.

The command path ramps external `Rx` from zero to target:

```spice
BVK_RAW VK_RAW 0 V = {soft(time)*(3.3*V(DAC_R)-0.62)}
```

The acoustic pressure source and electrical injection source are also soft-ramped.

### 5. Electrical current-injection tests

A soft-ramped current source is added at the SPK node:

```spice
B_EINJ 0 SPK I = {soft(time)*ItestAmp*sin(TWOPI*ItestFreq*time)}
```

With `Pamp=0`, these cases directly verify the synthetic impedance loop under a known electrical stimulus.

## Acceptance criteria suggested for v3

For fixed electrical injection tests:

- `abs(reff_fit_err_vs_tail_mean_ohm)` should be small compared with the target.
- `synerr_norm_rms_tail` should be low.
- `ilim_ratio_tail_pk` should be comfortably below 1.
- `opa548_vsat_max_v` should remain 0 or near 0.

For acoustic modulation tests:

- Use `synerr_rms_tail_v` and `synerr_norm_rms_tail` rather than raw point-wise Reff.
- Inspect the plot panel showing `SPK`, `VCMD`, and `Rx*Iport`.

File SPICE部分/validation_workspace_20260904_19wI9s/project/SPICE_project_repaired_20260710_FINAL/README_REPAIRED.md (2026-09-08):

# Repaired active acoustic-impedance SPICE project

This package repairs the simulation acceptance path and documents the MCU control contract. It does not claim that the full 1-100 ohm, 10-1000 Hz dynamic target has passed.

## Quick structural and numerical smoke test

```bash
source /mnt/data/setup_spice_env.sh
./RUN_QUICK_SMOKE.sh
```

## Split fixed-resistance signoff

```bash
source /mnt/data/setup_spice_env.sh
./RUN_FIXED_SIGNOFF_SPLIT.sh
```

Each resistance is simulated separately. The final aggregation returns non-zero if any engineering criterion fails.

## Split dynamic signoff

```bash
source /mnt/data/setup_spice_env.sh
./RUN_DYNAMIC_SIGNOFF_SPLIT.sh
```

Each modulation frequency is simulated separately to limit compute and isolate convergence failures.

## Firmware audit

The supplied archive contains no MCU source. Run the scanner on the real firmware tree:

```bash
python 1SPICE_SPICE_SIM/scripts/audit_firmware.py /path/to/stm32/project --json-out firmware_audit.json
```

No firmware source means `not_auditable`, not pass.

See:

- `1SPICE_SPICE_SIM/REPAIR_NOTES_20260710.md`
- `1SPICE_SPICE_SIM/MCU_CONTROL_CONTRACT.md`
- `1SPICE_SPICE_SIM/validation_policy.json` after a run

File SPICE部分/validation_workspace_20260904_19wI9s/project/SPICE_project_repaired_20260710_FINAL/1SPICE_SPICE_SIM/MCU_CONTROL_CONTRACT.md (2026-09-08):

# MCU control contract

## Required runtime role

The MCU/DAC is permitted to generate only the bounded target-resistance trajectory:

```text
Rtarget(t) in [1 ohm, 100 ohm]
Rx(t) = Rtarget(t) - Re_est
```

The real-time impedance synthesis path is:

```text
measured current -> analog scale -> AD633 multiply by Rx command -> VCMD -> OPA548
```

The firmware must not implement a fast feedback loop based on instantaneous:

```text
R_est(t) = Vspk(t) / Iport(t)
```

because Iport crosses zero, the port impedance is complex, and division noise/phase error can enter the power loop.

## Permitted MCU measurements

The MCU may sample voltage and current for telemetry, logging, slow calibration, RMS protection, temperature estimation, and offline/slow lock-in impedance estimation. Any division must occur only after coherent windowing or complex phasor extraction, with current-amplitude qualification.

## Required protections

Firmware should independently supervise current, output saturation, DC current, temperature/power integral, target bounds, and target slew rate. A protection decision must not be based on a single instantaneous V/I sample.

## Audit status of supplied package

No C/C++/assembly/STM32 project files were supplied. Therefore the actual MCU firmware is not auditable from this archive. `scripts/audit_firmware.py` is included for the firmware source tree when available. A `not_auditable` result is not a pass.

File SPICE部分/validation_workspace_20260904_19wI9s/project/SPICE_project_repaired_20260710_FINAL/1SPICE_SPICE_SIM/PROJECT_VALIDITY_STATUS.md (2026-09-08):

# Project Validity Status

Date: 2026-06-17

## Current Valid Scope

This project is valid as a surrogate-based ngspice transient validation of the active synthesized impedance / negative-impedance acoustic membrane concept.

The retained numerical sweep results in `results/all_summary.csv` demonstrate the behavior of the repaired ngspice-safe surrogate macro model chain under the recorded sweep conditions. They are not claimed to be pure TI/ADI/STM vendor-macro transient simulation results.

## Interpretation Boundary for `results/all_summary.csv`

The summary table includes explicit provenance columns:

- `model_lib`
- `runtime_model_policy`

For the current retained results:

- `model_lib = official`
- `runtime_model_policy = official_audit_with_ngspice_surrogate_fallback`

This means the run used the official-model preparation and wrapper path, while the transient execution used ngspice-safe surrogate fallback for robust execution. The existing numeric columns should be interpreted as surrogate-model validation results, not as pure official vendor macro results.

## Official-Model Path: Completed

The project currently supports an official-model audit path that can:

- scan retained official/vendor model files;
- identify relevant `.SUBCKT` names;
- record pin-order assumptions in `spice/models/official_model_pin_map.json`;
- generate `spice/models/official_wrapped_models.lib`;
- generate write-only official-path netlists with `scripts/run_sweeps.py --model-lib official`;
- document when ngspice-safe surrogate fallback is used for transient robustness.

The vendor macro files are retained for audit and future replacement work.

## Official-Model Path: Not Yet Completed

The project has not completed a full transient sweep proven to run only on pure official TI/ADI/STM vendor macro models.

The current wrapper path intentionally keeps `ngspice_fallback_to_surrogate` enabled for devices whose vendor PSpice macro syntax or convergence behavior is not yet robust under local ngspice transient execution.

Do not describe the current numerical results as:

- pure official macro transient sweep results;
- full vendor macro validation;
- PCBA-ready proof from vendor macromodels alone.

## PCBA / KiCad / Quilter / Hardware Limits

The present results are useful for validating the active synthesized impedance concept and for preserving a reproducible ngspice experiment record. They are not a substitute for:

- vendor-macro-only transient convergence signoff;
- device thermal and current-limit validation against datasheets;
- PCB parasitic, layout, stability, and protection analysis;
- KiCad / Quilter implementation verification;
- bench measurements on the final amplifier, sensing, and loudspeaker hardware.

Before PCBA release or hardware claims, the official vendor macro path should be completed without surrogate fallback where possible, and the same sweep set should be rerun with logs and provenance preserved.

## Dynamic Validation Update

On 2026-06-17, a full 34-case dynamic transient rerun was completed in a temporary validation copy of the cleaned project. The rerun used:

```text
python scripts\run_sweeps.py --clean --model-lib official
```

The rerun produced 34 rows with `status = ok`, `model_lib = official`, and `runtime_model_policy = official_audit_with_ngspice_surrogate_fallback`. No new failure rows were produced, and no fatal ngspice log patterns were found in the rerun case logs.

This dynamic rerun supports the current surrogate-based transient validation claim. It still does not establish pure official vendor-macro transient validation, because the official-model path intentionally uses ngspice-safe surrogate fallback for robust execution.

## Conclusion

This project is valid as a surrogate-based ngspice transient validation of the active synthesized impedance concept. The included official vendor macro files are audited and mapped, but the current dynamic sweep results are not claimed to be pure vendor-macro transient results. The official-model path currently uses an ngspice-safe surrogate fallback for robust transient execution.

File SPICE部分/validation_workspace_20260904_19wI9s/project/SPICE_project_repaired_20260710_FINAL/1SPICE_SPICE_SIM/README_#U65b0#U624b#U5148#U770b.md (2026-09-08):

# 新手先看：1SPICE_SPICE_SIM 怎么用

这个目录是主动声学阻抗 / 负阻抗电声膜项目的 SPICE 仿真包。

一句话结论：**这里用于验证“电路能否合成 1-100 ohm 等效电阻，并在 10-1000 Hz 变化下保持稳定”；当前结果是 ngspice 代理模型验证，不是最终硬件签核。**

## 1. 先看哪些文件

建议按这个顺序看：

1. `README_新手先看.md`  
   当前这份中文入口说明。

2. `PROJECT_VALIDITY_STATUS.md`  
   当前项目可信边界。这里会说明哪些结论能用、哪些不能当最终签核。

3. `docs/project_notes/SPICE完整化改进要求_2026-06-24.md`  
   后续要把 SPICE 包做到“完整”的改进清单和验收标准。

4. `docs/project_notes/SPICE_RUNTIME_TEST_REPORT.md`  
   2026-06-20 的运行测试记录，说明 smoke test 怎么跑通。

5. `docs/DYNAMIC_VALIDATION_REPORT.md` 和 `docs/FINAL_CONSOLE_SUMMARY.md`  
   早期动态验证和汇总结论。

## 2. 每个文件夹是干什么的

| 文件夹 | 用途 | 新手建议 |
|---|---|---|
| `scripts/` | 运行、检查、画图、准备模型的 Python 脚本 | 要重新仿真时用这里 |
| `spice/` | SPICE 电路、模型、官方模型包装 | 不熟悉时不要手改 |
| `results/` | 当前仿真输出 | 注意当前可能只是 smoke test 结果 |
| `docs/` | 说明、报告、模型计划、指标说明 | 查背景和结论 |
| `docs/project_notes/` | 从根目录整理下来的专项说明 | 查历史说明和完整化要求 |
| `archive/` | 历史、备份、旧日志、临时脚本、源码包 | 只看不用于当前运行 |

## 3. 最常用命令

先进入目录：

```powershell
cd C:\Users\Administrator\Documents\2SPICE\1SPICE_SPICE_SIM
```

检查项目是否完整：

```powershell
python scripts\check_project.py
```

设置 ngspice 路径：

```powershell
$env:NGSPICE_BIN="C:\Users\Administrator\Documents\Spice64\bin\ngspice_con.exe"
```

重新跑完整默认 sweep：

```powershell
python scripts\run_sweeps.py --clean
```

重新跑完整增强 sweep，包含默认 case、寄生 case、异常 case：

```powershell
python scripts\run_sweeps.py --clean --suite complete --model-lib official
```

只生成 netlist，不运行 ngspice：

```powershell
python scripts\run_sweeps.py --clean --write-only
```

只跑电注入相关 case：

```powershell
python scripts\run_sweeps.py --clean --case-filter einj
```

只跑 smoke test 时，必须输出到 `results_smoke/`，避免覆盖完整结果：

```powershell
python scripts\run_sweeps.py --clean --smoke --case-filter full_einj_fixed_r1_f1000
```

如果只需要根据现有 `results/all_summary.csv` 重新生成报告，不重跑仿真：

```powershell
python scripts\generate_completion_reports.py --results-dir results --suite complete
```

## 4. 当前结果怎么理解

当前已经有正向证据：

- `Rtarget=1 ohm` 的关键负阻抗目标在代理模型里跑通。
- `Rtarget=7.2 ohm` 的普通等效电阻点拟合非常接近。
- 历史报告记录过 34 个动态 case 全部成功。

但要注意：

- 当前 `results/all_summary.csv` 可能被 smoke test 覆盖，不一定代表完整 sweep。
- 结果里如果看到 `gmin/source stepping failed`，要继续看后面是否有 `Transient op finished successfully`。如果有，它通常只是 ngspice 初始工作点警告，不等于仿真失败。
- 当前结果不能直接替代 PCB 寄生、OPA548 热、RSH1 Kelvin 误差、供电回灌和真实扬声器台架测试。

## 5. 不要弄错的地方

- 不要把 `archive/` 当成当前运行目录。
- 不要只看 `results/all_summary.csv` 就下结论，因为它可能被单个 smoke test 覆盖。
- 不要把当前代理模型结果写成“纯厂商宏模型已经完整验证”。
- 不要把 `results/cases/*/Reff pointwise` 图当主要验收依据；主要看 `reff_fit_tail_ohm`、`synerr_norm_rms_tail`、`ilim_ratio_tail_pk`、`xmax_ratio_pk`。
- 不要随手改 `spice/models/` 里的模型文件；先复制或新建测试分支。

## 6. 现在最该补的工作

当前已经补了完整增强 sweep 能力：

- `--suite complete`：默认 case + 寄生 case + 异常 case
- `--smoke`：把 smoke test 输出到 `results_smoke/`
- `thermal_power_summary.csv`：热功率摘要
- `results/reports/`：完整运行、模型来源、寄生、异常报告
- `docs/project_notes/外部技能参考_2026-06-24.md`：外部技能仓库参考原则

后续按工期优先级：

1. 重新跑完整默认 sweep，并保留全部 case 的 `_summary.json`。
2. 防止 smoke test 覆盖完整 `results/all_summary.csv`，必要时用 `results_smoke/`。
3. 补 PCB/线缆/RSH1 寄生模型。
4. 补 OPA548 热功率和供电回灌评估。
5. 补异常工况：`VK` 卡死、扬声器开路/短路、RSH1 采样异常。

更详细的要求看：

`docs/project_notes/SPICE完整化改进要求_2026-06-24.md`

## 7. 当前一句话状态

这个 SPICE 包现在可以作为“概念验证和样机方向判断”的依据；如果要升级成“支持 PCB 硬件签核的完整仿真证据”，还需要补完整 sweep、模型来源、寄生、热、保护和异常工况。

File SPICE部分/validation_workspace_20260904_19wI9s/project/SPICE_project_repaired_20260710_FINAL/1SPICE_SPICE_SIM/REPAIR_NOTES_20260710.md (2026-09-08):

# SPICE acceptance and control-path repair — 2026-07-10

## Repaired defects

1. The old fixed-resistance estimator used a zero-intercept scalar slope, `sum(v*i)/sum(i*i)`. Device-macro DC offsets could corrupt a correct 7.2-ohm result into approximately 0.057 ohm.
2. Fixed impedance now uses separate affine sinusoidal fits for voltage and current, including DC intercepts, and reports complex total impedance.
3. Dynamic current-injection cases now use local complex carrier fits with first-order I/Q envelope terms. Instantaneous V/I remains diagnostic only.
4. `simulation_status` and `acceptance_status` are separate. A completed ngspice run is no longer reported as an engineering pass.
5. The runner returns exit code 2 for simulation/post-processing failures and exit code 3 for acceptance failures. `--allow-acceptance-fail` is available only for exploratory sweeps.
6. `simulation_failures.csv`, `acceptance_failures.csv`, and `validation_policy.json` are generated.
7. Missing model-library paths are detected before simulation. The packaged pure-vendor wrapper is the default.
8. Expensive regressions can be split by fixed resistance or modulation frequency. `--no-plots` and `--no-case-csv` reduce post-processing cost.
9. Project/control-path and firmware audit scripts were added.

## Verified repaired results

Pure-vendor 1 mA, 1 kHz electrical-injection checks:

| Target | Complex total impedance | Acceptance |
|---:|---:|---|
| 1 ohm | approximately 1.0537 + j0.3418 ohm | fail: reactive component exceeds policy |
| 7.2 ohm | approximately 7.2487 - j0.00787 ohm | pass |
| 100 ohm | approximately 98.8159 - j5.6054 ohm | fail: reactive component exceeds policy |

The failures above are engineering results, not script failures. The repaired scripts distinguish them correctly.

A dynamic 1-100-ohm, fm=100 Hz, 1 kHz-carrier case was reprocessed with the repaired local complex estimator and failed with large p95 real and imaginary relative errors. This confirms that the previous dynamic-signoff limitation remains; the repair does not hide it.

## Exit codes

```text
0: all selected simulations and acceptance checks passed
2: ngspice or post-processing failure
3: simulations completed, but one or more acceptance checks failed
4: firmware audit requested but no firmware source was supplied
```

## Authoritative outputs

Use `all_summary.csv` columns:

```text
simulation_status
acceptance_status
acceptance_class
acceptance_reasons
ztotal_real_ohm
ztotal_imag_ohm
dynamic_p95_abs_real_rel_error
dynamic_p95_abs_imag_rel
```

Do not use point-wise `reff_pointwise` or netlist `B_REFF` as a primary pass/fail metric.

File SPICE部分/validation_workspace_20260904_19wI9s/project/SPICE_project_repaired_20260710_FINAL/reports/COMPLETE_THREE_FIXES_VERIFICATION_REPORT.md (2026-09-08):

# Pure vendor 三项修复仿真完成报告

本轮在 `/mnt/data/1SPICE_SPICE_SIM` 中完成并验证三项修复：

1. OPA548 RCL 接法修复：`RCL ILIM N18 __RCL__`。
2. Current-sense offset trim：在 INA149 后、OPA1656 x50 电流检测级前增加 input-referred trim，形式为 `VSENSE_TRIM = VSENSE - VOS_I_TRIM*FIXW(RTARGET)`。
3. 慢速 DC servo：对 `IPORT` 做低通，向 AD633 的 `Z` 端注入限幅校正，形式为 `ZSERVO = limit(Kdc*FIXW(RTARGET)*LPF(IPORT), ±limit)`。

所有验证均使用 `official_pure_rawps_wrapped_models.lib`，即 TI/ADI raw vendor macromodel wrapper，加 `.spiceinit: set ngbehavior=ps`，没有器件级 surrogate fallback。

## 实际已写入工程的核心网表

```spice
RCL ILIM N18 __RCL__
B_VSENSE_TRIM VSENSE_TRIM 0 V = {V(VSENSE)-VOS_I_TRIM*FIXW(V(RTARGET))}
XU_OPA_ISENSE VSENSE_TRIM NFB_A ISIG P15 N15 OPA1656_NG_SURR
R_IPDC IPORT IPDC {DC_SERVO_R}
C_IPDC IPDC 0 {DC_SERVO_C} IC=0
B_ZSERVO ZSERVO 0 V = {limit(DC_SERVO_ENABLE*DC_SERVO_K*FIXW(V(RTARGET))*V(IPDC), -DC_SERVO_LIMIT, DC_SERVO_LIMIT)}
XU_MULT ISIG 0 VK 0 N15 ZSERVO MUL P15 AD633_NG_SURR
```

其中调度权重：

```spice
.func FIXW(r) {FIX_SCHED_ENABLE*min(max((FIX_SCHED_OFF-r)/max(FIX_SCHED_OFF-FIX_SCHED_FULL,1e-9),0),1) + (1-FIX_SCHED_ENABLE)}
```

最终验证参数：

```text
VOS_I_TRIM = -0.496092 mV
DC_SERVO_FC = 2 Hz
DC_SERVO_K = 0.2 V/A
DC_SERVO_LIMIT = 0.5 V
FIX_SCHED_ENABLE = 1
FIX_SCHED_FULL = 7.2 Ω
FIX_SCHED_OFF = 30 Ω
```

注意：`VOS_I_TRIM` 为负号，是因为在本工程连接方向下，等效动作是给 current-sense 非反相输入增加约 0.496 mV。

## 关键结论

- RCL 修复已确认有效，是必须保留的硬修复。
- Current-sense trim 对 `Rtarget≈1Ω` 的 DC 偏置显著有效：`|Iport_dc|` 从约 41.99 mA 降到约 16.84 mA。
- 加入慢速 DC servo 后，`Rtarget≈1Ω` 的 `|Iport_dc|` 进一步降到约 3.64 mA，同时 AC Reff 仍为 1.054Ω，误差约 5.5%。
- `Rtarget≈7.2Ω` 的 DC 偏置从约 12.28 mA 降到约 7.92 mA，AC Reff 仍为 7.25Ω。
- `Rtarget≈100Ω` 不适合强行使用这组 low-R trim/servo，因此加入 `FIXW(RTARGET)` 调度，在高阻区自动淡出；高阻区 AC Reff 保持约 99.07Ω。
- 这三项修复使 fixed-R pure-vendor 链路达到“AC 阻抗有效 + low-R DC 偏置显著降低”的状态，但还不是完整动态 signoff。动态正弦 case 已能跑通，但 `Reff` 简单 LS 指标对时变阻抗不适用，后续应加入 lock-in/frequency-bin 指标。

## 修复前后改善表

| target_ohm | baseline_ac_reff_ohm | final_ac_reff_ohm | baseline_abs_dc_iport_mA | final_abs_dc_iport_mA | dc_iport_reduction_pct | baseline_abs_vcmd_mV | final_abs_vcmd_mV | ac_error_final_ohm | status |
|---:|---:|---:|---:|---:|---:|---:|---:|---:|:---|
| 1 | 1.04765 | 1.05444 | 41.9889  | 3.64045 | 91.33 | 304.444  | 23.6609 | 0.0551767 | pass_ac; dc_improved |
| 7.2 | 7.24896 | 7.24996 | 12.2788  | 7.92373 | 35.4684 | 85.7337 | 54.5022 | 0.0513817 | pass_ac; dc_improved |
| 100 | 99.0674  | 99.0719  | 6.87305 | 6.87814 | -0.0740885 | 47.4479 | 46.9722 | -0.916427  | pass_ac; high-R uses scheduled fix-off, dc unchanged |

## 关键 case 数据

| case | status | rtarget_tail_mean_ohm | reff_fit_ac_tail_ohm | reff_fit_ac_err_vs_tail_mean_ohm | dc_iport_tail_a | dc_vcmd_tail_v | dc_vspk_tail_v | iport_pk_tail_a | follow_error_rms_tail_v | ilim_ratio_tail_pk | xmax_ratio_pk | vos_i_trim | dc_servo_fc | dc_servo_k | fix_sched_enable | fix_sched_full | fix_sched_off | zservo_mean_tail |
|:---|:---|---:|---:|---:|---:|---:|---:|---:|---:|---:|---:|---:|---:|---:|---:|---:|---:|---:|
| rcl_only_r1p0 | ok | 0.999262 | 1.04765  | 0.0483852 | -0.0419889  | 0.304444  | 0.306976  | 0.0457285  | 0.00253199 | 0.0300845  | 0.0204006 |  0 | 20 | 0 | nan | nan | nan | 0 |
| vos_trim_only_r1p0 | ok | 0.999262 | 1.05221  | 0.0529519 | -0.0168428  | 0.119381  | 0.121923  | 0.0182307  | 0.00254283 | 0.0119939  | 0.00313146  | -0.000496092 | 20 | 0 | nan | nan | nan | 0 |
| scheduled_slowfc2_k0p2_r1p0 | ok | 0.999262 | 1.05444  | 0.0551767 | -0.00364045 | 0.0236609 | 0.026212  | 0.00466339 | 0.00255115 | 0.00306802 | 0.00777821  | -0.000496092 | 2 | 0.2 | 1 | 7.2 | 30 | -0.00072809  |
| rcl_only_r7p2 | ok | 7.19858  | 7.24896  | 0.0503767 | -0.0122788  | 0.0857337 | 0.0882791 | 0.0129372  | 0.00254532 | 0.00851133 | 0.000390026 |  0 | 20 | 0 | nan | nan | nan | 0 |
| vos_trim_only_r7p2 | ok | 7.19858  | 7.24895  | 0.0503761 | -0.012312 | 0.0859728 | 0.0885181 | 0.0129704  | 0.00254531 | 0.00853318 | 0.000390256 | -0.000496092 | 20 | 0 | nan | nan | nan | 0 |
| scheduled_slowfc2_k0p2_r7p2 | ok | 7.19858  | 7.24996  | 0.0513817 | -0.00792373 | 0.0545022 | 0.0570501 | 0.00859792 | 0.00254793 | 0.00565653 | 0.000358467 | -0.000496092 | 2 | 0.2 | 1 | 7.2 | 30 | -0.00158471  |
| rcl_only_r100p0 | ok | 99.9883 | 99.0674 | -0.92091 | -0.00687305 | 0.0474479 | 0.0499966 | 0.00696984 | 0.00254871 | 0.00458542 | 0.0053663 |  0 | 20 | 0 | nan | nan | nan | 0 |
| vos_trim_only_r100p0 | ok | 99.9883 | 99.0836 | -0.904776  | -0.0114755  | 0.0803887 | 0.0829346 | 0.011573 | 0.00254589 | 0.00761378 | 0.0013081 | -0.000496092 | 20 | 0 | nan | nan | nan | 0 |
| scheduled_slowfc2_k0p2_r100p0 | ok | 99.9883 | 99.0719 | -0.916427  | -0.00687814 | 0.0469722 | 0.0495208 | 0.0069715  | 0.00254862 | 0.00458652 | 0.00143262  | -0.000496092 | 2 | 0.2 | 1 | 7.2 | 30 | 0 |
| scheduled_slowfc2_k0p2_r20p0 | ok | 19.9972 | 20.0196 | 0.0224574 | -0.00915254 | 0.0633491 | 0.0658963 | 0.00952825 | 0.00254715 | 0.00626859 | 0.00136929  | -0.000496092 | 2 | 0.2 | 1 | 7.2 | 30 | -0.00079961  |
| scheduled_slowfc2_k0p2_single_sine_fm100 | ok | 45.937 | -0.132699 | -46.0697 | -0.0067779  | 0.0453356 | 0.0478829 | 0.0106736  | 0.00254742 | 0.00702208 | 0.00158056  | -0.000496092 | 2 | 0.2 | 1 | 7.2 | 30 | -0.000498096 |

## 仍需注意

1. 这三项修复没有彻底把 DC 偏置压到 <1 mA；要达到这个级别，需要再加入 AD633 `c0/cy` feedthrough trim，或者改成闭环阻抗伺服。
2. 当前 DC servo 用的是 `IPORT` 均值反馈，`fc=2Hz` 已低于 10Hz 最低调制频率，但对长期稳定性仍应跑更长时间窗。
3. 高阻区采用调度淡出是必要的；固定全局 trim 会让 100Ω 区 DC 偏置变差。
4. 动态 `Rtarget(t)` 必须用锁相/分频阻抗指标，不能用 fixed-R 的 `V/I` LS 指标直接判定。

## 生成文件

- `complete_fix_curated_comparison.csv`
- `complete_fix_improvement_table.csv`
- `complete_fix_verification_all.csv`
- `complete_fix_verification_key.csv`
- `cases/*/*.cir`, `*.log`, `*.csv`, `*_summary.json`

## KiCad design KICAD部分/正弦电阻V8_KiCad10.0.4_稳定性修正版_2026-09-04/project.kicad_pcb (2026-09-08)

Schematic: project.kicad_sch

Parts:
C1, C2: 10uF; C0805; LCSC Part # C15850
C3, C9, C10, C15, C16, C18, C19, C20, C21, C22, C26: 100nF; C0805; LCSC Part # C49678
C4: 47nF; C0805; LCSC Part # C1845663
C5, C6: 470uF; CAP-SMD_BD10.0-L10.3-W10.3-LS11.3-FD; Manufacturer Part XT470UF35V90RV0080; LCSC Part Name 470uF ±20% 35V
C7, C8: 100nF; C0805; Manufacturer Part CC0805KRX7R9BB104; LCSC Part Name 100nF ±10% 50V
C11, C12, C25, C28: 1uF; C0805; LCSC Part # C344178
C13, C14: 1p/2.2p/4.7p EXP; C0805; not fitted
C17: 10nF; C0805; LCSC Part # C342877
C23: 220nF; C0805; LCSC Part # C45359963
C24: 4.7uF; C0805; LCSC Part # C380342
C27: 10nF; C0805; Manufacturer Part C0805C103J5GACTU; LCSC Part # C2167597
C29, C30: 1uF; C0805; not fitted
C31, C37: 4.7p; C0805; not fitted
C32, C38: 10p; C0805; not fitted
C33, C39: 22p; C0805; not fitted
C34, C40: 47p; C0805; not fitted
C35, C41: 100p; C0805; not fitted
C36, C42: 10p-100p; C0805; not fitted
D1, D2: SS56B; SMB_L4.3-W3.6-LS5.4-RD; LCSC Part # C14651
D3: SS56 +clamp SPK DNP; SMB_L4.3-W3.6-LS5.4-RD; not fitted
D4: SS56 -clamp SPK DNP; SMB_L4.3-W3.6-LS5.4-RD; not fitted
FB1, FB2, FB3: 150R@100MHz; L0805; LCSC Part # C139474
FRAME1: default841x594
J1, J2, J5, J6: WAGO 2060 3P; CONN-SMD_2060-453; Manufacturer Part 2060-453/998-404; LCSC Part Name 1x3P 4mm 每排P数:3 排数:1
J3, J9: WAGO 2060 2P; CONN-SMD_2060-452; Manufacturer Part 2060-452/998-404; LCSC Part Name 1x2P 4mm 每排P数:2 排数:1
J4: WAGO 2060 2P; CONN-SMD_2060-452; Manufacturer Part SPEAKER WAGO 2060 SMT 2P; LCSC Part Name 1x2P 4mm 每排P数:2 排数:1
J7: SWD bare SMT pads; AAI_C11_35_LOCAL_Footprints_AAI_PinHeader_1x05_P1_27mm_Vert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
J8: WAGO 2060 3P; CONN-SMD_2060-453; Manufacturer Part UART bare SMT pads; LCSC Part Name 1x3P 4mm 每排P数:3 排数:1
J10: EXP_SPI_TIM_DNP; AAI_C11_35_LOCAL_Footprints_AAI_PinHeader_1x05_P2_54mm_Vert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; not fitted
J11: EXP_I2C_DAC_DNP; AAI_C11_35_LOCAL_Footprints_AAI_PinHeader_1x05_P2_54mm_Vert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; not fitted
J12, J13: 1×5P 2.54mm母排; HDR-TH_5P-P2.54-V-F; Manufacturer Part 2.54-1*5P母; LCSC Part Name 1x5P 间距:2.54mm 直插
J14: WAGO 2060 1P; CONN-SMD_L12.7-W3.9_2060-451-998-404; Manufacturer Part 2060-451/998-404; LCSC Part Name 1x1P 每排P数:1 排数:1
R1, R2, R42, R43: 0R; R0805; not fitted
R3, R4, R17, R36, R46: 0R; R0805; LCSC Part # C17477
R5, R18: 100R; R0805; LCSC Part # C2988937
R6: 0R; R0805; Manufacturer Part 0805W8F0000T5E; LCSC Part Name 0Ω ±1% 125mW 厚膜电阻
R7: 57.6kR; R0805; LCSC Part # C5153977
R8: 33.2kR 1%; R0805; not fitted
R9: 22.1kR 1%; R0805; not fitted
R10: 6.8kR; R0805; Manufacturer Part 0805W8F6801T5E; LCSC Part # C17772
R11: 1kR; R0805; LCSC Part # C95781
R12: 4.7R 2W; AAI_R_2512_Production_4R7_2W; Manufacturer Part CRH2512F4R70E04S; LCSC Part # C2897629
R13, R15: 1.000kR; R0805; LCSC Part # C110774
R14: 49.9kR; R0805; LCSC Part # C1730568
R16: 39.0kR; R0805; LCSC Part # C1720356
R19: 30.9kR; R0805; LCSC Part # C865394
R20, R21, R22, R35: 10.0kR; R0805; LCSC Part # C110775
R23: 100kR; R0805; LCSC Part # C2907217
R24: 10kR; R0805; LCSC Part # C2907219
R25: 6.49kR 0.1%; R0805; not fitted
R26, R31: 10k; R0805; not fitted
R27, R30: 100k; R0805; not fitted
R28: 100kR ±1%; R0805; not fitted
R29: 10kR ±1%; R0805; not fitted
R32, R33: 360kR ±1%; R0805; not fitted
R34: 1.000MR; R0805; LCSC Part # C2075448
R37, R38, R40: 1MR; R0805; not fitted
R39: 10kR; R0805; not fitted
R41: 10MR; R0805; not fitted
R44, R45: 1k-10k; R0805; not fitted
RSH2: 0.100R; AAI_C11_35_LOCAL_Footprints_AAI_SHUNT_4T_3920_Kelvin; LCSC Part # C393067
TP1: TP1; AAI_C11_35_LOCAL_Footprints_AAI_TestPoint_THTPad_D1_5mm_Dri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
TP2: TP2; AAI_C11_35_LOCAL_Footprints_AAI_TestPoint_THTPad_D1_5mm_Dri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
TP3: SENSE_DRV; AAI_C11_35_LOCAL_Footprints_AAI_TestPoint_THTPad_D1_5mm_Dri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
TP4: SENSE_SPK; AAI_C11_35_LOCAL_Footprints_AAI_TestPoint_THTPad_D1_5mm_Dri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
TP5: TP5; AAI_C11_35_LOCAL_Footprints_AAI_TestPoint_THTPad_D1_5mm_Dri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
TP6: TP6; AAI_C11_35_LOCAL_Footprints_AAI_TestPoint_THTPad_D1_5mm_Dri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
TP7: TP7; AAI_C11_35_LOCAL_Footprints_AAI_TestPoint_THTPad_D1_5mm_Dri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
TP8: TP8; AAI_C11_35_LOCAL_Footprints_AAI_TestPoint_THTPad_D1_5mm_Dri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
TP9: TP9; AAI_C11_35_LOCAL_Footprints_AAI_TestPoint_THTPad_D1_5mm_Dri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
TP10: TP10; AAI_C11_35_LOCAL_Footprints_AAI_TestPoint_THTPad_D1_5mm_Dri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
TP11: TP11; AAI_C11_35_LOCAL_Footprints_AAI_TestPoint_THTPad_D1_5mm_Dri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
TP12: TP12; AAI_C11_35_LOCAL_Footprints_AAI_TestPoint_THTPad_D1_5mm_Dri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
TP13: TP13; AAI_C11_35_LOCAL_Footprints_AAI_TestPoint_THTPad_D1_5mm_Dri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
TP14: TP14; AAI_C11_35_LOCAL_Footprints_AAI_TestPoint_THTPad_D1_5mm_Dri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
TP15: TP15; AAI_C11_35_LOCAL_Footprints_AAI_TestPoint_THTPad_D1_5mm_Dri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
TP16: TP16; AAI_C11_35_LOCAL_Footprints_AAI_TestPoint_THTPad_D1_5mm_Dri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
TP17: TP17; AAI_C11_35_LOCAL_Footprints_AAI_TestPoint_THTPad_D1_5mm_Dri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
TP18: TP_VSENSE_RAW; AAI_C11_35_LOCAL_Footprints_AAI_TestPoint_THTPad_D1_5mm_Dri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
TP19: TP_AD633_Z; AAI_C11_35_LOCAL_Footprints_AAI_TestPoint_THTPad_D1_5mm_Dri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
TP20: TP_IPORT; AAI_C11_35_LOCAL_Footprints_AAI_TestPoint_THTPad_D1_5mm_Dri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
TP21: Test-Point-0.5mm
U1: OPA548F/500; TO-263-7_L10.2-W10.4-P1.27-LS14.4-TL; Manufacturer Part OPA548F/500; LCSC Part Name 高压、大电流运算放大器
U2: AD633ARZ-R7; SOIC-8_L4.9-W3.9-P1.27-LS6.0-BL; Manufacturer Part AD633ARZ-R7; LCSC Part Name 四象限模拟乘法器
U3: INA149AIDR; SOIC-8_L4.9-W3.9-P1.27-LS6.0-BL; Manufacturer Part INA149AIDR; LCSC Part Name 高共模电压差分放大器
U4, U8: OPA1656IDR; SOIC-8_L4.9-W3.9-P1.27-LS6.0-BL; Manufacturer Part OPA1656IDR; LCSC Part Name 超低噪声、低失真、FET输入音频运算放大器
U5: STM32G431CBT6; LQFP-48_L7.0-W7.0-P0.50-LS9.0-BL; Manufacturer Part STM32G431CBT6; LCSC Part Name 带DSP和FPU的170MHz主流ARM Cortex-M4 MCU，具有12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
U6: AMS1117-3.3; SOT-223-3_L6.5-W3.4-P2.30-LS7.0-BR; LCSC Part # C6186
U7: TLP185(GR-TPR,E; SOP-6_4P-L3.7-W4.6-P2.54-LS7.0-BL; Manufacturer Part TLP185(GR-TPR,E; LCSC Part Name DC输入 隔离电压(rms):3750V
U9: OPA1656IDR; SOIC-8_L4.9-W3.9-P1.27-LS6.0-BL; not fitted
U10: TMUX7219DGKRQ1; VSSOP-8_L3.0-W3.0-P0.65-LS4.9-BL; not fitted

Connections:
$1N56724: U9.6 (-INB), U9.7 (OUTB)
$1N56728: R23.2, TP21.1, U10.5 (EN)
AD633_Z: R36.1, R37.2, R38.2, TP19.1, U2.4 (Z)
ADC_ISIG: R27.2, U5.8 (PA0)
ADC_PWR_N: R30.2, R31.1, U5.11 (PA3)
ADC_PWR_P: R28.2, R29.1, U5.10 (PA2)
ADC_SPK: R25.2, R26.1, U5.9 (PA1)
ADC_TEMP: J13.4, U5.16 (PB0)
AGND: C9.2, C10.2, C11.2, C12.2, C15.2, C16.2, C17.2, C18.2, C22.2, C23.2, C25.2, C28.2, C29.2, J2.2, J6.2, R3.2, R4.1, R13.2, R15.2, R20.2, R26.2, R36.2, R43.2, TP16.1, U2.2 (Y2), U2.8 (X2), U3.1 (REFB), U3.5 (REFA), U5.19 (VSSA), U9.3 (+INA), U9.5 (+INB), U10.3 (GND), U10.6 (SEL), U10.8 (S2)
ANA_N: C10.1, C12.1, C16.1, FB2.2, TP12.1, U2.3 (-VS), U3.4 (V-), U4.4 (V-), U8.4 (V-), U9.4 (V-), U10.7 (VSS)
ANA_N_EXT: FB2.1, J2.3, R2.2
ANA_P: C9.1, C11.1, C15.1, FB1.2, J6.3, TP11.1, U2.6 (+VS), U3.7 (V+), U4.8 (V+), U8.8 (V+), U9.8 (V+), U10.4 (VDD)
ANA_P_EXT: FB1.1, J2.1, R1.2
DAC_AUX_RAW: J11.5, R35.1, U5.13 (PA5)
DAC_BUF: R17.1, U8.1 (OUTA), U8.5 (+INB)
DAC_BUF_N: R17.2, U8.2 (-INA)
DAC_R_FILT: C17.1, R18.2, U8.3 (+INA)
DAC_R_RAW: R18.1, U5.12 (PA4)
DGND: C1.2, C2.2, C3.2, C19.2, C20.2, C21.2, C24.2, C26.2, J3.2, J7.5, J8.3, J9.2, J11.2, J13.5, R4.2, R29.2, R31.2, U5.23 (VSS), U5.35 (VSS), U5.47 (VSS), U6.1 (ADJ(GND)), U7.3 (CAT)
DRV: D1.2 (A), D2.1 (K), R12.1, R46.2, RSH2.1 (FORCE_DRV), TP2.1
FAULT_IN: J9.1, U5.17 (PB1)
GPIO_SPARE1: J12.1, U5.15 (PA7)
GPIO_SPARE2: J12.2, U5.22 (PB10)
GPIO_SPARE3: J12.3, U5.29 (PB15)
GPIO_SPARE4: J12.4, U5.28 (PB14)
GPIO_SPARE5: J12.5, U5.27 (PB13)
GPIO_SPARE6: J13.1, U5.26 (PB12)
GPIO_SPARE7: J13.2, U5.25 (PB11)
GPIO_SPARE8: J13.3, U5.46 (PB9)
I2C_SCL: J11.3, R33.1, U5.45 (PB8-BOOT0)
I2C_SDA: J11.4, R32.1, U5.44 (PB7)
ILIM_SET: R7.1, R8.1, R9.1, TP10.1, U1.3 (ILIM)
IPORT: C29.1, R39.2, R40.1, TP20.1
ISIG: C13.1, C31.1, C32.1, C33.1, C34.1, C35.1, R14.1, R27.1, R39.1, R44.1, TP5.1, U2.7 (X1), U4.1 (OUTA)
ISIG_TRIM: C28.1, R34.1, R35.2
MCU_OPA_EN: R11.1, U5.14 (PA6)
MUL_RAW: TP7.1, U2.5 (W), U4.5 (+INB)
NRST: C26.1, J7.4, R24.1, U5.7 (PG10-NRST)
OPA_EN_LED_A: R11.2, U7.1 (AN)
OPA_ES: R10.1, TP9.1, U1.7 (E/S), U7.4 (EMI)
OPA_IN_N: R6.2, U1.2 (VIN-)
OPA_IN_P: R5.2, U1.1 (VIN+)
OPA_OUT: R46.1, U1.6 (VO)
PGND: C4.2, C5.1, C6.2, C7.2, C8.1, J1.2, J4.2, R3.1, TP17.1
PWR_N: C6.1, C8.2, C27.2, D2.2 (A), D4.2 (A), J1.3, R2.1, R7.2, R8.2, R9.2, R10.2, R30.1, TP14.1, U1.4 (V-), U1.8 (V-)
PWR_P: C5.2, C7.1, C27.1, D1.1 (K), D3.1 (K), J1.1, R1.1, R28.1, TP13.1, U1.5 (V+), U7.6 (COL)
SENSE_DRV: RSH2.3 (SENSE_DRV), TP3.1, U3.2 (IN-)
SENSE_SPK: RSH2.4 (SENSE_SPK), TP4.1, U3.3 (IN+)
SERVO_INT_N: C30.2, R40.2, R41.2, R42.2, U9.2 (-INA), U10.2 (S1)
SNUB_MID: C4.1, R12.2
SPI_MISO: J10.3, U5.41 (PB4)
SPI_MOSI: J10.4, U5.42 (PB5)
SPI_NSS: J10.1, U5.39 (PA15)
SPI_SCK: J10.2, U5.40 (PB3)
SPK: D3.2 (A), D4.1 (K), J4.1, R6.1, R25.1, RSH2.2 (FORCE_SPK), TP1.1
SWCLK: J7.3, U5.38 (PA14)
SWDIO: J7.2, U5.37 (PA13)
TIM_SYNC: J10.5, U5.30 (PA8)
U4A_LEAD_MID: C36.1, R44.2
U4A_N: C13.2, C31.2, C32.2, C33.2, C34.2, C35.2, C36.2, R13.1, R14.2, R34.2, U4.2 (-INA)
U4B_LEAD_MID: C42.1, R45.2
U4B_N: C14.2, C37.2, C38.2, C39.2, C40.2, C41.2, C42.2, R15.1, R16.2, U4.6 (-INB)
UART_RX: J8.2, U5.32 (PA10)
UART_TX: J8.1, U5.31 (PA9)
V3V3: C2.1, C3.1, C19.1, C20.1, C21.1, C24.1, FB3.1, J7.1, J11.1, R23.1, R24.2, R32.2, R33.2, TP15.1, U5.1 (VBAT), U5.24 (VDD), U5.36 (VDD), U5.48 (VDD), U6.2 (VOUT), U6.4 (VOUT)
V3V3A: C22.1, C23.1, C25.1, FB3.2, R19.1, U5.20 (VREF+), U5.21 (VDDA)
V5_IN: C1.1, J3.1, U6.3 (VIN)
VCMD: C14.1, C37.1, C38.1, C39.1, C40.1, C41.1, R5.1, R16.1, R45.1, TP8.1, U4.7 (OUTB)
VK: J5.2, TP6.1, U2.1 (Y1)
VK_AMP_N: R21.1, R22.2, U8.6 (-INB)
VK_EXT: J5.3, J6.1
VK_MCU: J5.1, R22.1, U8.7 (OUTB)
VREF_0V477: C18.1, R19.2, R20.1, R21.2
VSENSE_RAW: TP18.1, U3.6 (VOUT), U4.3 (+INA)
ZSERVO_OUT: C30.1, R38.1, R41.1, R42.1, R43.1, U9.1 (OUTA), U10.1 (D)
ZTRIM: J14.1, J14.2, R37.1

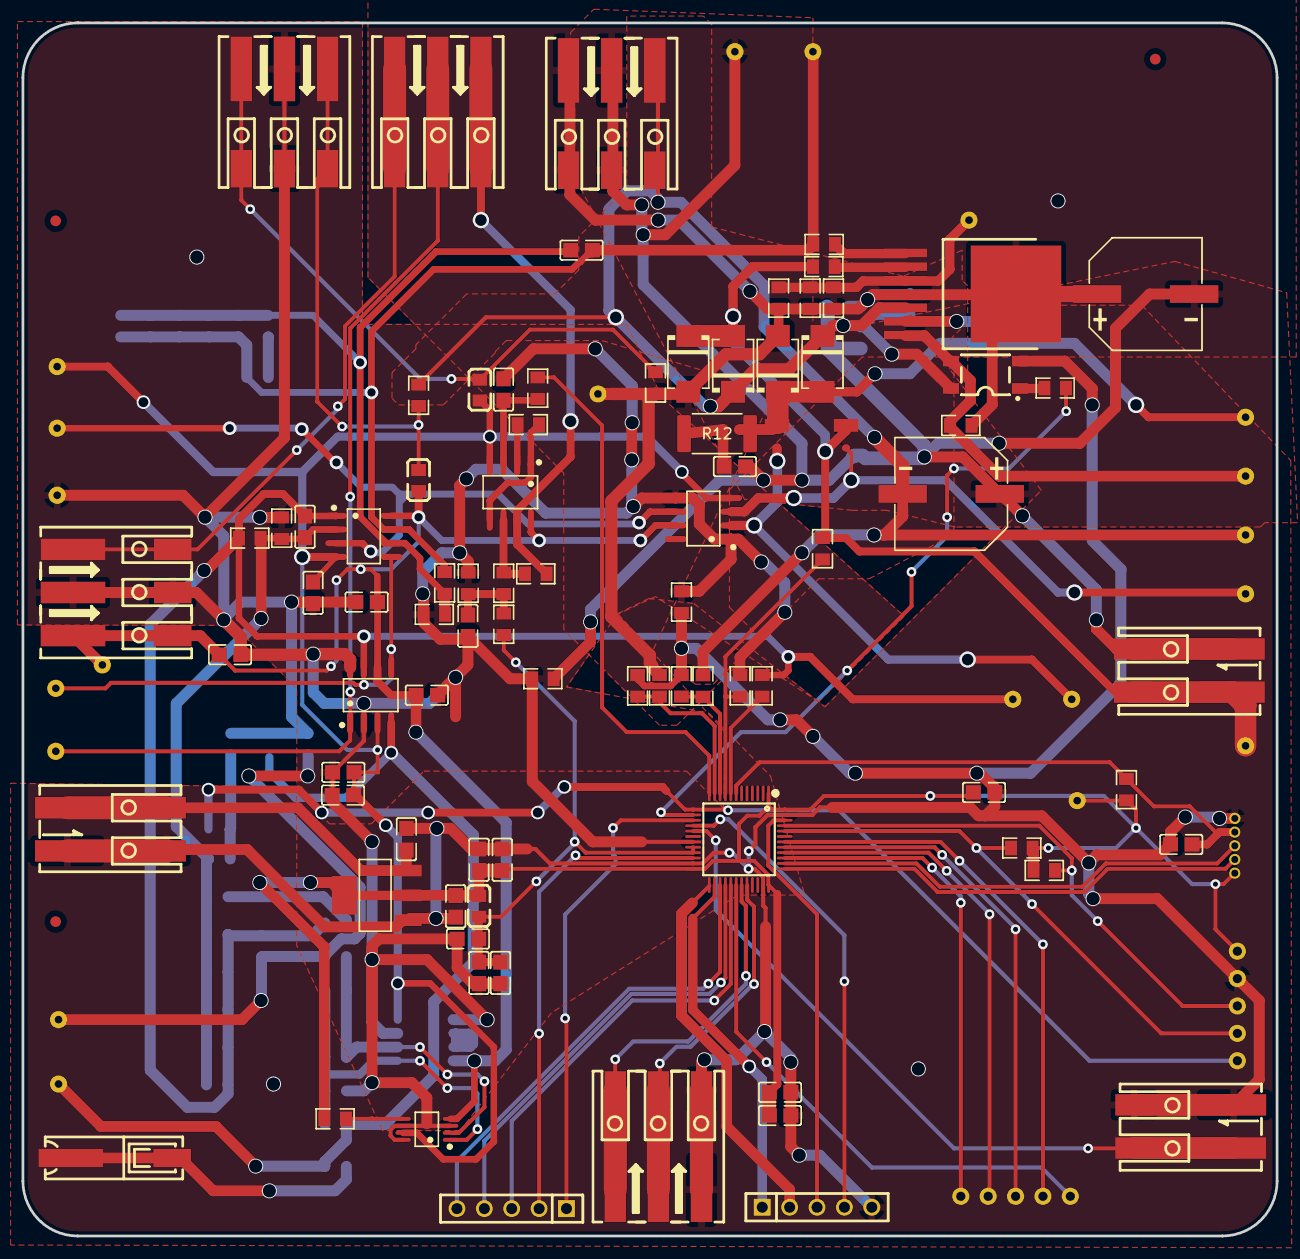
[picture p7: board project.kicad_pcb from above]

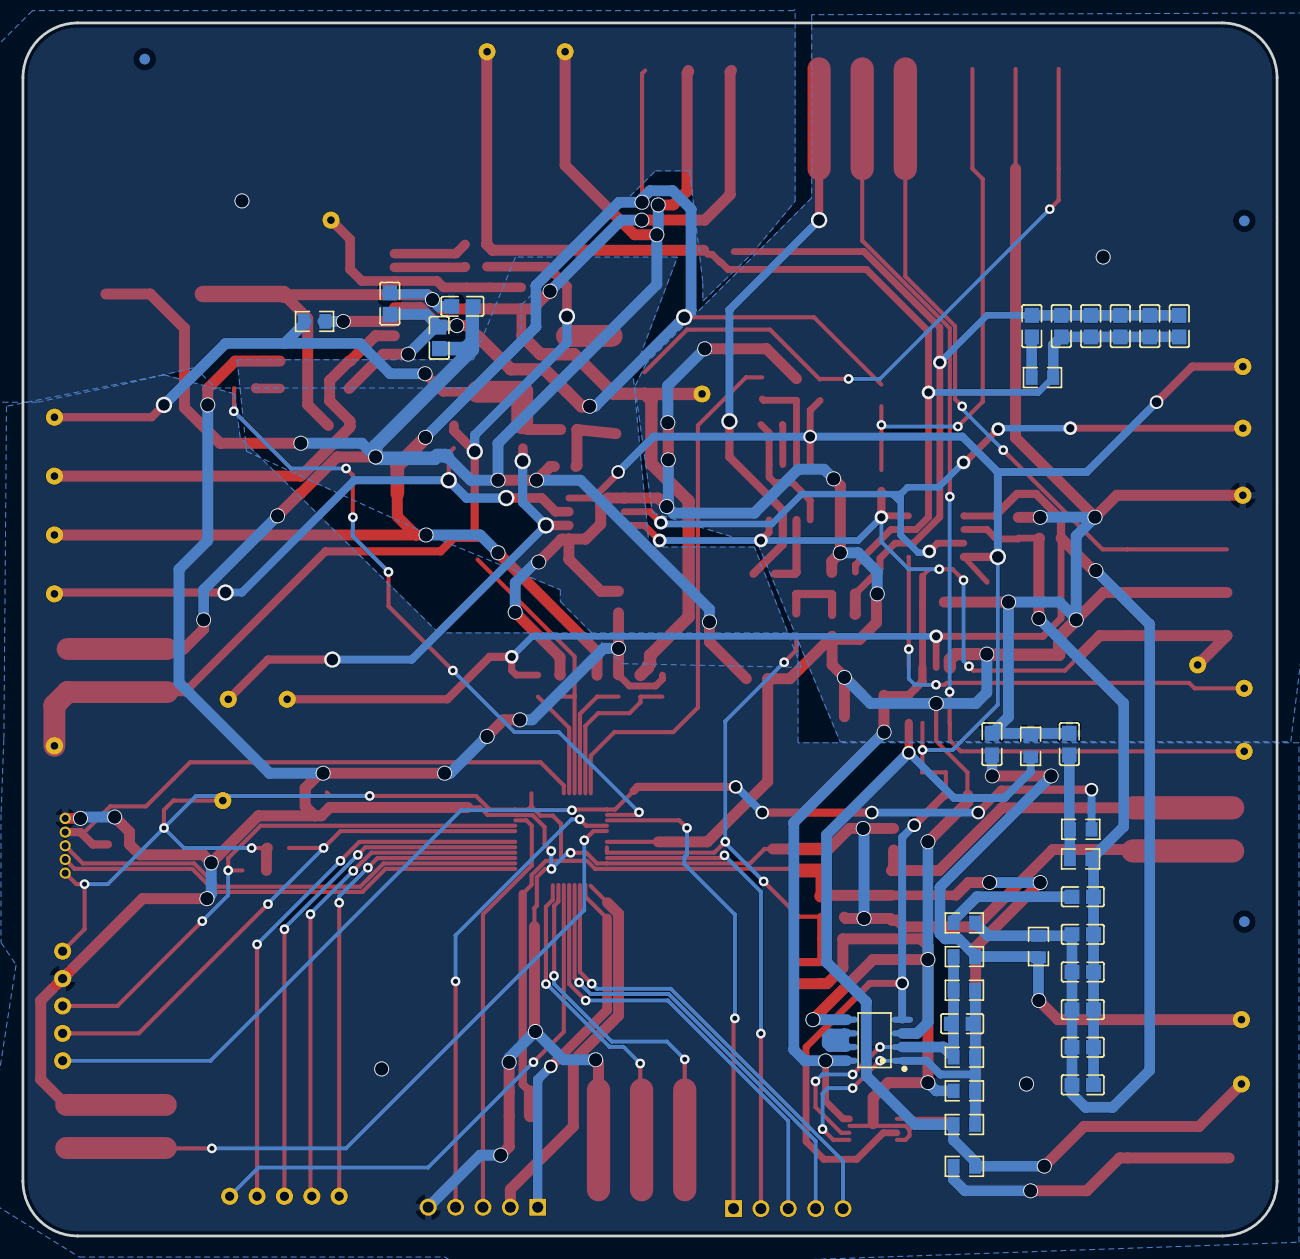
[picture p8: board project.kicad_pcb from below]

Board: 2 copper layers, 116.3 x 112.5 mm, 147 parts (35 on the bottom side), 76 nets.

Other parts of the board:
FID1, FID2, FID3: Fiducial; AAI_Fiducial_1mm_Mask2mm
FID4, FID5, FID6: Fiducial; AAI_Fiducial_1mm_Mask2mm_Bottom

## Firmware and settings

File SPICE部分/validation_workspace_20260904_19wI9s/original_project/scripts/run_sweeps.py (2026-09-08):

#!/usr/bin/env python3
# -*- coding: utf-8 -*-
"""
Run ngspice sweeps for the active acoustic impedance project.

v3 changes:
  1) Soft-started command and acoustic pressure to remove t=0 artifacts.
  2) Electrical current-injection tests with Pamp=0.
  3) Robust metrics: voltage-domain synthesis error, least-squares impedance fit,
     and masked point-wise Reff. Legacy V/I Reff is retained only as a diagnostic.

v3.1 plot-fix changes:
  4) Robust x/y axis limits for all generated PNGs.
  5) Per-case tail-only zoom plots to avoid visually compressed straight-line traces.
  6) Clipped diagnostic Reff plotting; raw CSV values are preserved.

v3.3 Pa-limited sweep changes:
  7) Acoustic stress cases above 5 Pa are removed from the default rerun suite.
     Only Pamp=1 Pa and Pamp=5 Pa stress tests are generated.
"""
from __future__ import annotations

import argparse
import json
import math
import os
import shutil
import subprocess
from dataclasses import dataclass, asdict, replace
from pathlib import Path
from typing import Iterable

import numpy as np
import pandas as pd

import matplotlib
matplotlib.use("Agg")
import matplotlib.pyplot as plt

ROOT = Path(__file__).resolve().parents[1]
NGSPICE_BIN = os.getenv("NGSPICE_BIN", "ngspice")
RESULTS = ROOT / "results"
CASES = RESULTS / "cases"
TEMPLATES = ROOT / "spice" / "circuits"

# Project policy for this v3.3 package: do not generate acoustic stress tests above 5 Pa.
STRESS_PRESSURES_PA = [1, 5]


@dataclass
class SpeakerTS:
    Re: float = 7.2
    Le: float = 0.2e-3
    Bl: float = 4.6
    Mms: float = 5.7e-3
    fs: float = 90.0
    Qms: float = 2.29
    Sd: float = 50e-4
    XMAX: float = 4e-3

    @property
    def w0(self) -> float:
        return 2 * math.pi * self.fs

    @property
    def Cms(self) -> float:
        return 1 / (self.Mms * self.w0 * self.w0)

    @property
    def Rms(self) -> float:
        return self.w0 * self.Mms / self.Qms

    @property
    def Kms(self) -> float:
        return 1 / self.Cms


@dataclass
class SimConfig:
    # Target profile: Rdes = clip(R0 + A1*sin(...) + A2*sin(...), RMIN, RMAX)
    R0: float = 50.5
    A1: float = 49.5
    fm1: float = 100.0
    ph1: float = 0.0
    A2: float = 0.0
    fm2: float = 317.0
    ph2: float = 0.0
    RMIN: float = 1.0
    RMAX: float = 100.0

    # Acoustic pressure excitation.
    Pamp: float = 1.0
    fa: float = 120.0

    # Electrical injection current, injected from ground into SPK.
    ItestAmp: float = 0.0
    ItestFreq: float = 1000.0

    # Soft-start. During the ramp, external Rx is ramped from 0 to Rx_des.
    TSTART: float = 5e-3
    TRAMP: float = 5e-3

    # Transient settings.
    tstop: float = 0.05
    tstep: float = 2e-6

    # Implementation parameters.
    RSH: float = 0.1
    RCL: float = 33.2e3
    IOUT: float = 1.52
    RSNUB: float = 4.7
    CSNUB: float = 47e-9


def sf(x: float) -> str:
    return f"{float(x):.12g}"


def safe(x) -> str:
    return str(x).replace("-", "m").replace(".", "p").replace("+", "")


def mapping(spk: SpeakerTS, cfg: SimConfig, datafile: str) -> dict[str, str]:
    d = {k: sf(v) for k, v in asdict(spk).items()}
    d.update({k: sf(v) for k, v in asdict(cfg).items()})
    d["DATAFILE"] = datafile
    d["MODEL_INCLUDE"] = "../../../spice/models/ngspice_compatible_macros.lib"
    return d


def render(template: str, spk: SpeakerTS, cfg: SimConfig, datafile: str) -> str:
    txt = template
    for k, v in mapping(spk, cfg, datafile).items():
        txt = txt.replace(f"__{k}__", v)
    if "__" in txt:
        raise ValueError("Unreplaced template marker remains in rendered netlist")
    return txt


def check_ngspice() -> str:
    exe = shutil.which(NGSPICE_BIN)
    if not exe:
        raise FileNotFoundError(
            f"ngspice not found. Install ngspice or set NGSPICE_BIN. Current={NGSPICE_BIN!r}"
        )
    r = subprocess.run([NGSPICE_BIN, "-v"], capture_output=True, text=True)
    if r.returncode != 0:
        raise RuntimeError(r.stderr or r.stdout)
    return exe


def read_wrdata(path: Path) -> pd.DataFrame:
    df = pd.read_csv(path, sep=r"\s+", engine="python")
    df.columns = [str(c).lower().strip() for c in df.columns]
    drop = []
    seen = set()
    for c in df.columns:
        if c.startswith("time.") or c.startswith("scale.") or c == "index" or c.startswith("unnamed"):
            drop.append(c)
        elif c in seen:
            drop.append(c)
        else:
            seen.add(c)
    if drop:
        df = df.drop(columns=drop)
    if "time" not in df.columns:
        raise RuntimeError(f"No time column in wrdata output: {path}")
    return df


def finite(a) -> np.ndarray:
    arr = np.asarray(a, dtype=float)
    return arr[np.isfinite(arr)]


def rms(a) -> float:
    b = finite(a)
    return float(np.sqrt(np.mean(b * b))) if b.size else float("nan")


def amin(a) -> float:
    b = finite(a)
    return float(np.min(b)) if b.size else float("nan")


def amax(a) -> float:
    b = finite(a)
    return float(np.max(b)) if b.size else float("nan")


def amean(a) -> float:
    b = finite(a)
    return float(np.mean(b)) if b.size else float("nan")


def _finite_concat(series_list: Iterable) -> np.ndarray:
    vals = []
    for s in series_list:
        if s is None:
            continue
        try:
            arr = np.asarray(s, dtype=float).ravel()
        except Exception:
            continue
        arr = arr[np.isfinite(arr)]
        if arr.size:
            vals.append(arr)
    if not vals:
        return np.array([], dtype=float)
    return np.concatenate(vals)
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

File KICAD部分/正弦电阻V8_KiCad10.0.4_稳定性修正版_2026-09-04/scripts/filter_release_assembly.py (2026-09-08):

#!/usr/bin/env python3
"""Create mutually consistent SMT BOM/CPL files from KiCad exports."""
from pathlib import Path
import csv

ROOT = Path(__file__).resolve().parents[1]
ASSEMBLY = ROOT / "release" / "V8_2026-09-04" / "assembly"

def read(name):
    with (ASSEMBLY / name).open(encoding="utf-8-sig", newline="") as f:
        return list(csv.DictReader(f))

def write(name, rows, fields):
    with (ASSEMBLY / name).open("w", encoding="utf-8-sig", newline="") as f:
        out = csv.DictWriter(f, fieldnames=fields, quoting=csv.QUOTE_MINIMAL)
        out.writeheader(); out.writerows(rows)

bom_all = read("BOM_all.csv")
cpl_all = read("CPL_all.csv")
bom_smt = [row for row in bom_all if row["Assembly Status"].strip().upper() == "SMT"]
smt_refs = {row["Refs"] for row in bom_smt}
cpl_by_ref = {row["Ref"]: row for row in cpl_all}

missing = sorted(smt_refs - cpl_by_ref.keys())
extra = sorted(cpl_by_ref.keys() - smt_refs)
if missing:
    raise SystemExit(f"SMT BOM references missing from CPL: {missing}")

cpl_smt = [cpl_by_ref[ref] for ref in sorted(smt_refs)]
write("BOM_SMT.csv", bom_smt, list(bom_all[0]))
write("CPL_SMT.csv", cpl_smt, list(cpl_all[0]))

report = ASSEMBLY / "assembly_crosscheck.txt"
report.write_text(
    f"BOM SMT refs: {len(smt_refs)}\n"
    f"CPL SMT refs: {len(cpl_smt)}\n"
    f"Missing from CPL: {missing}\n"
    f"Non-SMT/export-only refs excluded: {extra}\n",
    encoding="utf-8",
)
print(report.read_text(encoding="utf-8"), end="")

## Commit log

2026-09-08 import: add KiCad and SPICE audit sources
    [AB_final_status_table.csv, BOM_PASTER_5720434A_Y17 (1).xls, BOM_PRELIMINARY.csv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]
2026-09-10 analysis: add H12 OPA548 E/S-R5 dynamic coupling audit
    [fast_sweep_summary.csv, official_summary.csv]
2026-09-15 fix: complete fixed-bias H07 audit and tighten diagnosis criteria (#6)
2026-09-15 docs: add new-board bring-up and rework guide (#7)
2026-10-05 feat: add procedural Blender model and renders for V8 PCB (#8)
    [c11_35_v8_pcb_model.blend]
